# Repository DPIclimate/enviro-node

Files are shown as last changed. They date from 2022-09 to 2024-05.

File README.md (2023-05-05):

<h2 align="center">
    Enviro-Node
</h2>
<p align="center">
  <a href="#about">About</a> •
  <a href="https://dpiclimate.github.io/enviro-node" style="target-new: tab;">Documentation</a> •
  <a href="#hardware">Hardware</a> •
  <a href="#license">License</a>
</p>

<p align="center">
    
</p>

<!-- TABLE OF CONTENTS -->
<details>
  <summary>Table of Contents</summary>
  <ol>
    <li>
      <a href="#about">About</a>
    </li>
    <li>
      <a href="#hardware">Hardware</a>
      <ul>
        <li><a href="#microcontroller">Microcontroller</a></li>
        <li><a href="#debug-and-usb-interfaces">Debug and USB Interfaces</a></li>
        <li><a href="#power-distribution">Power Distribution</a></li>
        <ul>
            <li><a href="#battery">Battery</a></li>
            <li><a href="#solar">Solar</a></li>
            <li><a href="#3v3-interface">3V3 Interface</a></li>
            <li><a href="#12v-interface-for-sdi-12-devices">12 V Interface</a></li>
          </ul>
        <li><a href="#peripherals">Peripherals</a></li>
        <ul>
            <li><a href="#io-expander">IO Expander</a></li>
            <li><a href="#piezo-buzzer">Piezo Buzzer</a></li>
            <li><a href="#programmable-button">Programmable Button</a></li>
            <li><a href="#sd-card">SD-Card</a></li>
            <li><a href="#sdi-12">SDI-12</a></li>
            <li><a href="#digital">Digtial (Pulse Counter)</a></li>
        </ul>
        <li><a href="#cat-m1">CAT-M1</a></li>
      </ul>
    </li>
    <li>
      <a href="#firmware">Firmware</a>
    </li>
    <li><a href="#license">License</a></li>
  </ol>
</details>

## About

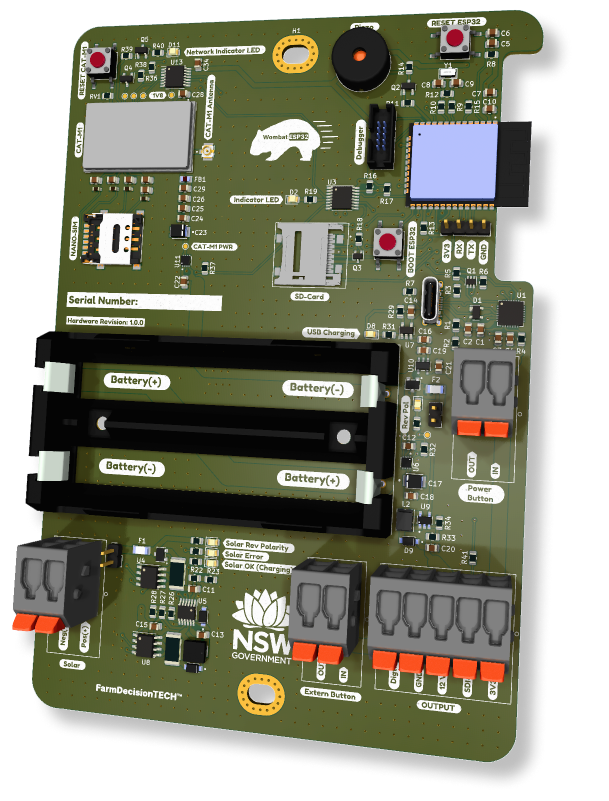
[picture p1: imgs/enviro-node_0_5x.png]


Enviro-node is a environmental monitoring node. Users can connect a number of sensors to a node. Data captured from these sensors is then sent to a database over [MQTT](https://mqtt.org/).

## Hardware

The hardware was developed using [KiCad](https://www.kicad.org/). Source files can be found [here](https://github.com/DPIclimate/enviro-node/tree/master/electronics/motherboard/motherboard-mini). While sleeping the Enviro-node will consume ~70 µA.

### Microcontroller
=> [Schematic](https://github.com/DPIclimate/enviro-node/blob/master/imgs/schematics/microcontroller.pdf)

The device incorporates a ESP32 microcontroller to handle bluetooth functions and peripherals. The ESP32 has a very low sleep current of ~16 µA making it perfect for low-powered applications.

### Debug and USB Interfaces
=> [Schematic](https://github.com/DPIclimate/enviro-node/blob/master/imgs/schematics/microcontroller.pdf)

Enviro-node features full debug capability when connected to an [ESP-Prog](https://espressif-docs.readthedocs-hosted.com/projects/espressif-esp-iot-solution/en/latest/hw-reference/ESP-Prog_guide.html) (ESP32 debugger/programmer). It is recommended that you use a USB-to-TTL cable during development. This allows you to have the ESP-Prog connected to the Enviro-node while monitoring the ESP32's serial output via the USB-to-TTL connector. 

The USB-C interface is only powered up when battery power is available. Do not attempt to power the board with the USB-C interface.

### Power Distribution 
=> [Schematic](https://github.com/DPIclimate/enviro-node/blob/master/imgs/schematics/power_distribution.pdf)

#### Battery

The Enviro-node is powered by two 18650 LiPo cells connected in parallel (4.2 V). A current jumper is available to monitor current and voltage on an external device such as a multi-meter. The batteries feature reverse polarity detection and protection and an inline fuse. 

An INA219 IC is connected to the battery to allow for real-time monitoring of battery current and voltage.

#### Solar

The batteries are recharged through a LT3652IMSE solar charging IC or via a USB-C battery charging IC (MCP73832). The default configuration allows for 12 V solar panels to be connected to the device; however, this can be set via a resistor divider.

The solar input features reverse polarity detection and protection as well as an inline fuse and charging/error indicators.

The charging current of the solar panel is limited to a maximum of 1 A and is monitored through another INA219 IC.

#### 3V3 Interface

Most components on Enviro-node operate using 3.3 V for this a linear regulator is incorporated (XC6215B332MR-G). A power supply switch is connected to the output of this regulator to allow the ESP32 (and peripherals) to be manually turned off or restarted.

#### 12V Interface for SDI-12 Devices

Although many SDI-12 devices will work with 3.3 V, the Enviro-node incorporates a 12 V step-up regulator (MIC2288YD5) to provide a stable 12 V (100 mA) supply. This IC can be toggled in the firmware via a GPIO pin and will be completely shutoff when not in use.

If a SDI-12 sensor requires a constant 12 V supply the current consumption of this step-up regulator is ~2 mA with no load.

### Peripherals
=> [Schematic](https://github.com/DPIclimate/enviro-node/blob/master/imgs/schematics/peripherals.pdf)

#### IO Expander

As a full debug interface is supplied and there are several operating interfaces (I<sub>2</sub>C, SPI, UART) the number of available GPIO pins on the ESP32
is limited. Therefore, an IO-expanded is provided (TCA9534) to control many IC's power consumption including CAT-M1, the SD-Card and 12 V power.

A LED is also connected the IO-expander that the user can configure.

#### Piezo Buzzer

For audible feedback a piezo buzzer is included and will play *success* and *error* tones while the device is being configured and on startup. Under normal conditions the piezo buzzer will be quiet.

#### Programmable Button

An external programmable button is connected to a GPIO input pin on the ESP32. On startup if this button is held down the device will enter a programmable state whereby BluetoothLE will be enabled and a UART CLI interface will become available. Once the user types "exit\r" the CLI will be exited and normal operations will continue.

#### SD-Card

Environmental monitoring requires a SD-Card to ensure data is captured even when communications are down. The Enviro-node provides a top entry, Micro-SD card slot that can be disconnected from its power supply via a GPIO pin (see IO-Expander above).

#### SDI-12

A full SDI-12 interface is provided. No level-shifting is incorporated as the ESP32 can handle 5 V. Users can either use the 12 V output and toggle the output on-and-off or use the 3.3 V output for always on devices.

#### Digital

A digital pin is provided to the user to count pulses originating from a Tipping Bucket or wind-speed sensor.

### CAT-M1
=> [Schematic](https://github.com/DPIclimate/enviro-node/blob/master/imgs/schematics/cat_m1.pdf)

The Enviro-node uses CAT-M1 to send messages (containing JSON encoded data) over MQTT. For this a SARA-R5 modem is incorporated into the design. This modem communicates with the ESP32 microcontroller over AT-commands via a Serial (UART) interface. 

> **Note** A compatible nano-sim card is required for this functionality of the device. For Australian users [Telstra](https://telstra.m2m.com/) has a M2M service or there are other global services such as [Hologram](https://www.hologram.io/products/global-iot-sim-card/).

The modem is directly powered by the 18650 batteries (as the modem can draw ~500 mA) and can be turned off and on via a GPIO pin (see IO-Expander above). A network indicator LED will indicate network registration status.

## Firmware

The firmware source code is located in the <a href="firmware/wombat">firmware/wombat</a> directory. It is structured as a platformio project.

### Installing platformio and the Wombat board files

The <a href="firmware/wombat/install_pio.sh">install_pio.sh</a> script will install platformio and copy the Wombat board files into the installation.

After running the script and adding `~/.platformio/penv/bin` to the PATH, the firmware can be compiled with the command `pio run`.

## License

This project is MIT licensed, as found in the LICENCE file.

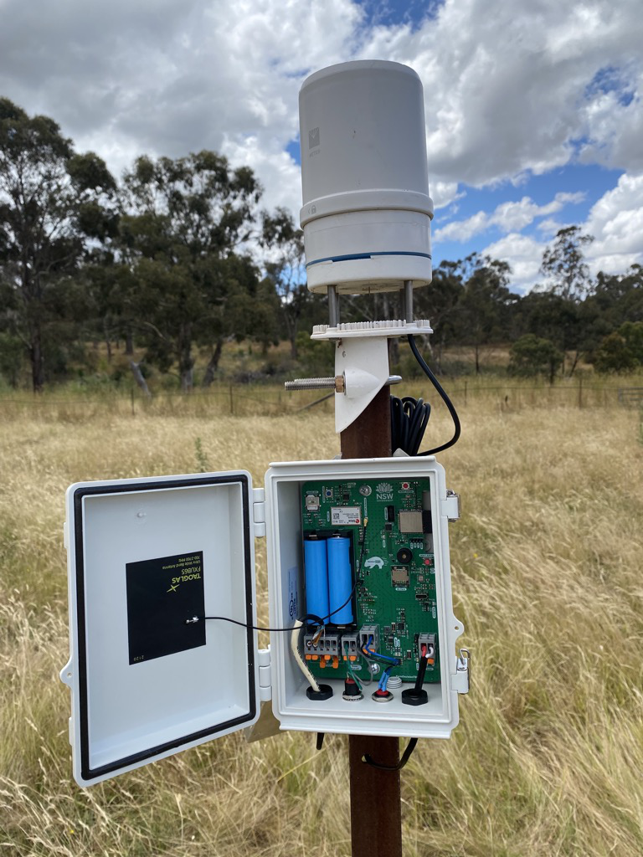
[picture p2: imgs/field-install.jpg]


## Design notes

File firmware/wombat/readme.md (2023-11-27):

# Wombat Firmware

## Overview

The Wombat is a simple data logger whose basic runtime sequence is:

1. Connect to the internet and use NTP to set the time.
2. Read the solar and battery bus voltages.
3. Read all attached SDI-12 sensors with addresses in the range of 0 - 9.
4. Read and reset the pulse count from the `Digital` input.
5. Create a JSON message with these values, plus miscellaneous node information such as the SIM card CCID, basic mobile signal strength, serial number, firmware version etc.
6. Append the message to the `data.json` file on the SD card if the card is present.
7. Write the message to a file on the ESP-32 SPIFFS filesystem.
8. If this is an uplink cycle, send all messages found on the SPIFFS filesystem to an MQTT broker.
9. If a configuration script was received from the MQTT broker, run it.
10. Enter deep sleep until the next measurement cycle.

The firmware is written using the [ESP-32 Arduino platform](https://docs.espressif.com/projects/arduino-esp32/en/latest/getting_started.html)
because Arduino libraries are used. [PlatformIO](https://platformio.org/) is used for building.

The Wombat currently has a 1024 byte limit on the length of the telemetry message. This is sufficient for current
deployments.

## Command Line Interface

Wombats are configured using a command line interface (CLI). This is available via a UART or by publishing a script to
an MQTT topic.

After the output from most commands, the Wombat will print `OK` on success or `ERROR: [optional message]` if a command
fails. The OK/ERROR string is printed on a new line delimited by CRLF, for example: `\r\nOK\r\n`.

## Access the CLI via the USB-C port

To use the command line via the UART header or USB-C port on the Wombat, short the `External Button` header while
rebooting.

The USB-C port does not have both sets of data pins connected, so try the USB-C cable in both orientations.

## Access the CLI via the UART header

The UART header (located just under the ESP32 module) can be used to print console messages from the Wombat. Log
messages are transmitted via the TX.

To enable the RX pin so commands can be entered, break the solder jumper `JP1` on the back of the PCB.

> WARNING: While this jumper is broken the USB-C port will not accept commands, but it will still emit log messages.

## Send CLI commands via MQTT

A Wombat checks for a configuration scrip every time it connects to the MQTT server, using its serial number as the
in the topic name. For example, if the boot messages show:

```text
[    39][I][main.cpp:135] timeout_task(): [wombat] Starting
[  1307][I][DeviceConfig.cpp:66] reset(): [config] Resetting values to defaults
[  1308][I][DeviceConfig.cpp:72] reset(): [config] Node Id: B8D61A017074
[  1310][I][main.cpp:194] setup(): [wombat] Wake up time: 1970-01-01T00:00:18Z
```

then the `Node Id` is `B8D61A017074` and the topic the Wombat will read commands from is `wombat/B8D61A017074`.

If a configuration script is found, the Wombat downloads it and publishes an empty message to the topic to clear the
script.

Configuration scripts must the published as a retained message, meaning the message will persist in the topic until a
new retained message is written to the topic. To clear the configuration script from the topic, an empty message is
published by the Wombat after receiving the configuration script.

> Some commands should not be used in configuration scripts. These commands are marked with `[CLI only]` in the command
> reference below.

Below is an excerpt of the logging messages showing the downloading and clearing of a configuration script from the
MQTT server.

```text
AT+UMQTTC=1

OK
[1884670][I][mqtt_stack.cpp:20] mqttCmdCallback(): [mqtt_stack] cmd: 1, result: 1
[1884697][I][Utils.h:73] hasURC(): [CommandURCVector] valid = 1, command = 1, result = 1, err1 = 0, err2 = 0
[1884715][I][Utils.h:101] waitForURC(): [CommandURCVector] command = 1, result = 1, found_urc = 1, retries = 59
[1884751][I][mqtt_stack.cpp:86] mqtt_login(): [mqtt_stack] Connected to MQTT
AT+UMQTTC=4,1,"wombat/B8D61A017074"

OK
[1884759][I][mqtt_stack.cpp:105] mqtt_login(): [mqtt_stack] Checking for a config script, waiting for subscribe URC
[1885466][I][mqtt_stack.cpp:20] mqttCmdCallback(): [mqtt_stack] cmd: 4, result: 1
[1885485][I][mqtt_stack.cpp:20] mqttCmdCallback(): [mqtt_stack] cmd: 6, result: 1
[1885503][I][Utils.h:73] hasURC(): [CommandURCVector] valid = 1, command = 4, result = 1, err1 = 0, err2 = 0
[1885521][I][Utils.h:101] waitForURC(): [CommandURCVector] command = 4, result = 1, found_urc = 1, retries = 23
[1885539][I][mqtt_stack.cpp:109] mqtt_login(): [mqtt_stack] out of sub urc loop, checking values: result = 1
[1885561][I][Utils.h:73] hasURC(): [CommandURCVector] valid = 1, command = 6, result = 1, err1 = 0, err2 = 0
[1885580][I][Utils.h:101] waitForURC(): [CommandURCVector] command = 6, result = 1, found_urc = 1, retries = 20
[1885598][I][mqtt_stack.cpp:118] mqtt_login(): [mqtt_stack] out of read urc loop, result = 1
[1885616][I][mqtt_stack.cpp:122] mqtt_login(): [mqtt_stack] Config download waiting.
AT+UMQTTC=6,1

+UMQTTC: 6,1,59,19,"wombat/B8D61A017074",40,"ftp login
ftp upload log.txt
ftp logout
"

OK
AT+UMQTTC=2,0,1,0,"wombat/B8D61A017074",""
15:23:26.063 >
OK
```

### Example scripts

A script to upload the data and log files, and then clear the log file:

```
ftp login
ftp upload data.json
ftp upload log.txt
ftp logout
sd rm log.txt
```

A script unconditionally update the firmware and reboot to quickly get a message with the new firmware version
identifier:

```text
config ota 1
config reboot
```

## Command Reference

### config

#### config list

The `config list` command lists various configuration settings as a set of configuration commands that can be pasted
into another Wombats CLI to copy the configuration.

```text
$ config list
interval measure 900
interval uplink 900
interval clockmult 1.0
mqtt host mqtt_server.example.com
mqtt port 1883
mqtt user mqtt_username
mqtt password mqtt_password_in_cleartext
mqtt topic wombat
ftp host ftp_server.example.com
ftp user ftp
ftp password ftp_password_in_cleartext

OK
$
```

#### config save

Saves the configuration to non-volatile storage.

#### config load

Loads the Wombat configuration from non-volatile storage. The configuration must have been saved previously.

#### config dto `[CLI only]`

Disables the 60-minute timeout that will reboot the Wombat if it is still running. This timeout is enabled by default.

#### config eto `[CLI only]`

Enables the 60-minute timeout that will reboot the Wombat if it is still running. This timeout is enabled by default.

#### config ota

Triggers an over-the-air update. By default, this command checks the version on FTP the server and only downloads it if
it is newer than what is running on the Wombat. This can be over-ridden by supplying an argument of '1'.

Example: `config ota 1` force an update of the firmware.

#### config sdi12defn

Downloads the [sdi12defn.json](data/sdi12defn.json) file from the FTP server. No version checking is done, the file is always downloaded and
replaces what is currently on the Wombat.

> See [SDI-12 Sensor Definitions](#sdi-12-sensor-definitions)

#### config reboot

Performs a clean shutdown and reboots the Wombat.

### interval

#### interval list

Lists the interval settings as a set of configuration commands that can be pasted
into another Wombats CLI to copy the configuration.

```text
interval measure 900
interval uplink 900
interval clockmult 1.0
```

#### interval measure

Sets the interval, in seconds, that the Wombat will wake up and record data from the sensors.

Example: `interval measure 900` takes measurements every 15 minutes.

#### interval uplink

Sets the interval, in seconds, that the Wombat will upload data to the MQTT broker. This must be a multiple of
the measurement interval.

Example: `interval uplink 3600` uploads data every hour.

#### interval clockmult

Sets the coefficient used to adjust the sleep time if clock drift is a problem. The time to sleep is calculated in
milliseconds, converted to micro-seconds, and this coefficient is applied to the microsecond value.

Example: `interval clockmult 1.006`

### power

#### power show

Prints the solar and battery voltages.

### sd - work with the SD card

#### sd rm

Deletes a file from the SD card. All files are in the root directory and need no prefix on the name. Only two files
exist on the SD card, `data.json` and `log.txt`. No quotes are required around the filename. Only a single filename may
be supplied.

Example: `sd rm log.txt` will delete the log file.

#### sd data `[CLI only]`

Prints the `data.json` file to the console. The contents are surrounded by `[` and `]` to make it a JSON array.

#### sd log `[CLI only]`

Prints the `log.txt` file to the console.

### sdi12 - work with SDI-12 sensors

#### sdi12 scan

Scans the SDI-12 bus, prints the sensors found and populates the SDI-12 sensor data structure.

#### sdi12 m `[CLI only]`

Performs a measurement on an SDI-12 sensor with the supplied address. If the type of the sensor is in the
`sdi12defns.json` file then the commands and field mask in that file are used, otherwise a measure command is used and
all values are printed.

Example: `sdi12 m 1` reads SDI-12 sensor with address 1 and prints the values.

#### sdi12 >>

Sends a command to the SDI-12 bus and prints the response. The whole argument to this command is sent as the SDI-12
command.

Example: `sdi12 >> 0A8!` changes the address of sensor 0 to 8.

#### sdi12 pt `[CLI only]`

Enters SDI-12 passthrough mode. In this mode all characters typed are sent directly to the SDI-12 bus and all
characters received from the bus are printed to the console.

Exit passthrough mode with ctrl-D.

### c1 - work with the Cat-M1 modem

#### c1 pwr `[CLI only]`

Switches power to the modem on or off. The modem is switched off by default and must be powered before it can be used.
When testing the Wombat from the command line and wanting to use the modem, issue `c1 pwr 1` to supply power to the
modem. `c1 pwr 0` will remove power from the modem, and will issue a power off AT command if a previous `c1 cti`
command was successful.

Example: `c1 pwr 1` switches on the modem power bus.

#### c1 cti `[CLI only]`

Attempts to connect the Wombat to the internet. Will also get the time via NTP. This command will enable power to the
modem the first time it is run.

#### c1 ls

Lists files on the modem filesystem.

#### c1 rm

Deletes a file from the modem filesystem. No quotes are required around the filename. Only a single filename may be
supplied.

Example: `c1 rm wombat.sha1` removes the `wombat.sha1` file from the modem filesystem.

#### c1 factory `[CLI only]`

Attempts to reset the modem to factory defaults using the `AT+UFACTORY=2,2` command.

#### c1 ntp

Issues an NTP request to set the RTC of the Wombat.

#### c1 ok

Issues an `ATI` command and prints the response as a basic modem UART test.

#### c1 pt `[CLI only]`

Enters passthrough mode on the modem UART. In this mode all characters typed are sent directly to the modem and all
characters received from the modem are printed to the console.

Exit passthrough mode with ctrl-D.

### mqtt

#### mqtt list

Lists the MQTT settings as a set of configuration commands that can be pasted
into another Wombats CLI to copy the configuration.

#### mqtt host

Sets the MQTT hostname. A hostname or IPv4 address can be used.

Example: `mqtt hostname mqtt.example.com`

#### mqtt port

Sets the MQTT port number. Must be an integer.

Example: `mqtt port 1883`

#### mqtt user

Sets the MQTT username.

Example: `mqtt user example_user`

#### mqtt password

Sets the MQTT password.

Example: `mqtt password an_example_password`

#### mqtt topic

Sets the name of the topic that test messages sent via `mqtt publish` are published to. Note this setting has no
impact on messages sent from the usual running of the Wombat.

Example: `mqtt topic test_topic`

#### mqtt login

Attempt to log in to a MQTT server using the current configuration settings.

#### mqtt logout

Log out of the MQTT server.

#### mqtt publish

Publish a test message to the MQTT server. The message content is 'ABCDEF' and is published to the topic set with
`mqtt topic`.

### ftp

#### ftp list

Lists the FTP settings as a set of configuration commands that can be pasted
into another Wombats CLI to copy the configuration.

#### ftp host

Sets the FTP hostname. A hostname or IPv4 address can be used.

Example: `ftp hostname ftp.example.com`

#### ftp user

Sets the FTP username.

Example: `ftp user example_user`

#### ftp password

Sets the FTP password.

Example: `ftp password an_example_password`

#### ftp login

Attempt to log in to a FTP server using the current configuration settings.

#### ftp logout

Log out of the FTP server.

#### ftp get

Get a file from the FTP server. The file must be in the root directory of the FTP server.

No quotes are necessary around the filename, and only a single filename is accepted. No whitespace is allowed in the
filename.

The file is written to the modem filesystem.

Example: `ftp get wombat.sha1`

#### ftp upload

Uploads a file from the SD card to the FTP server. The file is written to a directory named `uploads/node_SERIALNO`
where SERIALNO is the Wombat serial number.

No quotes are necessary around the filename, and only a single filename is accepted. No whitespace is allowed in the
filename.

Example: `ftp upload log.txt`

## SDI-12 sensors

### The SDI-12 Bus

Up to 10 SDI-12 sensors may be connected to the Wombat using addresses 0 - 9.

When the Wombat boots it scans the SDI-12 bus for sensors on these addresses and builds a list of the sensors found.
Every sensor on the list is read during the measurement cycle.

SDI-12 Sensors are connected to the `OUTPUT` header and may be powered via the `3V3` line or the `12 V` line. The `3V3`
is powered as long as the batteries are connected via the `Power Button` header, including when the Wombat is asleep.
All SDI-12 sensor data wires must be connected to the `SDI-12` line.

The always-on `3V3` line is useful for sensors such as automatic weather stations which must be always on for recording
rain and wind events.

The `12 V` line is only powered while the Wombat is awake.

### SDI-12 Sensor Definitions

If a file named [`sdi12defns.json`](data/sdi12defn.json) exists on the ESP-32 SPIFFS filesystem, it will be used to
determine which commands to use when reading data from SDI-12 sensors, what labels to give the values, and to
filter unwanted values.

The general layout of the file is:

```json
{
  "vendor": {
    "model": {
      "read_cmds": [ cmd1, ... ],
      "value_mask": "10110",
      "labels": [ "Field_1", ... ],
      "ignore_sr": true
    }
  }
}
```
where:

| Field | Description |
|---|---|
| vendor | The vendor identifier returned by the sensor in the response to an identify command. |
| model | The sensor model identifier returned by the sensor in the response to an identify command. |
| read_cmds  | A list of commands to send to read values. The command must start with `a`, a placeholder for the sensor address,  and end with `!`. For example: `"aC!"` or `"aC2!"`. |
| value_mask | Optional - a string of `0` and `1` which can be used to mask out unwanted values. Use `0` to drop a value. For example: `"110"` drops the 3rd value read from the sensor. |
| labels | A list of names to give the values in the telemetry message. The names are prefixed with the sensor address, so a name of `"Temperature"` will appear in the message as `"1_Temperature"` if it is read from sensor address 1. |
| ignore_sr | Optional - a boolean that can be used to tell the Wombat to always wait for the full length of time the sensor claimed a measurement will take. The Wombat will read and ignore the service request from the sensor. |

> If a sensor definition cannot be found for a sensor, the Wombat issues a basic measure command `aM!`, and labels the
> values `"a_Vn"` where `a` is the sensor address and `n` is the number of the value, from 0 to *n-1* where *n* is the
> number of values read back from the sensor. For example, a temperature and humidity sensor at address 5 would have
> values labelled `5_V0` and `5_V1`.

A new version of the `sdi12defns.json` file can be downloaded from the root directory of the FTP server using the
`config sdi12dfns` command.

## Firmware Updates

The firmware can be updated over-the-air via the `config ota` command.

A binary image named `wombat.bin` and an information file named `wombat.sha1` must must be present in the root
directory of the FTP server.

The information file contains a single line of text with the following fields:

```text
version length firmware-image-sha1-sig git-commit-id
```

for example:

```text
1.0.7 546064 4efb177a5d132ed22e9f045f03e61b9a1d85cacd 7b5b8c08f67312f4c587a83316fbbdc911a5df6d
```

This file is generated by the [split_firmware.sh](split_firmware.sh) script, which is run by [scp_firmware.sh](scp_firmware.sh).

### Uploading Firmware to the FTP Server

The [scp_firmware.sh](scp_firmware.sh) script is used to generate the information file and upload both it and the
firmware image to an FTP server. Note the script uses SSH to copy the files, not FTP.

Two environment variables are used by the script:

| Environment variable | Description |
|---|---|
| SSH_HOST | This variable is expected to contain an SSH host identifier from the ~/.ssh/config file. It may work to set it to something like `-i ~/.ssh/my_key user@host` but this has not been tested. |
| DEST_DIR | The directory on the host to copy the files to. This must equate to the FTP server root directory, for example `/srv/ftp`. |

> The script must be run from the `src/firmware/wombat` directory.

### Requesting a Firmware Update

Issuing a `config ota` command will cause the Wombat to log in to the FTP server, download the `wombat.sha1` file and
use this to check if the software on the server is newer than what is running on the Wombat. If so, the Wombat
downloads and installs the new firmware image and switches over on the next boot.

To force a firmware update issue the `config ota 1` command. This is useful during development when the version number
of the firmware is not changing, or perhaps to downgrade the firmware.

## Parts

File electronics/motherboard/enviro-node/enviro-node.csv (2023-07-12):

Source: | /Users/dtaylor/tmp/enviro-node/electronics/motherboard/enviro-node/enviro-node.kicad_sch
Date: | Wednesday, 19 April 2023 at 02:27:09 pm
Tool: | Eeschema (6.0.11-0)
Generator: | /Applications/KiCad/KiCad.app/Contents/SharedSupport/plugins/bom_csv_grouped_by_value.py
Component Count: | 141
Individual Components:
Item | Qty | Reference(s) | Value | LibPart | Footprint | Datasheet | AVAILABILITY | DESCRIPTION | MANUFACTURER | MAXIMUM_PACKAGE_HEIGHT | MF | MP | PACKAGE | PARTREV | PRICE | Part | SNAPEDA_PACKAGE_ID | STANDARD
 |  | B1 | 1049P | 1049P:1049P | 1049P:1049P
 |  | C3 | 0.1uF | Device:C | Capacitor_SMD:C_0805_2012Metric | https://www.digikey.com.au/en/products/detail/yageo/AC0805KRX7R7BB104/6643148 |  |  |  |  |  |  |  |  |  | AC0805KRX7R7BB104
 |  | C4 | 4.7uF | Device:C | Capacitor_SMD:C_0805_2012Metric | https://www.digikey.com.au/en/products/detail/samsung-electro-mechanics/CL21B475KOFNFNE/3888628 |  |  |  |  |  |  |  |  |  | CL21B475KOFNFNE
 |  | C5 | 1uF | Device:C | Capacitor_SMD:C_0805_2012Metric | https://www.digikey.com.au/en/products/detail/kemet/C0805C105K3RAC7800/2211765 |  |  |  |  |  |  |  |  |  | C0805C105K3RAC7800
 |  | C6 | 0.1uF | Device:C | Capacitor_SMD:C_0805_2012Metric | https://www.digikey.com.au/en/products/detail/yageo/AC0805KRX7R7BB104/6643148 |  |  |  |  |  |  |  |  |  | AC0805KRX7R7BB104
 |  | C7 | 0.1uF | Device:C | Capacitor_SMD:C_0805_2012Metric | https://www.digikey.com.au/en/products/detail/yageo/AC0805KRX7R7BB104/6643148 |  |  |  |  |  |  |  |  |  | AC0805KRX7R7BB104
 |  | C8 | 12pF | Device:C | Capacitor_SMD:C_0805_2012Metric | https://www.digikey.com.au/en/products/detail/vishay-vitramon/VJ0805A120FXJCW1BC/8307136 |  |  |  |  |  |  |  |  |  | VJ0805A120FXJCW1BC
 |  | C9 | 12pF | Device:C | Capacitor_SMD:C_0805_2012Metric | https://www.digikey.com.au/en/products/detail/vishay-vitramon/VJ0805A120FXJCW1BC/8307136 |  |  |  |  |  |  |  |  |  | VJ0805A120FXJCW1BC
 |  | C10 | 22uF | Device:C | Capacitor_SMD:C_0805_2012Metric | https://www.digikey.com.au/en/products/detail/kemet/C0805C226M8PAC7800/5327667 |  |  |  |  |  |  |  |  |  | C0805C226M8PAC7800
 |  | C11 | 10uF | Device:C | Capacitor_SMD:C_0805_2012Metric | https://www.digikey.com.au/en/products/detail/tdk-corporation/C2012X5R1V106K125AC/3951654 |  |  |  |  |  |  |  |  |  | C2012X5R1V106K125AC
 |  | C12 | 1uF | Device:C | Capacitor_SMD:C_0805_2012Metric | https://www.digikey.com.au/en/products/detail/kemet/C0805C105K3RAC7800/2211765 |  |  |  |  |  |  |  |  |  | C0805C105K3RAC7800
 |  | C13 | 1uF | Device:C | Capacitor_SMD:C_0805_2012Metric | https://www.digikey.com.au/en/products/detail/kemet/C0805C105K3RAC7800/2211765 |  |  |  |  |  |  |  |  |  | C0805C105K3RAC7800
 |  | C14 | 4.7uF | Device:C | Capacitor_SMD:C_0805_2012Metric | https://www.digikey.com.au/en/products/detail/samsung-electro-mechanics/CL21B475KOFNFNE/3888628 |  |  |  |  |  |  |  |  |  | CL21B475KOFNFNE
 |  | C15 | 10uF | Device:C | Capacitor_SMD:C_0805_2012Metric | https://www.digikey.com.au/en/products/detail/tdk-corporation/C2012X5R1V106K125AC/3951654 |  |  |  |  |  |  |  |  |  | C2012X5R1V106K125AC
 |  | C16 | 4.7uF | Device:C | Capacitor_SMD:C_0805_2012Metric | https://www.digikey.com.au/en/products/detail/samsung-electro-mechanics/CL21B475KOFNFNE/3888628 |  |  |  |  |  |  |  |  |  | CL21B475KOFNFNE
 |  | C17 | 0.1uF | T520B107M006ATE015:T520B107M006ATE015 | Capacitor_Tantalum_SMD:CP_EIA-2012-12_Kemet-R | https://datasheets.kyocera-avx.com/TAJ.pdf |  |  | KYOCERA-AVX |  |  |  |  |  |  | TAJR104K020RNJ |  | IPC-7351B
 |  | C18 | 2.2uF | Device:C | Capacitor_SMD:C_0805_2012Metric | https://www.digikey.com.au/en/products/detail/kemet/C0805C225M3RAC7800/5267532 |  |  |  |  |  |  |  |  |  | C0805C225M3RAC7800
 |  | C19 | 1uF | Device:C | Capacitor_SMD:C_0805_2012Metric | https://www.digikey.com.au/en/products/detail/kemet/C0805C105K3RAC7800/2211765 |  |  |  |  |  |  |  |  |  | C0805C105K3RAC7800
 |  | C20 | 10uF | Device:C | Capacitor_SMD:C_0805_2012Metric | https://www.digikey.com.au/en/products/detail/tdk-corporation/C2012X5R1V106K125AC/3951654 |  |  |  |  |  |  |  |  |  | C2012X5R1V106K125AC
 |  | C21 | 0.1uF | Device:C | Capacitor_SMD:C_0805_2012Metric | https://www.digikey.com.au/en/products/detail/yageo/AC0805KRX7R7BB104/6643148 |  |  |  |  |  |  |  |  |  | AC0805KRX7R7BB104
 |  | C22 | 1uF | Device:C | Capacitor_SMD:C_0805_2012Metric | https://www.digikey.com.au/en/products/detail/kemet/C0805C105K3RAC7800/2211765 |  |  |  |  |  |  |  |  |  | C0805C105K3RAC7800
 |  | C23 | 0.1uF | T520B107M006ATE015:T520B107M006ATE015 | Capacitor_Tantalum_SMD:CP_EIA-2012-12_Kemet-R | https://datasheets.kyocera-avx.com/TAJ.pdf |  |  | KYOCERA-AVX |  |  |  |  |  |  | TAJR104K020RNJ |  | IPC-7351B
 |  | C24 | 0.1uF | Device:C | Capacitor_SMD:C_0805_2012Metric | https://www.digikey.com.au/en/products/detail/yageo/AC0805KRX7R7BB104/6643148 |  |  |  |  |  |  |  |  |  | AC0805KRX7R7BB104
 |  | C25 | 10nF | Device:C | Capacitor_SMD:C_0805_2012Metric | https://www.digikey.com.au/en/products/detail/kemet/C0805C103J5GEC7210/8645966 |  |  |  |  |  |  |  |  |  | C0805C103J5GEC7210
 |  | C26 | 68pF | Device:C | Capacitor_SMD:C_0805_2012Metric | https://www.digikey.com.au/en/products/detail/kemet/C0805C680K5RACAUTO/11677006 |  |  |  |  |  |  |  |  |  | C0805C680K5RACAUTO
 |  | C27 | 47pF | Device:C | Capacitor_SMD:C_0805_2012Metric | https://www.digikey.com.au/en/products/detail/kemet/C0805C470K5RAC7800/12701183 |  |  |  |  |  |  |  |  |  | C0805C470K5RAC7800
 |  | C28 | 0.1uF | Device:C | Capacitor_SMD:C_0805_2012Metric | https://www.digikey.com.au/en/products/detail/yageo/AC0805KRX7R7BB104/6643148 |  |  |  |  |  |  |  |  |  | AC0805KRX7R7BB104
 |  | C29 | 15pF | Device:C | Capacitor_SMD:C_0805_2012Metric | https://www.digikey.com.au/en/products/detail/kemet/C0805C150J3GAC7800/2211923 |  |  |  |  |  |  |  |  |  | C0805C150J3GAC7800
 |  | C30 | 47pF | Device:C | Capacitor_SMD:C_0805_2012Metric | https://www.digikey.com.au/en/products/detail/kemet/C0805C470K5RAC7800/12701183 |  |  |  |  |  |  |  |  |  | C0805C470K5RAC7800
 |  | C31 | 47pF | Device:C | Capacitor_SMD:C_0805_2012Metric | https://www.digikey.com.au/en/products/detail/kemet/C0805C470K5RAC7800/12701183 |  |  |  |  |  |  |  |  |  | C0805C470K5RAC7800
 |  | C32 | 47pF | Device:C | Capacitor_SMD:C_0805_2012Metric | https://www.digikey.com.au/en/products/detail/kemet/C0805C470K5RAC7800/12701183 |  |  |  |  |  |  |  |  |  | C0805C470K5RAC7800
 |  | C33 | 0.1uF | Device:C | Capacitor_SMD:C_0805_2012Metric | https://www.digikey.com.au/en/products/detail/yageo/AC0805KRX7R7BB104/6643148 |  |  |  |  |  |  |  |  |  | AC0805KRX7R7BB104
 |  | C34 | 0.1uF | Device:C | Capacitor_SMD:C_0805_2012Metric | https://www.digikey.com.au/en/products/detail/yageo/AC0805KRX7R7BB104/6643148 |  |  |  |  |  |  |  |  |  | AC0805KRX7R7BB104
 |  | CR1 | PESD0402-140 | PESD0402-140:PESD0402-140 | PESD0402-140:PESD0402-140 | https://www.digikey.com.au/en/products/detail/littelfuse-inc/PESD0402-140/1968525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 |  |  |  |  |  |  |  |  |  | PESD0402-140
 |  | CR2 | PESD0402-140 | PESD0402-140:PESD0402-140 | PESD0402-140:PESD0402-140 | https://www.digikey.com.au/en/products/detail/littelfuse-inc/PESD0402-140/1968525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 |  |  |  |  |  |  |  |  |  | PESD0402-140
 |  | CR3 | PESD0402-140 | PESD0402-140:PESD0402-140 | PESD0402-140:PESD0402-140 | https://www.digikey.com.au/en/products/detail/littelfuse-inc/PESD0402-140/1968525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 |  |  |  |  |  |  |  |  |  | PESD0402-140
 |  | CR4 | PESD0402-140 | PESD0402-140:PESD0402-140 | PESD0402-140:PESD0402-140 | https://www.digikey.com.au/en/products/detail/littelfuse-inc/PESD0402-140/1968525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 |  |  |  |  |  |  |  |  |  | PESD0402-140
 |  | D1 | SP0503BAHT | Power_Protection:SP0503BAHT | Package_TO_SOT_SMD:SOT-143 | http://www.littelfuse.com/~/media/files/littelfuse/technical%20resources/documents/data%20sheets/sp05xxba.pdf
 |  | D2 | LED(Orange) | Device:LED | LED_SMD:LED_0805_2012Metric | https://www.digikey.com.au/en/products/detail/osram-opto-ams-osram/LO-R976-PS-1/1227955 |  |  |  |  |  |  |  |  |  | LO R976-PS-1
 |  | D3 | LED(Red) | Device:LED | LED_SMD:LED_0805_2012Metric | https://www.digikey.com.au/en/products/detail/osram-opto-ams-osram/LS-R976-NR-1/1227987 |  |  |  |  |  |  |  |  |  | LS R976-NR-1
 |  | D4 | LED(Green) | Device:LED | LED_SMD:LED_0805_2012Metric | https://www.digikey.com.au/en/products/detail/osram-opto-ams-osram/LG-R971-KN-1/1227925 |  |  |  |  |  |  |  |  |  | LG R971-KN-1
 |  | D5 | LED(Red) | Device:LED | LED_SMD:LED_0805_2012Metric | https://www.digikey.com.au/en/products/detail/osram-opto-ams-osram/LS-R976-NR-1/1227987 |  |  |  |  |  |  |  |  |  | LS R976-NR-1
 |  | D6 | SS34LW_RVG | SS34LW_RVG:SS34LW_RVG | SS34LW_RVG:SODFL3718X102N | https://www.digikey.com.au/en/products/detail/taiwan-semiconductor-corporation/SS34LW/7359612 |  |  | Taiwan Semiconductor | 1.02 mm |  |  |  | C2103 |  | SS34LW_RVG |  | IPC-7351B
 |  | D7 | SS34LW_RVG | SS34LW_RVG:SS34LW_RVG | SS34LW_RVG:SODFL3718X102N | https://www.digikey.com.au/en/products/detail/taiwan-semiconductor-corporation/SS34LW/7359612 |  |  | Taiwan Semiconductor | 1.02 mm |  |  |  | C2103 |  | SS34LW_RVG |  | IPC-7351B
 |  | D8 | LED(Green) | Device:LED | LED_SMD:LED_0805_2012Metric | https://www.digikey.com.au/en/products/detail/osram-opto-ams-osram/LG-R971-KN-1/1227925 |  |  |  |  |  |  |  |  |  | LG R971-KN-1
 |  | D9 | SS34LW_RVG | SS34LW_RVG:SS34LW_RVG | SS34LW_RVG:SODFL3718X102N | https://www.digikey.com.au/en/products/detail/taiwan-semiconductor-corporation/SS34LW/7359612 |  |  | Taiwan Semiconductor | 1.02 mm |  |  |  | C2103 |  | SS34LW_RVG |  | IPC-7351B
 |  | D10 | LED(Red) | Device:LED | LED_SMD:LED_0805_2012Metric | https://www.digikey.com.au/en/products/detail/osram-opto-ams-osram/LS-R976-NR-1/1227987 |  |  |  |  |  |  |  |  |  | LS R976-NR-1
 |  | D11 | LED(Orange) | Device:LED | LED_SMD:LED_0805_2012Metric | https://www.digikey.com.au/en/products/detail/osram-opto-ams-osram/LO-R976-PS-1/1227955 |  |  |  |  |  |  |  |  |  | LO R976-PS-1
 |  | F1 | 0685P2000-01 | 0685P2000-01:0685P2000-01 | 0685P2000-01:0685P2000-01 | https://www.digikey.com.au/en/products/detail/bel-fuse-inc/0685P2000-01/12140901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 |  |  | BELFUSE | 0.83mm |  |  |  | Jan2019 |  | 0685P2000-01 |  | IPC-7351B
 |  | F2 | 0685P2000-01 | 0685P2000-01:0685P2000-01 | 0685P2000-01:0685P2000-01 | https://www.digikey.com.au/en/products/detail/bel-fuse-inc/0685P2000-01/12140901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 |  |  | BELFUSE | 0.83mm |  |  |  | Jan2019 |  | 0685P2000-01 |  | IPC-7351B
 |  | FB1 | FBMH2012HM221-TV | FBMH2012HM221-TV:FBMH2012HM221-TV | FBMH2012HM221-TV:BEADC2012X105N | https://www.digikey.com.au/en/products/detail/taiyo-yuden/FBMH2012HM221-TV/4875427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 |  |  |  |  |  |  |  |  |  | FBMH2012HM221-TV
 |  | H1 | MountingHole | Mechanical:MountingHole | MountingHole:MountingHole_4.3x6.2mm_M4_Pad_Via | ~
 |  | H2 | MountingHole | Mechanical:MountingHole | MountingHole:MountingHole_4.3x6.2mm_M4_Pad_Via | ~
 |  | J1 | USB4145-03-0230-C | USB4070-30-C:USB4070-30-C_REVC5 | USB4145-03-0230-C_REVA:GCT_USB4145-03-0230-C_REVA | https://gct.co/files/drawings/usb4145.pdf |  |  | GCT | 10.8mm |  |  |  | C5 |  |  |  | Manufacturer Recommendations
 |  | J2 | JTAG | Connector_Generic:Conn_01x04 | Connector_PinHeader_2.54mm:PinHeader_1x04_P2.54mm_Vertical | ~
 |  | J3 | JTAG | Connector:Conn_ARM_JTAG_SWD_10 | 3221-10-0100-00:CNC_3221-10-0100-00 | http://infocenter.arm.com/help/topic/com.arm.doc.ddi0314h/DDI0314H_coresight_components_trm.pdf |  |  |  |  |  |  |  |  |  | 3221-10-0100-00
 |  | J4 | 2604-3102 | 2604-3102:2604-3102 | 2604-3102:2604-3102 | https://www.digikey.com.au/en/products/detail/wago-corporation/2604-3102/15528152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 |  |  |  |  |  |  |  |  |  | 2604-3102
 |  | J5 | ST1W008S4AR1500 | ST1W008S4AR1500:ST1W008S4AR1500 | ST1W008S4AR1500:JAE_ST1W008S4AR1500 | https://www.digikey.com.au/en/products/detail/jae-electronics/ST1W008S4AR1500/3720055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 |  |  | JAE Electronics | 2.0 mm |  |  |  | 2 |  | ST1W008S4AR1500 |  | Manufacturer Recommendations
 |  | J6 | 2604-3105 | 2604-3105:2604-3105 | 2604-3105:2604-3105 | https://www.digikey.com.au/en/products/detail/wago-corporation/2604-3105/15551087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 |  |  |  |  |  |  |  |  |  | 2604-3105
 |  | J7 | 2604-3102 | 2604-3102:2604-3102 | 2604-3102:2604-3102 | https://www.digikey.com.au/en/products/detail/wago-corporation/2604-3102/15528152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 |  |  |  |  |  |  |  |  |  | 2604-3102
 |  | J8 | SOLAR_CRNT_JMPR | Connector:Conn_01x02_Male | Connector_PinHeader_2.54mm:PinHeader_1x02_P2.54mm_Vertical | ~
 |  | J9 | BAT_CRNT_JMPR | Connector:Conn_01x02_Male | Connector_PinHeader_2.54mm:PinHeader_1x02_P2.54mm_Vertical | ~
 |  | J10 | 2604-3102 | 2604-3102:2604-3102 | 2604-3102:2604-3102 | https://www.digikey.com.au/en/products/detail/wago-corporation/2604-3102/15528152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 |  |  |  |  |  |  |  |  |  | 2604-3102
 |  | J11 | CONUFL001-SMD-T | CONUFL001-SMD-T:CONUFL001-SMD-T | CONUFL001-SMD-T:LINX_CONUFL001-SMD-T | https://www.digikey.com.au/en/products/detail/linx-technologies-inc/CONUFL001-SMD-T/7427732 |  |  | Linx Technologies |  |  |  |  | B |  | CONUFL001-SMD-T |  | Manufacturer Recommendations
 |  | J12 | SIM8060-6-0-14-00-A | SIM8060-6-0-14-00-A:SIM8060-6-0-14-00-A | SIM8060-6-0-14-00-A:GCT_SIM8060-6-0-14-00-A | SIM8060-6-0-14-00-A |  | SIM8060 is a hinged Sim Card Connector. With 6 contacts, with switch for card detection. Profile above PCB is 1.43mm. |  |  | Global Connector Technology | SIM8060-6-0-14-00-A | Package Analog Devices |  |  | SIM8060-6-0-14-00-A
 |  | JP1 | UART TX | Jumper:SolderJumper_2_Bridged | Jumper:SolderJumper-2_P1.3mm_Bridged_RoundedPad1.0x1.5mm | ~
 |  | L1 | SRP4020T-5R6M | pspice:INDUCTOR | SRP4020TA-5R6M:IND_SRP4020TA-5R6M | https://www.bourns.com/docs/Product-Datasheets/SRP4020TA.pdf |  |  |  |  |  |  |  |  |  | SRP4020TA-5R6M
 |  | L2 | LQH43CN100K03L | LQH43CN100K03L:LQH43CN100K03L | LQH43CN100K03L:IND_LQH43CN100K03L | https://www.digikey.com.au/en/products/detail/murata-electronics/LQH43CN100K03L/599911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 |  |  | Murata | 2.8mm |  |  |  | N/A |  | LQH43CN100K03L |  | Manufacturer Recommendations
 |  | LS1 | PS1240P02BT | PS1240P02BT:PS1240P02BT | PS1240P02BT:XDCR_PS1240P02BT | https://www.digikey.com.au/en/products/detail/tdk-corporation/PS1240P02BT/935924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 | Unavailable | Buzzers Transducer, Externally Driven Piezo 3V 4kHz 60dB @ 3V, 10cm Through Hole PC Pins |  | 7.0mm | TDK | PS1240P02CT3 | SIP-5 TDK |  | None | PS1240P02BT
 |  | MOSFET1 | SSM3J340R_LF | SSM3J340R-LF:SSM3J340R_LF | SSM3J340R_LF:SSM3J340R_LF | https://www.digikey.com.au/en/products/detail/toshiba-semiconductor-and-storage/SSM3J340R-LF/10259884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 |  |  |  |  |  |  |  |  |  | SSM3J340R,LF
 |  | MOSFET2 | SSM3J340R_LF | SSM3J340R-LF:SSM3J340R_LF | SSM3J340R_LF:SSM3J340R_LF | https://www.digikey.com.au/en/products/detail/toshiba-semiconductor-and-storage/SSM3J340R-LF/10259884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 |  |  |  |  |  |  |  |  |  | SSM3J340R,LF
 |  | Q1 | MMDT3904 | Transistor_BJT:MMDT3904 | Package_TO_SOT_SMD:SOT-363_SC-70-6 | http://www.diodes.com/_files/datasheets/ds30088.pdf
 |  | Q2 | BC847 | Transistor_BJT:BC847 | Package_TO_SOT_SMD:SOT-23 | http://www.infineon.com/dgdl/Infineon-BC847SERIES_BC848SERIES_BC849SERIES_BC850SERIES-DS-v01_01-en.pdf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
 |  | Q3 | BSS214NW | Transistor_FET:BSS214NW | Package_TO_SOT_SMD:SOT-323_SC-70 | https://www.infineon.com/dgdl/Infineon-BSS214NW-DS-v02_02-en.pdf?fileId=db3a30431b3e89eb011b695aebc01bde
 |  | Q4 | BC847 | Transistor_BJT:BC847 | Package_TO_SOT_SMD:SOT-23 | http://www.infineon.com/dgdl/Infineon-BC847SERIES_BC848SERIES_BC849SERIES_BC850SERIES-DS-v01_01-en.pdf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
 |  | Q5 | BC847 | Transistor_BJT:BC847 | Package_TO_SOT_SMD:SOT-23 | http://www.infineon.com/dgdl/Infineon-BC847SERIES_BC848SERIES_BC849SERIES_BC850SERIES-DS-v01_01-en.pdf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
 |  | R1 | 22.1K | Device:R | Resistor_SMD:R_0805_2012Metric | https://www.digikey.com.au/en/products/detail/bourns-inc/CR0805-FX-1001ELF/3593162 |  |  |  |  |  |  |  |  |  | CR0805-FX-1001ELF
 |  | R2 | 47.5K | Device:R | Resistor_SMD:R_0805_2012Metric | https://www.digikey.com.au/en/products/detail/bourns-inc/CR0805-FX-1001ELF/3593162 |  |  |  |  |  |  |  |  |  | CR0805-FX-1001ELF
 |  | R3 | 5.1K | Device:R | Resistor_SMD:R_0805_2012Metric | https://www.vishay.com/docs/20035/dcrcwe3.pdf |  |  |  |  |  |  |  |  |  | CRCW08055K10FKEA
 |  | R4 | 1K | Device:R | Resistor_SMD:R_0805_2012Metric | https://www.digikey.com.au/en/products/detail/bourns-inc/CR0805-FX-1001ELF/3593162 |  |  |  |  |  |  |  |  |  | CR0805-FX-1001ELF
 |  | R5 | 10K | Device:R | Resistor_SMD:R_0805_2012Metric | https://www.digikey.com.au/en/products/detail/yageo/RC0805FR-0710KP/4935334 |  |  |  |  |  |  |  |  |  | RC0805FR-0710KP
 |  | R6 | 10K | Device:R | Resistor_SMD:R_0805_2012Metric | https://www.digikey.com.au/en/products/detail/yageo/RC0805FR-0710KP/4935334 |  |  |  |  |  |  |  |  |  | RC0805FR-0710KP
 |  | R7 | 5.1K | Device:R | Resistor_SMD:R_0805_2012Metric | https://www.vishay.com/docs/20035/dcrcwe3.pdf |  |  |  |  |  |  |  |  |  | CRCW08055K10FKEA
 |  | R8 | 10K | Device:R | Resistor_SMD:R_0805_2012Metric | https://www.digikey.com.au/en/products/detail/yageo/RC0805FR-0710KP/4935334 |  |  |  |  |  |  |  |  |  | RC0805FR-0710KP
 |  | R9 | 0 | Device:R | Resistor_SMD:R_0805_2012Metric | https://www.digikey.com.au/en/products/detail/bourns-inc/CR0805-J-000ELF/3593157 |  |  |  |  |  |  |  |  |  | CR0805-J/-000ELF
 |  | R10 | 0 | Device:R | Resistor_SMD:R_0805_2012Metric | https://www.digikey.com.au/en/products/detail/bourns-inc/CR0805-J-000ELF/3593157 |  |  |  |  |  |  |  |  |  | CR0805-J/-000ELF
 |  | R11 | 10K | Device:R | Resistor_SMD:R_0805_2012Metric | https://www.digikey.com.au/en/products/detail/yageo/RC0805FR-0710KP/4935334 |  |  |  |  |  |  |  |  |  | RC0805FR-0710KP
 |  | R12 | 10M | Device:R | Resistor_SMD:R_0805_2012Metric | https://www.digikey.com.au/en/products/detail/bourns-inc/CR0805-FW-1005ELF/6153044 |  |  |  |  |  |  |  |  |  | CR0805-FW-1005ELF
 |  | R13 | 10K | Device:R | Resistor_SMD:R_0805_2012Metric | https://www.digikey.com.au/en/products/detail/yageo/RC0805FR-0710KP/4935334 |  |  |  |  |  |  |  |  |  | https://www.digikey.com.au/en/products/detail/yageo/RC0805FR-0710KP/4935334
 |  | R14 | 1K | Device:R | Resistor_SMD:R_0805_2012Metric | https://www.digikey.com.au/en/products/detail/bourns-inc/CR0805-FX-1001ELF/3593162 |  |  |  |  |  |  |  |  |  | CR0805-FX-1001ELF
 |  | R15 | 10K | Device:R | Resistor_SMD:R_0805_2012Metric | https://www.digikey.com.au/en/products/detail/yageo/RC0805FR-0710KP/4935334 |  |  |  |  |  |  |  |  |  | RC0805FR-0710KP
 |  | R16 | 4.7K | Device:R | Resistor_SMD:R_0805_2012Metric | https://www.digikey.com.au/en/products/detail/te-connectivity-passive-product/CRG0805F4K7/2135488 |  |  |  |  |  |  |  |  |  | CRG0805F4K7
 |  | R17 | 4.7K | Device:R | Resistor_SMD:R_0805_2012Metric | https://www.digikey.com.au/en/products/detail/te-connectivity-passive-product/CRG0805F4K7/2135488 |  |  |  |  |  |  |  |  |  | CRG0805F4K7
 |  | R18 | 10K | Device:R | Resistor_SMD:R_0805_2012Metric | https://www.digikey.com.au/en/products/detail/yageo/RC0805FR-0710KP/4935334 |  |  |  |  |  |  |  |  |  | RC0805FR-0710KP
 |  | R19 | 1K | Device:R | Resistor_SMD:R_0805_2012Metric | ~
 |  | R20 | 2K | Device:R | Resistor_SMD:R_0805_2012Metric | https://www.digikey.com.au/en/products/detail/te-connectivity-passive-product/CRG0805F4K7/2135488 |  |  |  |  |  |  |  |  |  | CRG0805F4K7
 |  | R21 | 0.1 | Device:R | Resistor_SMD:R_2512_6332Metric | https://www.digikey.com.au/en/products/detail/bourns-inc/CRL2512-FW-R100ELF/3786041 |  |  |  |  |  |  |  |  |  | CRL2512-FW-R100ELF
 |  | R22 | 21K | Device:R | Resistor_SMD:R_0805_2012Metric | https://www.digikey.com.au/en/products/detail/vishay-dale/CRCW080521K0FKEA/1175785 |  |  |  |  |  |  |  |  |  | CRCW080521K0FKEA
 |  | R23 | 10K | Device:R | Resistor_SMD:R_0805_2012Metric | https://www.digikey.com.au/en/products/detail/yageo/RC0805FR-0710KP/4935334 |  |  |  |  |  |  |  |  |  | RC0805FR-0710KP
 |  | R24 | 2K | Device:R | Resistor_SMD:R_0805_2012Metric | https://www.digikey.com.au/en/products/detail/te-connectivity-passive-product/CRG0805F4K7/2135488 |  |  |  |  |  |  |  |  |  | CRG0805F4K7
 |  | R25 | 2K | Device:R | Resistor_SMD:R_0805_2012Metric | https://www.digikey.com.au/en/products/detail/te-connectivity-passive-product/CRG0805F4K7/2135488 |  |  |  |  |  |  |  |  |  | CRG0805F4K7
 |  | R26 | 180K | Device:R | Resistor_SMD:R_0805_2012Metric | https://www.digikey.com.au/en/products/detail/yageo/RT0805FRE07180KL/1035150 |  |  |  |  |  |  |  |  |  | RT0805FRE07180KL
 |  | R27 | 91K | Device:R | Resistor_SMD:R_0805_2012Metric | https://www.digikey.com.au/en/products/detail/vishay-dale/CRCW080591K0FKEA/1175861 |  |  |  |  |  |  |  |  |  | CRCW080591K0FKEA
 |  | R28 | 330K | Device:R | Resistor_SMD:R_0805_2012Metric | https://www.digikey.com.au/en/products/detail/panasonic-electronic-components/ERJ-6ENF3303V/1746491 |  |  |  |  |  |  |  |  |  | ERJ-6ENF3303V
 |  | R29 | 3.2K | Device:R | Resistor_SMD:R_0805_2012Metric | https://www.digikey.com.au/en/products/detail/vishay-dale/TNPW08053K20BEEA/4972596 |  |  |  |  |  |  |  |  |  | TNPW08053K20BEEA
 |  | R30 | 0.1 | Device:R | Resistor_SMD:R_2512_6332Metric | https://www.digikey.com.au/en/products/detail/bourns-inc/CRL2512-FW-R100ELF/3786041 |  |  |  |  |  |  |  |  |  | CRL2512-FW-R100ELF
 |  | R31 | 1K | Device:R | Resistor_SMD:R_0805_2012Metric | https://www.digikey.com.au/en/products/detail/bourns-inc/CR0805-FX-1001ELF/3593162 |  |  |  |  |  |  |  |  |  | CR0805-FX-1001ELF
 |  | R32 | 100K | Device:R | Resistor_SMD:R_0805_2012Metric | https://www.digikey.com.au/en/products/detail/vishay-dale/CRCW0805100KJNTA/1226893 |  |  |  |  |  |  |  |  |  | CRCW0805100KJNTA
 |  | R33 | 47K | Device:R | Resistor_SMD:R_0805_2012Metric | https://www.digikey.com.au/en/products/detail/vishay-dale/CRCW080547K0FKTA/1223026 |  |  |  |  |  |  |  |  |  | CRCW080547K0FKTA
 |  | R34 | 4.7K | Device:R | Resistor_SMD:R_0805_2012Metric | https://www.digikey.com.au/en/products/detail/te-connectivity-passive-product/CRG0805F4K7/2135488 |  |  |  |  |  |  |  |  |  | CRG0805F4K7
 |  | R35 | 1K | Device:R | Resistor_SMD:R_0805_2012Metric | ~
 |  | R36 | 10K | Device:R | Resistor_SMD:R_0805_2012Metric | https://www.digikey.com.au/en/products/detail/yageo/RC0805FR-0710KP/4935334 |  |  |  |  |  |  |  |  |  | https://www.digikey.com.au/en/products/detail/yageo/RC0805FR-0710KP/4935334
 |  | R37 | 100K | Device:R | Resistor_SMD:R_0805_2012Metric | https://www.digikey.com.au/en/products/detail/vishay-dale/CRCW0805100KJNTA/1226893 |  |  |  |  |  |  |  |  |  | CRCW0805100KJNTA
 |  | R38 | 47K | Device:R | Resistor_SMD:R_0805_2012Metric | ~
 |  | R39 | 10K | Device:R | Resistor_SMD:R_0805_2012Metric | https://www.digikey.com.au/en/products/detail/yageo/RC0805FR-0710KP/4935334 |  |  |  |  |  |  |  |  |  | RC0805FR-0710KP
 |  | R40 | 1K | Device:R | Resistor_SMD:R_0805_2012Metric | ~
 |  | R41 | 0 | Device:R | Resistor_SMD:R_0805_2012Metric | https://www.digikey.com.au/en/products/detail/yageo/RC0805FR-0710KP/4935334 |  |  |  |  |  |  |  |  |  | https://www.digikey.com.au/en/products/detail/yageo/RC0805FR-0710KP/4935334
 |  | RV1 | ESD_RST_IN | Device:Varistor | Resistor_SMD:R_0805_2012Metric | https://www.digikey.com.au/en/products/detail/kyocera-avx/VC080518A400DP/684857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 |  |  |  |  |  |  |  |  |  | VC080518A400DP
 |  | SW1 | BOOT | 2022-10-04_00-56-22:1977223-6 | 1977223-6:1977223-6 | https://www.digikey.com.au/en/products/detail/te-connectivity-alcoswitch-switches/1977223-6/2400488 |  |  |  |  |  |  |  |  |  | 1977223-6
 |  | SW2 | RESET | 2022-10-04_00-56-22:1977223-6 | 1977223-6:1977223-6 | https://www.digikey.com.au/en/products/detail/te-connectivity-alcoswitch-switches/1977223-6/2400488 |  |  |  |  |  |  |  |  |  | 1977223-6
 |  | SW3 | CAT_M1_RST | 2022-10-04_00-56-22:1977223-6 | 1977223-6:1977223-6 | https://www.digikey.com.au/en/products/detail/te-connectivity-alcoswitch-switches/1977223-6/2400488 |  |  |  |  |  |  |  |  |  | 1977223-6
 |  | TP1 | 12V_EN | Connector:TestPoint | TestPoint:TestPoint_Pad_D1.0mm | ~
 |  | TP2 | RX_1V8 | Connector:TestPoint | TestPoint:TestPoint_Pad_D1.0mm | ~
 |  | TP3 | TX_1V8 | Connector:TestPoint | TestPoint:TestPoint_Pad_D1.0mm | ~
 |  | TP4 | PWR_ON | Connector:TestPoint | TestPoint:TestPoint_Pad_D1.0mm | ~
 |  | TP5 | VOUT | Connector:TestPoint | TestPoint:TestPoint_Pad_D1.0mm | ~
 |  | TP6 | 1V8 | Connector:TestPoint | TestPoint:TestPoint_Pad_D1.0mm | ~
 |  | U1 | CP2102N-Axx-xQFN28 | Interface_USB:CP2102N-Axx-xQFN28 | Package_DFN_QFN:QFN-28-1EP_5x5mm_P0.5mm_EP3.35x3.35mm | https://www.silabs.com/documents/public/data-sheets/cp2102n-datasheet.pdf |  |  |  |  |  |  |  |  |  | CP2102N-A02-GQFN28
 |  | U2 | ESP32-WROOM-32E_(16MB) | ESP32-WROOM-32E__16MB_:ESP32-WROOM-32E_(16MB) | ESP32-WROOM-32E__16MB_:XCVR_ESP32-WROOM-32E_(16MB) | https://www.digikey.com.au/en/products/detail/espressif-systems/ESP32-WROOM-32E-N16/11613144 |  |  |  |  |  |  |  |  |  | ESP32-WROOM-32E-N16
 |  | U3 | TCA9534 | Interface_Expansion:TCA9534 | Package_SO:TSSOP-16_4.4x5mm_P0.65mm | https://www.digikey.com.au/en/products/detail/texas-instruments/TCA9534PWR/5004966 |  |  |  |  |  |  |  |  |  | TCA9534PWR
 |  | U4 | INA219BxD | Analog_ADC:INA219BxD | Package_SO:SOIC-8_3.9x4.9mm_P1.27mm | http://www.ti.com/lit/ds/symlink/ina219.pdf |  |  |  |  |  |  |  |  |  | INA219BIDR
 |  | U5 | LT3652IMSE | Battery_Management:LT3652IMSE | Package_SO:MSOP-12-1EP_3x4mm_P0.65mm_EP1.65x2.85mm | https://www.analog.com/media/en/technical-documentation/data-sheets/3652fe.pdf |  |  |  |  |  |  |  |  |  | LT3652IMSE
 |  | U6 | TPS22967DSGR | TPS22967DSGR:TPS22967DSGR | TPS22967DSGR:SON50P200X200X80-9N | https://www.digikey.com.au/en/products/detail/texas-instruments/TPS22967DSGR/4331550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 |  |  |  |  |  |  |  |  |  | TPS22967DSGR
 |  | U7 | MCP73832-2-OT | Battery_Management:MCP73832-2-OT | Package_TO_SOT_SMD:SOT-23-5 | http://ww1.microchip.com/downloads/en/DeviceDoc/20001984g.pdf |  |  |  |  |  |  |  |  |  | MCP73832T-2ACI/OT
 |  | U8 | INA219BxD | Analog_ADC:INA219BxD | Package_SO:SOIC-8_3.9x4.9mm_P1.27mm | http://www.ti.com/lit/ds/symlink/ina219.pdf |  |  |  |  |  |  |  |  |  | INA219BIDR
 |  | U9 | MIC2288YD5-TR | MIC2288YD5-TR:MIC2288YD5-TR | MIC2288YD5-TR:SOT95P280X100-5N | https://www.digikey.com.au/en/products/detail/microchip-technology/MIC2288YD5-TR/1028498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 |  |  | Microchip | 1.0mm |  |  |  | B |  | MIC2288YD5-TR | 8798 | IPC-7351B
 |  | U10 | XC6215B332MR-G | XC6215B332MR-G:XC6215B332MR-G | XC6215B332:XC6215B332MR-G | https://www.digikey.com.au/en/products/detail/torex-semiconductor-ltd/XC6215B332MR-G/2138122 |  |  |  |  |  |  |  |  |  | XC6215B332MR-G
 |  | U11 | TPS22967DSGR | TPS22967DSGR:TPS22967DSGR | TPS22967DSGR:SON50P200X200X80-9N | https://www.digikey.com.au/en/products/detail/texas-instruments/TPS22967DSGR/4331550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 |  |  |  |  |  |  |  |  |  | TPS22967DSGR
 |  | U12 | SARA-R500S-01B | SARA-R410M-02B:SARA-R410M-02B | SARA-R410M-02B:XCVR_SARA-R410M-02B | https://www.digikey.com.au/en/products/detail/u-blox/SARA-R410M-02B/9565822 |  |  |  |  |  |  |  |  |  | SARA-R500S-01B
 |  | U13 | TXB0104PW | Logic_LevelTranslator:TXB0104PW | Package_SO:TSSOP-14_4.4x5mm_P0.65mm | https://www.digikey.com.au/en/products/detail/texas-instruments/TXB0104PWR/1629102 |  |  |  |  |  |  |  |  |  | TXB0104PW
 |  | Y1 | 32.768KHz | ABS07AIG-32.768KHZ-T:ABS07AIG-32.768KHZ-T | ABS07AIG-32:XTAL320X150X90 | https://www.digikey.com.au/en/products/detail/abracon-llc/ABS07AIG-32-768KHZ-T/5817548 |  |  |  |  |  |  |  |  |  | ABS07AIG-32.768KHZ-T
Collated Components:
Item | Qty | Reference(s) | Value | LibPart | Footprint | Datasheet | AVAILABILITY | DESCRIPTION | MANUFACTURER | MAXIMUM_PACKAGE_HEIGHT | MF | MP | PACKAGE | PARTREV | PRICE | Part | SNAPEDA_PACKAGE_ID | STANDARD
1 | 1 | B1 | 1049P | 1049P:1049P | 1049P:1049P
2 | 8 | C3, C6, C7, C21, C24, C28, C33, C34 | 0.1uF | Device:C | Capacitor_SMD:C_0805_2012Metric | https://www.digikey.com.au/en/products/detail/yageo/AC0805KRX7R7BB104/6643148 |  |  |  |  |  |  |  |  |  | AC0805KRX7R7BB104
3 | 3 | C4, C14, C16 | 4.7uF | Device:C | Capacitor_SMD:C_0805_2012Metric | https://www.digikey.com.au/en/products/detail/samsung-electro-mechanics/CL21B475KOFNFNE/3888628 |  |  |  |  |  |  |  |  |  | CL21B475KOFNFNE
4 | 5 | C5, C12, C13, C19, C22 | 1uF | Device:C | Capacitor_SMD:C_0805_2012Metric | https://www.digikey.com.au/en/products/detail/kemet/C0805C105K3RAC7800/2211765 |  |  |  |  |  |  |  |  |  | C0805C105K3RAC7800
5 | 2 | C8, C9 | 12pF | Device:C | Capacitor_SMD:C_0805_2012Metric | https://www.digikey.com.au/en/products/detail/vishay-vitramon/VJ0805A120FXJCW1BC/8307136 |  |  |  |  |  |  |  |  |  | VJ0805A120FXJCW1BC
6 | 1 | C10 | 22uF | Device:C | Capacitor_SMD:C_0805_2012Metric | https://www.digikey.com.au/en/products/detail/kemet/C0805C226M8PAC7800/5327667 |  |  |  |  |  |  |  |  |  | C0805C226M8PAC7800
7 | 3 | C11, C15, C20 | 10uF | Device:C | Capacitor_SMD:C_0805_2012Metric | https://www.digikey.com.au/en/products/detail/tdk-corporation/C2012X5R1V106K125AC/3951654 |  |  |  |  |  |  |  |  |  | C2012X5R1V106K125AC
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

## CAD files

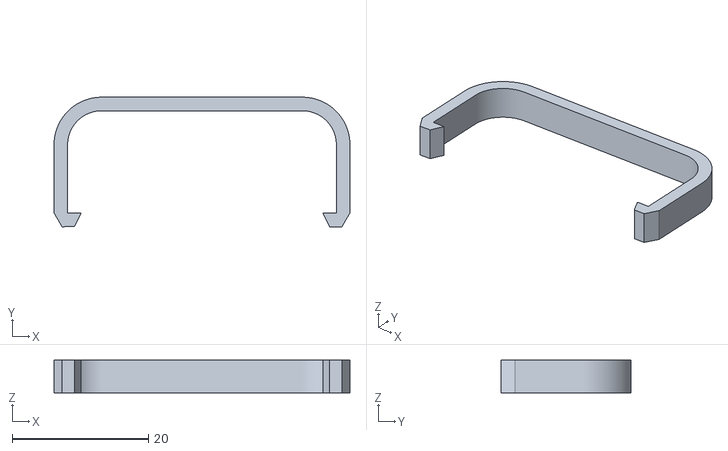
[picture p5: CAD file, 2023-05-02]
cad/Battery holder clip V2.stl
43.5 x 19.1 x 4.80

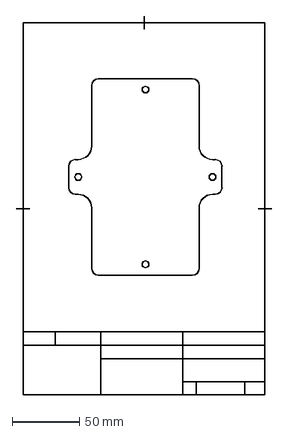
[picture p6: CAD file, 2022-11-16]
electronics/breakout/breakout-box-pcb-outline.dxf
190.0 x 282.0 mm

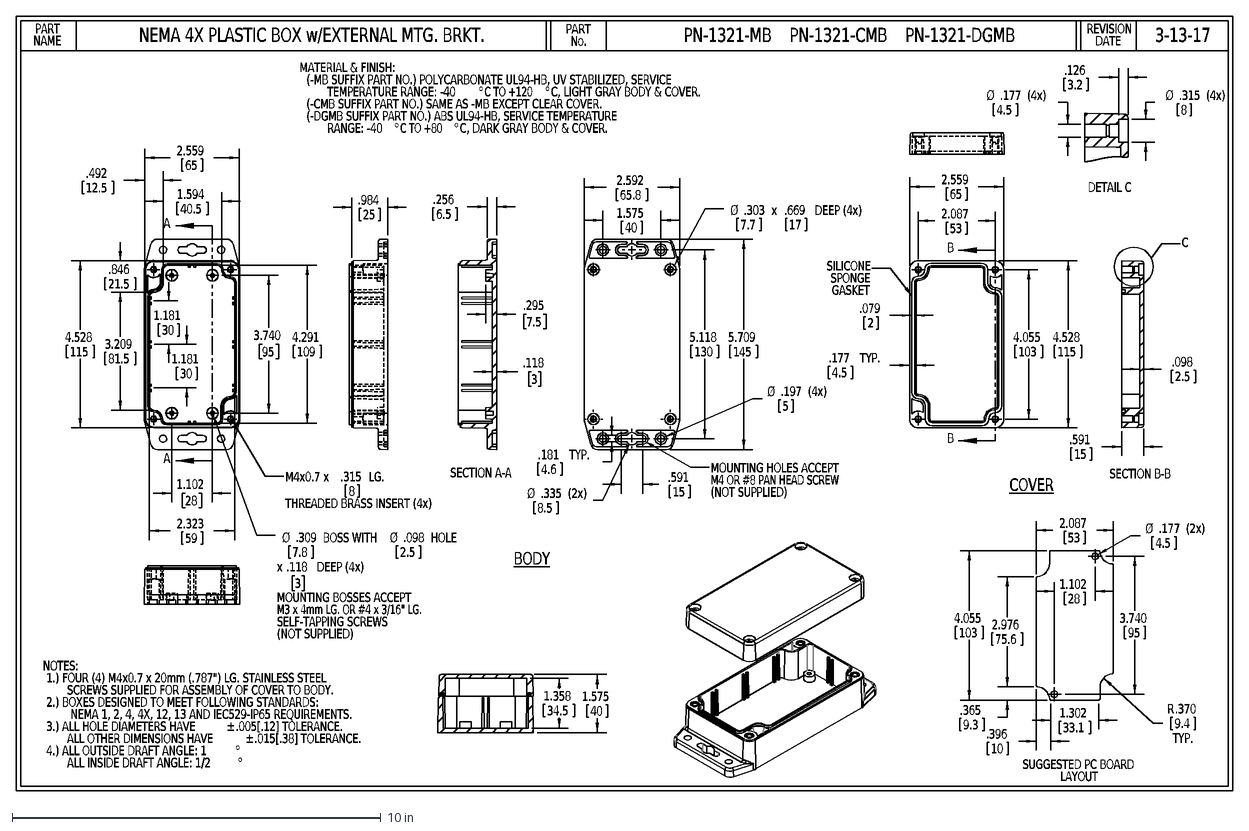
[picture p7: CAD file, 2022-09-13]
electronics/motherboard/enviro-node/board-outlines/bud-ind-type4x-12-13.dxf
SUGGESTED PC BOARD
LAYOUT
BODY
COVER
MATERIAL & FINISH:
(-MB SUFFIX PART NO.) POLYCARBONATE UL94-HB, UV STABILIZED, SERVICE
TEMPERATURE RANGE: -40
°
C TO +120
C, LIGHT GRAY BODY & COVER.
(-CMB SUFFIX PART NO.) SAME AS -MB EXCEPT CLEAR COVER.
(-DGMB SUFFIX PART NO.) ABS UL94-HB, SERVICE TEMPERATURE
RANGE: -40
C TO +80
C, DARK GRAY BODY & COVER.
NOTES:
1.) FOUR (4) M4x0.7 x 20mm (.787") LG. STAINLESS STEEL
SCREWS SUPPLIED FOR ASSEMBLY OF COVER TO BODY.
2.) BOXES DESIGNED TO MEET FOLLOWING STANDARDS:
NEMA 1, 2, 4, 4X, 12, 13 AND IEC529-IP65 REQUIREMENTS.
3.) ALL HOLE DIAMETERS HAVE
±
.005[.12] TOLERANCE.
ALL OTHER DIMENSIONS HAVE
.015[.38] TOLERANCE.
4.) ALL OUTSIDE DRAFT ANGLE: 1
ALL INSIDE DRAFT ANGLE: 1/2
3-13-17
NEMA 4X PLASTIC BOX w/EXTERNAL MTG. BRKT.
PN-1321-MB PN-1321-CMB PN-1321-DGMB
PART
NAME
No.
REVISION
DATE
4.055
103
2.087
53
R
.370
TYP.
9.4
3.740
95
Ø
.177
(2x)
4.5
2.976
75.6
.365
9.3
.396
10
1.302
33.1
1.102
28
1.358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

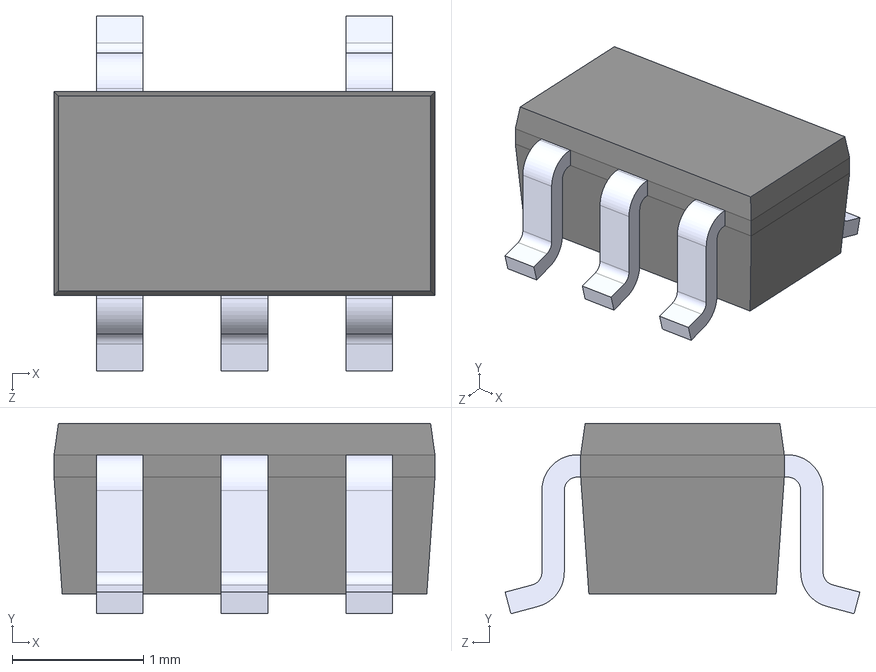
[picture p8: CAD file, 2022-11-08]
electronics/motherboard/enviro-node/parts/adc/MCP3221A0T-E_OT/MCP3221A0T-E_OT.step
2.90 x 1.45 x 2.70 mm

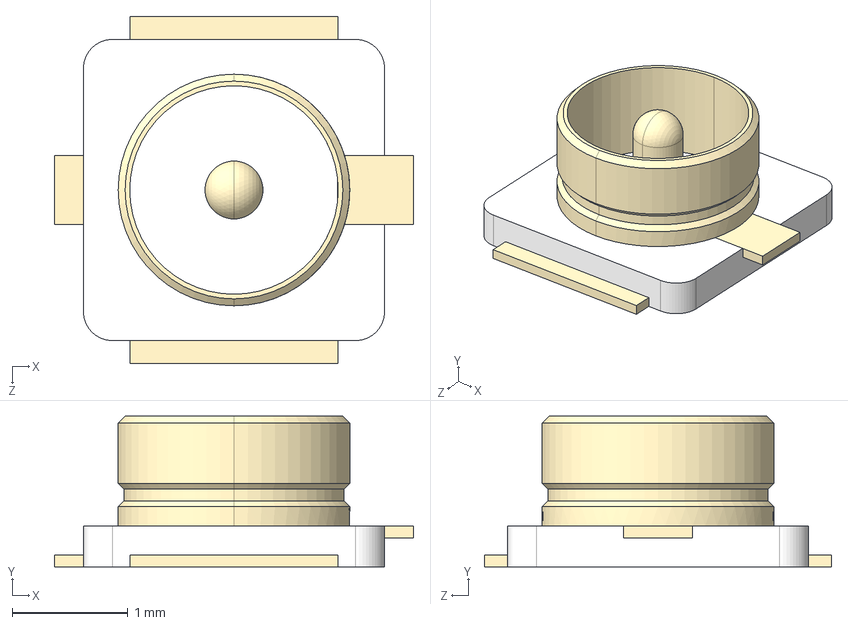
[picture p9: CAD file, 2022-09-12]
electronics/motherboard/enviro-node/parts/antenna/CONUFL001-SMD-T/CONUFL001-SMD-T.step
3.10 x 1.30 x 3.00 mm

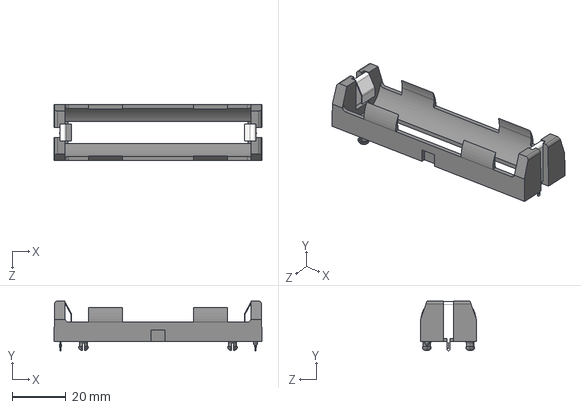
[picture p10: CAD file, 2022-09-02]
electronics/motherboard/enviro-node/parts/battery/holders/18650/1043/1043.step
77.1 x 18.4 x 20.7 mm

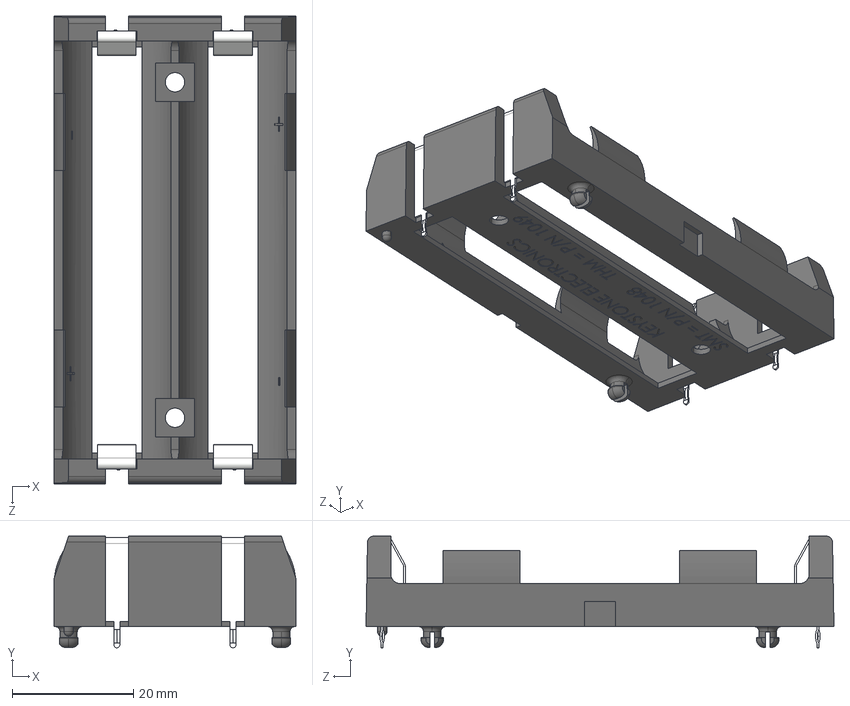
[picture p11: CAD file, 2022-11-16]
electronics/motherboard/enviro-node/parts/battery/holders/18650/1049P/1049P.step
39.8 x 18.4 x 77.1 mm

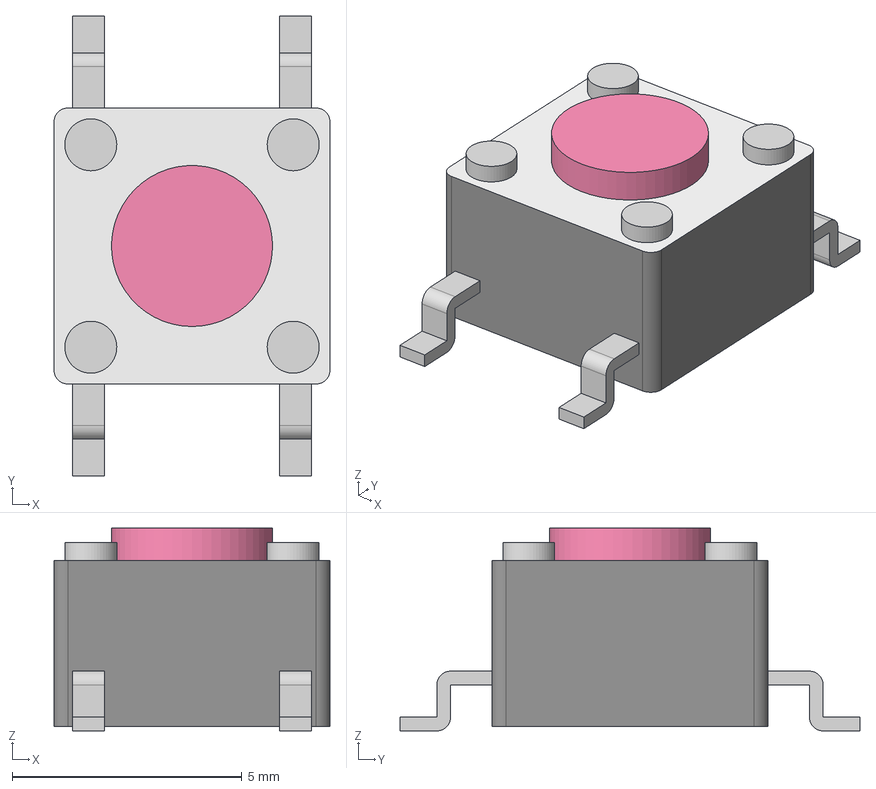
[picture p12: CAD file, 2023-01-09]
electronics/motherboard/enviro-node/parts/buttons/small/1977223-6/c-1977223-6-b-3d.step
6.00 x 10.0 x 4.41 mm

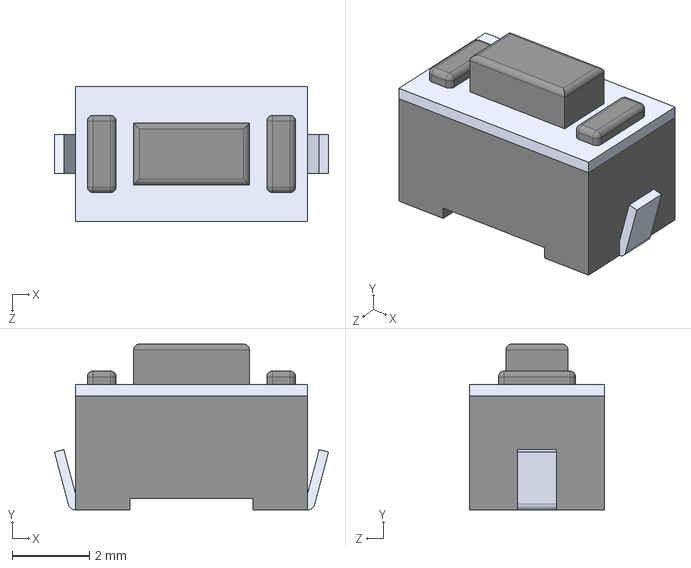
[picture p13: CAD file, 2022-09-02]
electronics/motherboard/enviro-node/parts/buttons/small/PTS636_SM43J_SMTR_LFS/PTS636_SM43J_SMTR_LFS.step
7.10 x 4.30 x 3.50 mm

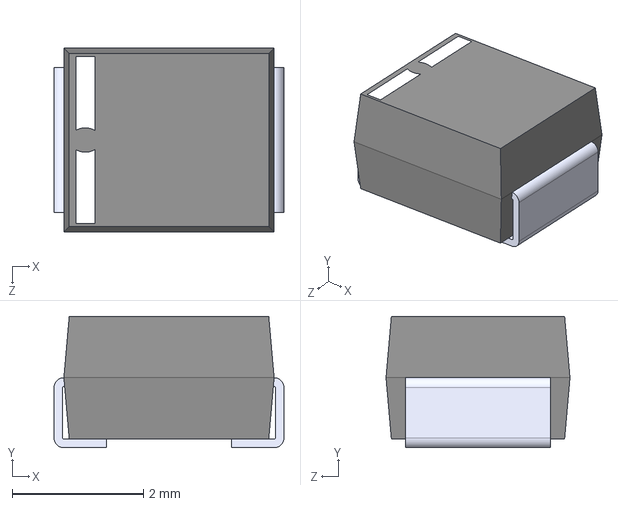
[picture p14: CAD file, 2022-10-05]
electronics/motherboard/enviro-node/parts/capacitors/T520B107M006ATE015/T520B107M006ATE015.step
3.50 x 2.00 x 2.80 mm

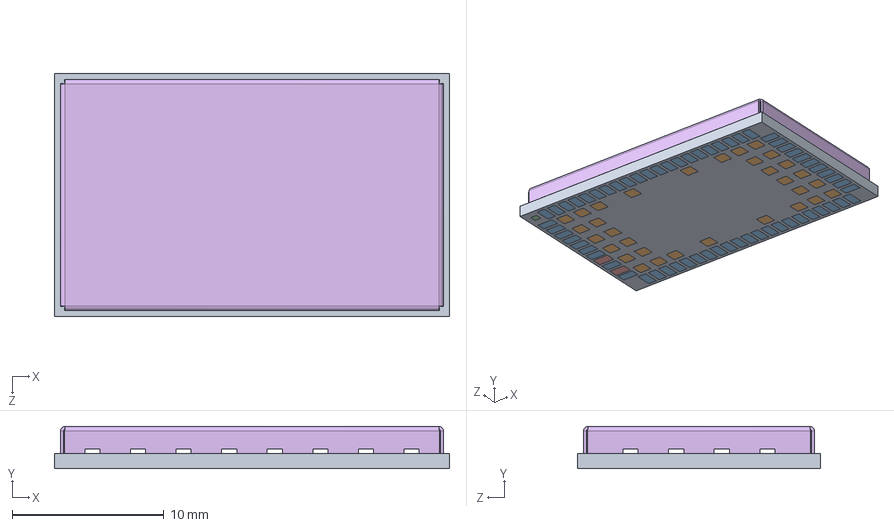
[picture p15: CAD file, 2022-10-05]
electronics/motherboard/enviro-node/parts/comms/cat-m1/SARA-R410M-02B/SARA-R410M-02B.step
26.0 x 2.78 x 16.0 mm

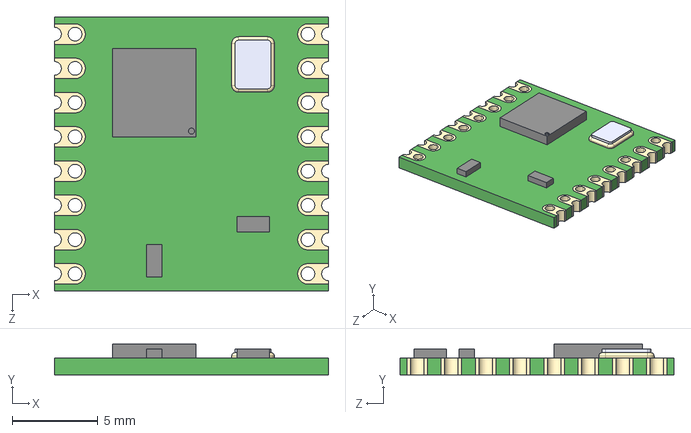
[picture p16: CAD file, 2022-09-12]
electronics/motherboard/enviro-node/parts/comms/lora/RFM95W-915S2/RFM95W-915S2.step
16.0 x 1.80 x 16.0 mm

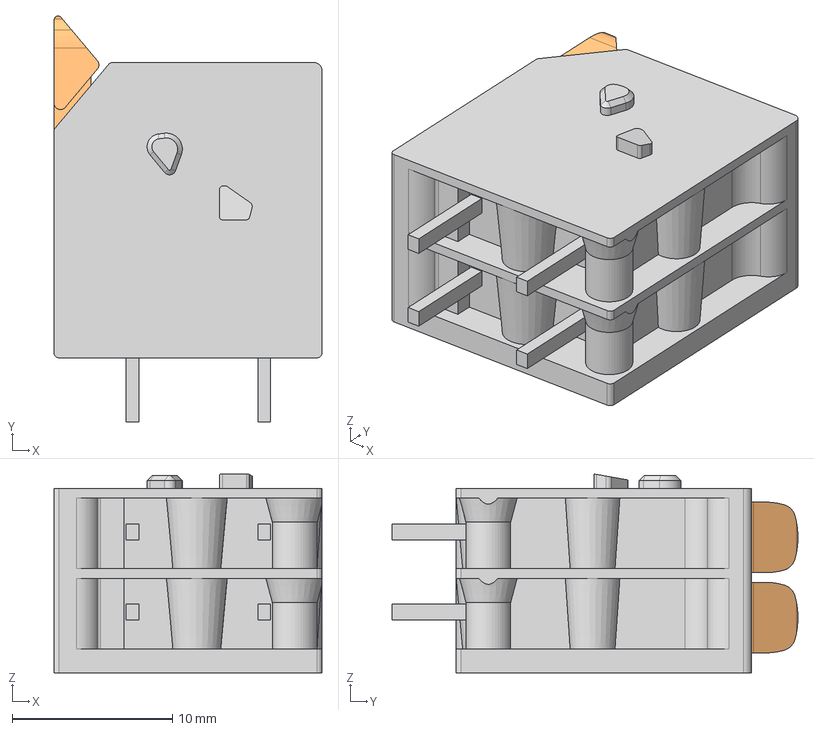
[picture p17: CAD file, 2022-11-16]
electronics/motherboard/enviro-node/parts/connectors/2-pole/2604-3102/2604-3102.stp
16.7 x 25.3 x 12.4 mm

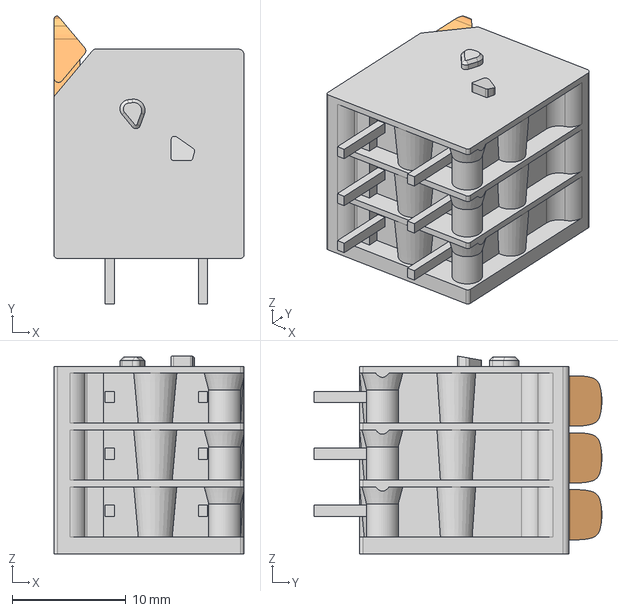
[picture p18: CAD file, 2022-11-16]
electronics/motherboard/enviro-node/parts/connectors/3-pole/2604-3103/2604-3103.stp
16.7 x 25.3 x 17.4 mm

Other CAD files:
electronics/motherboard/enviro-node/parts/connectors/5-pole/2604-3105/2604-3105.stp
electronics/motherboard/enviro-node/parts/connectors/EJ503A/EJ503A.step
electronics/motherboard/enviro-node/parts/connectors/jtag/3221-10-0100-00/3221-10-0100-00.STEP
electronics/motherboard/enviro-node/parts/connectors/nano-sim/SIM8060-6-0-14-00-A/SIM8060-6-0-14-00-A.stp
cad/Breakoutbox holder Final.stl
cad/PVC WB board holder final.stl
cad/long_bracket.f3z
cad/short_bracket.f3z
electronics/breakout/parts/connectors/4-pole/T4041037041-000/T4041037041-000.step
electronics/motherboard/enviro-node/parts/buttons/small/1977223-6/c-1977223-6-b-3d.stp
electronics/motherboard/enviro-node/parts/connectors/3-pole/T4041037031-000/T4041037031-000.step
electronics/motherboard/enviro-node/parts/connectors/PCIe/MDT420B03001/MDT420B03001.step
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

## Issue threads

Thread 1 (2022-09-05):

STM32 debugger

HarveyBates, 2022-09-05:
Need to insuring correct wiring for both:
1. ST-Link/V2 debuggers
2. Six-pin debuggers (like the debugger on a nucleo board)

Resources:
1. https://www.st.com/content/ccc/resource/technical/layouts_and_diagrams/schematic_pack/group2/a4/0a/34/f4/05/88/45/a7/MB1136-DEFAULT-C03_Schematic/files/MB1136-DEFAUL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
2. https://www.st.com/content/ccc/resource/technical/document/user_manual/group1/99/49/91/b6/b2/3a/46/e5/DM00526767/files/DM00526767.pdf/jcr:content/translations/en.DM0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 (Table 6)

HarveyBates, 2022-09-12:
Not required due to design changes

Closed 2022-09-12.

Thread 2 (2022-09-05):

STM32 decoupling capacitors

HarveyBates, 2022-09-05:
See this file:
https://4donline.ihs.com/images/VipMasterIC/IC/SGST/SGST-S-A0004456612/SGST-S-A0004456612-1.pdf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

Page 109 for `Power supply scheme`

HarveyBates, 2022-09-05:
https://au.element14.com/stmicroelectronics/stm32l476mey6tr/mcu-arm-cortex-m4-80mhz-wlcsp/dp/2855729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 potential stm32 micro

HarveyBates, 2022-09-12:
Not required due to design changes

Closed 2022-09-12.

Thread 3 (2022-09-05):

Firmware version in LoRa payload

HarveyBates, 2022-09-05:
A LoRa packet on startup (perhaps at intervals as well) should contain the firmware version (e.g. `v1.0.1`).

Perhaps this should contain firmware from both sensor micro and telemetry micro.

dajtxx, 2022-09-05:
If we make this periodic, such as daily, we can use a confirmed uplink to check the session is still valid.

We could also include known sensor info in this message, based upon an SDI-12 bus query. That won't cover analogue and digital inputs though.

We also need to think how this fits with other transports.

dajtxx, 2023-07-24:
We decided against including LoRaWAN.

Closed 2023-07-24.

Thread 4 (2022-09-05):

On-site node reboot without opening enclosure

dpi-mick, 2022-09-05:
Allow a node to be rebooted by pressing a button on the node enclosure or by holding a magnet against it the enclosure or some other means that doesn't involve opening the enclosure.

The use case here is to allow an on-site person to reboot a node if it's having a problem, has dropped it's cellular connection etc.

The magnet option might be useful if the node enclosure is not easily accessible. e.g. up a tree, on a pole etc.

Audible feedback of reboot would be useful.

HarveyBates, 2022-11-15:
Have external device reboot in next version without opening enclosure with audible feedback.

BEEP BOP! 😀

Closed 2022-11-15.

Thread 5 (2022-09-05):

Allow uplink/downlink of node configuration.

dpi-mick, 2022-09-05:
Allow remote configuration of certain node configuration items. i.e. send new operating parameters to a node already in the field.

Some examples:-

**1/ Change a nodes uplink interval**

**2/ Downlink of SDI-12 configuration to node.**

- Send a set of SDI-12 commands, addresses etc to a node to have it (re)configure it's SDI-12 settings.
- May be able to design hardware to allow the node to change the addresses of connected SDI-12 sensors. i.e. isolating sensors on certain physical connectors. May even map physical connectors to SDI-12 addresses ??!!

**3/ Change MQTT broker details**

**4/ Change cellular APN.**

dajtxx, 2023-03-29:
A set of config commands can be sent to a node by publishing them to the wombat/SERIAL# topic of the MQTT broker.

The Wombat checks for these when it logs into the MQTT broker and runs them immediately.

dajtxx, 2023-05-24:
Downloading the config is sufficient to close this issue. If we want the config reported later we can open a different issue.

Closed 2023-05-24.

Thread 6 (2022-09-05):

Node Maintenance Mode

dpi-mick, 2022-09-05:
Allow a node to be placed into "maintenance" mode, such that it does not uplink data points.

This would allow maintenance actions to take place without impact on data quality. e.g. sensor replacements.

Ideally, the node would still be polling sensors, and may still uplink data, but the uplink message may have a "maintenance" flag so the data received does not get added to the database.

HarveyBates, 2022-11-15:
added external push button that could enable this function, or it may be enabled in the app after pressing the push button

Closed 2022-11-15.

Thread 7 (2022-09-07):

Sensor connectors (Internal or External)

HarveyBates, 2022-09-07:
Continuing from #4, we have two options for connecting sensors to the circuit board:
1. Connections outside the box - don't have to open the box to connect a sensor. Has the disadvantage of longer setup time taken to assemble the board and perhaps higher cost. Has the advantage of not needing to open the enclosure to add a new sensor.
2. Connections inside the box - cables route into the enclosure. Pluggable screw terminals can be used but will require that for a new sensor to be added, the enclosure must be opened.

HarveyBates, 2022-09-20:
Panel mount system could be assembled offsite. Would need a template to drill holes in enclosures. Multiple plugs could allow for individual SDI-12 addresses. Still faces the problem of conflicting addresses on new devices (even though they should all be address 0, some aren't).

Closed 2023-03-29.

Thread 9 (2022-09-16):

External USB Socket

dpi-mick, 2022-09-16:
Include an external USB Socket (with weather cap).

Something like the following (but less costly!!):-

[https://au.element14.com/multicomp-pro/mp002448/usb-type-c-r-a-ip68-sealed-connector/dp/3369657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|pcrid||pkw||pmt||slid||product|3369657|pgrid||ptaid||&CMP=KNC-GAU-GEN-SHOPPING-PLA-PMAX](url)

HarveyBates, 2022-11-15:
cant afford this at this time 😞

Closed 2022-11-15.

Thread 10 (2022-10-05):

Include Serial1 UART header on basic-feather-node

dajtxx, 2022-10-05:
Expose Feather pins RX & TX to a 2-pin header so Serial1 can be used for logging.

This allows logging to be done when running from a battery, and avoids losing the logging connection every time the Feather goes to sleep.

Closed 2022-11-02.

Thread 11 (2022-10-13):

Kangaroo nodes missing messages

dajtxx, 2022-10-13:
A message every few hours seems to be missing from the two first Kangaroo nodes.

Add some jitter to the uplink time and see if that fixes it.

If not add an external antenna and see if that helps.

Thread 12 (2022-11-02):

Kangaroo 12V_EN sharing pin with battery V read pin

dajtxx, 2022-11-02:
The Kangaroo board is using pin D9 (aka A7) to control the voltage booster for SDI-12.

On the Feather, this pin is used to measure the battery voltage via the A2D converter.

We need to move the 12V_EN signal to another pin.

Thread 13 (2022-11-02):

Kangaroo test button is difficult to press when the Serial1 UART headers are installed

dajtxx, 2022-11-02:
The button is sandwiched between the Feather headers and the UART headers and very difficult to press, would be good to have it moved to the opposite side of the board, in the corner near the 2nd SDI-12 header.

Basically, somewhere there isn't a lot of components sitting high above the board surface.

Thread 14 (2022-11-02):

Kangaroo firmware freezes in standby mode

dajtxx, 2022-11-02:
At least one Kangaroo board is freezing when in standby mode.

This was observed on the bench, with the board not having sent a message for over a day and the last log message saying it was going into standby mode. Pressing the test button did not wake the board up, meaning the external interrupt connected to the button was not recognised.

A possible fix is to stop the on chip voltage regulator going to low power mode when the MCU goes into standby mode.

HarveyBates, 2022-11-02:
What size resistors for the pull-up?

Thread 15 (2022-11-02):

Kangaroo UART TX & RX lines need pull-up resistors

dajtxx, 2022-11-02:
At least one Kangaroo board went into command line mode when the test button was pressed due to noise on the RX line when no device was connected. The board should have gone back to sleep in 5 seconds but was stuck in a busy loop waiting for a valid command to be entered with no way to exit command line mode.

A pull-up resistor will pull the line to the idle state by default.

A pull-up on the TX line isn't as necessary, but it may avoid noise characters being sent to a connected device in some circumstances, such as when the node is powered on.

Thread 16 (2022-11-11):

SDI-12 Input Only Pin

HarveyBates, 2022-11-11:
SDI-12 Line is currently on GPIO36, this pin is **INPUT** only.

Change to GPIO27 (12 in package) in next revision.

HarveyBates, 2022-11-15:
completed in next version SDI-12 will be on GPIO21

Closed 2022-11-15.

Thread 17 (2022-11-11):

Push button not accessible over interrupt

HarveyBates, 2022-11-11:
The push button is connected to the TCA9534 IO expander. Change to another pin, perhaps GPIO36 (an input only pin)?

HarveyBates, 2022-11-11:
Also GPIO21 is designated as not connected, this could be used for SDI-12? #16

HarveyBates, 2022-11-11:
correction: the push button is connected to GPIO34
just need to remove it from the TCA9534 list

HarveyBates, 2022-11-15:
completed in next version

Closed 2022-11-15.

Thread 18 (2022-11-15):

SD-Card CS on digital pin

HarveyBates, 2022-11-15:
Put the SD-Card chip select on a digital pin to avoid inconvenience.

HarveyBates, 2022-11-15:
cant fix this as there aren't enough pins, just going to have to toggle the CS pin independently of its implementation in the firmware

Closed 2022-11-15.

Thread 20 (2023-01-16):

Some messages from the Wombat firmware has an extra trailing brace making invalid JSON

dajtxx, 2023-01-16:
An example:

```
{"timestamp":"2023-01-16T22:34:57Z","source_ids":{"serial_no":"C8F09E125DD0"},"timeseries":[{"name":"battery (v)","value":4.198359966},{"name":"solar (v)","value":18.97758102},{"name":"pulse_count","value":0},{"name":"shortest_pulse","value":0},{"name":"3_VWC","value":2042.48999},{"name":"3_Temperature","value":24.10000038}]}}
```

Closed 2023-03-29.

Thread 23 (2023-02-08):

ESP32 clock runs fast

dajtxx, 2023-02-08:
The ESP32s clock is very inaccurate (eg 10 seconds in 40 minutes in one test) due to the default 150 kHz source. There is an option to use an internal 8.5 MHz source which requires recompiling the Arduino/ESP32 core. This is meant to be more accurate so worth a try.

The simplest fix we can put in is to connect to the internet and do a time sync using NTP or the mobile network every hour to keep this drift in check.

More complicated fixes are to either include a 32 kHz crystal on the board which takes 2 ESP32 pins, or to include a separate RTC and crystal which will need to be communicated with via I2C or SPI.

HarveyBates, 2023-02-10:
@dajtxx
The board has an onboard 32 kHz crystal already.
It connected to pins 8 and 9 on the schematic (https://github.com/DPIclimate/enviro-node/blob/master/electronics/motherboard/enviro-node/schematics/microcontroller.pdf).

dajtxx, 2023-02-12:
So it does! Well done :)

Now to recompile the ESP32/Arduino core. Reference:

https://github.com/espressif/esp32-arduino-lib-builder/issues/102

dajtxx, 2023-03-29:
See commit f27495d187aaae2fa22da989a00f72f47fc6b80a

The code to set the RTC source was copied from the Arduino core and modified to only use the external crystal. Given it's only feeding the RTC is should be safe to call from setup().

A clock skew adjustment parameter has also been added to the config class, and some code added to where the time is taken from the modem to try and keep the RTC in line.

Closed 2023-03-29.

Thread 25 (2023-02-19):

MQTT messages should be sent from files on the modem

dajtxx, 2023-02-19:
MQTT messages that are not sent from a file on the modem have a maximum size of 1024 bytes. The test nodes are under this but it would be safer to copy the JSON file from the ESP32 SPIFFS to the modem filesystem and send the message from there, finally deleting the file from both places.

dajtxx, 2023-05-29:
This is required to implement #43 because that issue makes the JSON message >1024 bytes.

dajtxx, 2023-08-21:
Fixed in commit 0f0b933.

Closed 2023-08-21.

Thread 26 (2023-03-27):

RX pin on UART header does not work

dajtxx, 2023-03-27:
The UART-USB bridge is working and UART0 is available via the USB C connector now, but the RX pin on the UART header does not work - the board never sees the characters sent to it.

If the traces between the UART header and the UART-USB bridge are broken then the UART header works ok.

dajtxx, 2023-03-30:
This could be because the bridge IC is holding the line level at idle, because it has no characters to send, and the signal coming over the UART header cannot override this.

Placing a jumper on the RX line between the bridge IC and the header will allow the trace to be broken when we want to use the header on the bench, and having the jumper in place will allow the USB port to be used for comms in the field.

dajtxx, 2023-05-24:
Board rev 1.0.2 has a jumper that can be broken to allow the header to work.

Closed 2023-05-24.

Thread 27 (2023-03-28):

When USB cable is plugged in, 3.3v is present when the power switch is open

dajtxx, 2023-03-28:
If the power switch is open or absent and the USB-C cable is plugged in, the board is powered and the ESP-32 runs.

dajtxx, 2023-03-29:
It seems the USB-UART bridge has a voltage regulator in it which can be powered from the USB cable or from an external 3.3v regulator. The Wombat seems to have the IC's on board regulator powered from the USB cable and connected to the main 3.3v bus so it tries to run the whole board.

The board takes more than the 100 mA the regulator can supply and if you don't have another source of power present the regulator on the IC burns out.

On this board the battery 3.3v regulator also failed. We don't know if it is related.

Because this IC is causing two problems we should consider leaving it off the next batch of boards, like we did with the earlier ones.

dajtxx, 2023-03-30:
Current thinking is we use option 3 from the data sheet and power the IC from the 3.3v bus. This means it won't work unless the batteries are connected and should stop the IC's own regulator from trying to power the board.

dajtxx, 2023-04-11:
I just tried running a board from the programming header with no batteries installed. F2 blew.

dajtxx, 2023-05-24:
On board rev 1.0.2 the USB-UART bridge no longer tries to power the board and it is safe to plug a USB cable in. The IC is not powered until some other source of power is available.

Closed 2023-05-24.

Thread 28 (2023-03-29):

Enabling the SDI-12 power line while the modem is on seems to make the modem lose state

dajtxx, 2023-03-29:
The current firmware that seems to work fine on the older boards switches the modem on, connects to the network, gets the time, and then brings up the packet switched layer.

Next it enables the SDI-12 power, scans the SDI-12 bus, and reads any sensors found and disables the SDI-12 power.

Finally it uses the modem's MQTT stack to send the message.

The modem seems to lose some state on the new boards with this sequence. The network connection LED goes out temporarily when the SDI-12 power is enabled, and then the MQTT login command fails after the sensors are read.

As a test the firmware was changed to enable the SDI-12 power line at boot and then leave it on the entire time, and no sensors were scanned or read. The modem could then do the MQTT uplinks.

The next test will be to scan and read the sensors and see if it still works.

dajtxx, 2023-04-13:
A new switch IC was added in front of the 12v step-up converter. The data sheet for this says switching it on can cause an inrush current to charge the output capacitor and this may lead to a drop on the input voltage. This input voltage is coming from the VBAT bus, which also powers the modem.

So it could be this new switch is causing the trouble for the modem, because this inrush and voltage drop would not happen on the old board that doesn't have the switch.

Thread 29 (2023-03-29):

The R500S modem should not need the PWR_ON pin connected

dajtxx, 2023-03-29:
According to the implementation guide the R500S we're using does not need the PWR_ON pin connected for the modem to work - supplying VCC should be enough.

We should test this. With the current circuit we can simulate this by keep Q4 open so the PWR_ON signal is taken high by the internal pull-up resistor in the modem.

If it works we could remove Q4 and free up an I/O pin.

However we must read the datasheet and see if PWR_ON is used for resetting the modem or similar. If so it might be useful to be able to control it.

dajtxx, 2023-03-30:
Saw a failure where toggling this pin seemed to bring the modem back. So we'll leave it for now.

Closed 2023-03-30.

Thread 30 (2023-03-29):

Uplink code does not check if bringing up the packet switched layer worked

dajtxx, 2023-03-29:
The uplink code calls connect_to_internet() but does not check the return value.

It should return early if the connection fails rather than reporting a failure for every file to be sent.

dajtxx, 2023-03-29:
A related problem that can be fixed at the same time is that if the modem becomes unresponsive after bringing up the packet switched layer and is rebooted using the PWR_ON pin, connect_to_internet does not redo the packet switched layer initialisation.

dajtxx, 2023-09-18:
Fixed by commit e0aa61ab640c73cc5ac78de84d5e4e112f5fe715.

Closed 2023-09-18.

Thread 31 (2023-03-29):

CLI command 'c1 pwr 1' hangs

dajtxx, 2023-03-29:
Trying to switch the modem power on from the CLI causes a hang.

This works fine on the older boards.

Maybe related to issue #28

dajtxx, 2023-03-30:
Caused by #26 , duplicate.

Closed 2023-03-30.

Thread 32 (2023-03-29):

Enable the battery charger temperature input

dajtxx, 2023-03-29:
The battery charger IC ha an input to avoid charging when the temperature is too high. We could look into connecting it given the boxes will be in hot places.

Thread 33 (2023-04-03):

Battery monitor does not work when solar panel voltage is high

dajtxx, 2023-04-03:
The ESP32 gets read errors when trying to read the battery voltage from the battery monitor IC U8 (INA219B), when it is charging the batter. Additionally, the readings seem to be incorrect when the solar panel is supplying between 8.4 and about 14 volts; they read ~3.4 volts even when the batteries are charged above 4 volts.

This part of the circuit does not seem to have changed from the old boards, which work fine.

We had a question from the people who manufactured the boards about U7 because the part number we gave them had the wrong footprint. Assuming the rest of the part number was correct we advised to use the same part number but with the correct footprint. To see if this was the problem we cut the trace from U7 to the VBAT bus, and the problem persisted so we do not think U7 is the problem.

The solar monitoring IC U4 is the same IC and circuit and it works ok whether charging or not.

The differences are that the IC address pins on the battery monitor are tied to VBAT whereas the solar monitoring IC address pins are tied to GND so not changing voltage.

We are wondering if powering the battery monitor IC from 3.3V and connecting its address pins to 3.3V will solve the problem.

dajtxx, 2023-04-13:
We hacked a board to connect the battery monitor IC VS/A0/A1 lines to +3.3v and the problem went away.

dajtxx, 2023-05-24:
Board rev 1.0.2 uses +3.3v for the power and address lines, fixing the problem.

Closed 2023-05-24.

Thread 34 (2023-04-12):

Digital input does not work with ULP

dajtxx, 2023-04-12:
In the latest revision of the board the digital input and piezo buzzer GPIOs were swapped. The GPIO connected to the digital input connector cannot be used by the ULP so the rain gauge doesn't work.

Additionally, we do not want R42 and R43 populated on the boards. These stop the GPIO pin seeing the rain gauge switch closing.

The code uses an internal pull-up on the GPIO.

dajtxx, 2023-04-12:
Make a dummy rain gauge. This is a momentary contact switch with a 1k resistor in series.

dajtxx, 2023-05-24:
Board rev 1.0.2 fixes both of this issue.

Closed 2023-05-24.

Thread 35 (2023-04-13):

Consider making the digital input pull up/down resistor footprints bigger

dajtxx, 2023-04-13:
The optional pull up/down resistors on the digital input line will be difficult to solder in with the small SMD footprints and where they are on the board.

Consider moving them and using a larger SMD footprint or through hole pads.

dajtxx, 2023-05-24:
These footprints have been changed to through-hole.

Closed 2023-05-24.

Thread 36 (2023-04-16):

Consider replaceable fuses

dajtxx, 2023-04-16:
It seems to be very easy to blow fuses while probing around or plugging power sources in when there are no batteries.

Consider using replaceable fuse holders.

dajtxx, 2023-05-24:
We decided against this because the fuse holder footprint is too large and would require a lot of PCB layout changes.

Closed 2023-05-24.

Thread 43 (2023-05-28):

Include SDI-12 serial numbers in the uplink message

dajtxx, 2023-05-28:
The SCMN wants the sensor serial numbers sent with the uplinks for data quality purposes.

The easiest ways seems to be to send the sensor serial number in every message.

If we try to optimize when we send this info there are many cases where the info can be missed, or comes too late.

dajtxx, 2023-05-29:
Also include the SIM card id.

Closed 2023-07-24.

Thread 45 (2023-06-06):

Allow the sensor definition file to be updated remotely

dajtxx, 2023-06-06:
It would be useful to allow the [sdi12defn.json](https://github.com/DPIclimate/enviro-node/blob/f32166787af22bb262b6acf06ffee91848f10b6f/firmware/wombat/data/sdi12defn.json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) file to be updated remotely.

dajtxx, 2023-08-21:
Fixed in commit 0f0b933dda83d1d3da2a0677a87e6384d95abf0e.

Closed 2023-08-21.

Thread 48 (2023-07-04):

Config download with save command overwrites current message if no reboot is included

dajtxx, 2023-07-04:
I think the bug is to do with SPIFFS. There is a SPIFFS file open - the current message file, and if a config download happens with a `config save` command in it, it looks like it replaces the open file descriptor or something.

Notice the published message is the same as the config file that was received. The SPIFFS message file is open but not read from when the config is saved, then the message file is read, and it's like the config file is read instead.

```
13:46:06.777 > [ 29738][I][mqtt_stack.cpp:84] mqtt_login(): [mqtt_stack] MQTT client id: wB8D61A4142EC
13:46:06.777 > AT+UMQTT=0,"wB8D61A4142EC"
13:46:06.777 >
13:46:06.777 > OK
13:46:06.809 > AT+UMQTTC=1
13:46:06.809 >
13:46:06.809 > OK
13:46:12.851 > [ 35787][I][mqtt_stack.cpp:36] mqttCmdCallback(): [mqtt_stack] cmd: 1, result: 1
13:46:12.852 > bufferedPoll processed event: +UUMQTTC: 1,1
13:46:12.852 > [ 35788][I][mqtt_stack.cpp:108] mqtt_login(): [mqtt_stack] Connected to MQTT
13:46:12.852 > AT+UMQTTC=4,1,"wombat/B8D61A4142EC"
13:46:12.852 >
13:46:12.852 > OK
13:46:12.852 > [ 35811][I][mqtt_stack.cpp:115] mqtt_login(): [mqtt_stack] Waiting for subscribe URC
13:46:12.995 > [ 35973][I][mqtt_stack.cpp:36] mqttCmdCallback(): [mqtt_stack] cmd: 4, result: 1
13:46:13.048 > bufferedPoll processed event: +UUMQTTC: 4,1,1,"wombat/B8D61A4142EC"
13:46:13.048 > [ 35984][I][mqtt_stack.cpp:36] mqttCmdCallback(): [mqtt_stack] cmd: 6, result: 1
13:46:13.048 > bufferedPoll processed event: +UUMQTTC: 6,1
13:46:13.048 > [ 35995][I][mqtt_stack.cpp:120] mqtt_login(): [mqtt_stack] Checking if read URC arrived after subscribe
13:46:13.048 > [ 35995][I][mqtt_stack.cpp:123] mqtt_login(): [mqtt_stack] Config download waiting.
13:46:13.048 > AT+UMQTTC=6,1
13:46:13.344 >
13:46:13.344 > +UMQTTC: 6,1,113,19,"wombat/B8D61A4142EC",94,"mqtt host xxxx
13:46:13.344 > mqtt port xxxx
13:46:13.344 > mqtt user xxxx
13:46:13.344 > mqtt password xxxx
13:46:13.344 > config save
13:46:13.344 >
13:46:13.344 > "
13:46:13.344 >
13:46:13.344 > OK
13:46:13.344 > AT+UMQTTC=2,0,1,0,"wombat/B8D61A4142EC",""
13:46:14.363 > [ 37307][I][mqtt_stack.cpp:36] mqttCmdCallback(): [mqtt_stack] cmd: 2, result: 1
13:46:14.363 > bufferedPoll processed event: +UUMQTTC: 2,1
13:46:14.363 > [ 37308][I][mqtt_stack.cpp:36] mqttCmdCallback(): [mqtt_stack] cmd: 6, result: 1
13:46:14.363 > bufferedPoll processed event: +UUMQTTC: 6,1
13:46:14.363 > [ 37344][I][mqtt_stack.cpp:153] mqtt_login(): [mqtt_stack] Command: [mqtt host xxxx]
13:46:14.406 > [ 37345][I][mqtt_stack.cpp:157] mqtt_login(): [mqtt_stack] OK
13:46:14.406 >
13:46:14.406 > [ 37347][I][mqtt_stack.cpp:153] mqtt_login(): [mqtt_stack] Command: [mqtt port xxxx]
13:46:14.406 > [ 37355][I][mqtt_stack.cpp:157] mqtt_login(): [mqtt_stack] OK
13:46:14.406 >
13:46:14.406 > [ 37361][I][mqtt_stack.cpp:153] mqtt_login(): [mqtt_stack] Command: [mqtt user xxxx]
13:46:14.406 > [ 37368][I][mqtt_stack.cpp:157] mqtt_login(): [mqtt_stack] OK
13:46:14.406 >
13:46:14.406 > [ 37374][I][mqtt_stack.cpp:153] mqtt_login(): [mqtt_stack] Command: [mqtt password xxxx]
13:46:14.443 > [ 37382][I][mqtt_stack.cpp:157] mqtt_login(): [mqtt_stack] OK
13:46:14.443 >
13:46:14.443 > [ 37387][I][mqtt_stack.cpp:153] mqtt_login(): [mqtt_stack] Command: [config save]
13:46:14.443 > [ 37395][W][SPIFFS.cpp:71] begin(): SPIFFS Already Mounted!
13:46:14.959 > [ 37889][I][mqtt_stack.cpp:157] mqtt_login(): [mqtt_stack] Configuration saved
13:46:14.960 > OK
13:46:14.960 >
13:46:14.960 > [ 37890][I][mqtt_stack.cpp:193] mqtt_publish(): [mqtt_stack] Publish message: wombat/mqtt host xxxx
13:46:14.960 > mqtt port xxxx
13:46:14.960 > mqtt user xxxx
13:46:14.960 > mqtt password xxxx
13:46:14.960 > config save
13:46:14.960 >
13:46:14.960 >
13:46:14.960 > AT+UMQTTC=9,0,0,"wombat",940
13:46:14.960 >
13:46:14.960 > >mqtt host xxxx
13:46:14.960 > mqtt port xxxx
13:46:14.960 > mqtt user xxxx
13:46:14.960 > mqtt password xxxx
13:46:14.960 > config save
13:46:14.960 >
13:46:15.974 > [ 38919][E][mqtt_stack.cpp:196] mqtt_publish(): [mqtt_stack] Publish failed
13:46:15.975 > [ 38919][I][uplinks.cpp:94] send_messages(): [uplinks] Processed 1 files with 1 upload errors
13:46:15.975 > [ 38923][I][mqtt_stack.cpp:176] mqtt_logout(): [mqtt_stack] logout
13:46:15.975 > AT+UMQTTC=0
13:56:15.638 > [638457][I][mqtt_stack.cpp:36] mqttCmdCallback(): [mqtt_stack] cmd: 0, result: 100
13:56:15.638 > bufferedPoll processed event: +UUMQTTC: 0,100
13:56:15.638 > [638458][I][main.cpp:301] setup(): [wombat] Shutting down
13:56:15.638 > AT+CPWROFF
13:56:18.416 >
13:56:18.417 > OK
13:56:18.417 > [641246][I][CAT_M1.cpp:27] power_supply(): [CAT_M1] state = 0
13:56:18.432 > [641280][I][Utils.cpp:261] disable12V(): [utils] Disabling SDI-12 power line
13:56:18.489 > [641302][I][main.cpp:341] setup(): [wombat] Unadjusted sleep_time = 258698000
13:56:18.489 > [641303][I][main.cpp:343] setup(): [wombat] Adjusted sleep_time = 258698000
13:56:18.489 > [641305][I][main.cpp:347] setup(): [wombat] Run took 641302 ms, going to sleep at: 2023-07-04T03:56:17Z, for 258.70 s
```

Closed 2023-07-24.

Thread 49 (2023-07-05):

Wombat sleeps for too long sometimes

dajtxx, 2023-07-05:
While messing about testing MQTT QoS, the following log showed some bugs.

There were still URCs related to the failed publish operations arriving after sending the MQTT logout command and I assume the firmware did not process these carefully enough because it never shows the logout URC.

Additionally, the node decided to sleep for over an hour. There is code that is meant to detect a long run time and adjust for it before sleeping, but that code does not seem to have triggered here because there is a log message associated with it.

Perhaps a rounding error is responsible because the runtime is claimed to be 120918ms, and the sleep interval is 120s, so the code ran long, but less than 1s long. I think this lead to an unsigned int problem due to the subtraction [here](https://github.com/DPIclimate/enviro-node/blob/master/firmware/wombat/src/main.cpp#L347) because the result would have been negative.

This is probably 2 bugs - one for not processing MQTT URCs correctly, and one for the long sleep.

```
13:35:51.109 > [  5526][I][main.cpp:277] setup(): [wombat] Boot count: 0, measurement interval: 120, uplink interval: 240, uplink_interval_secs/measurement_interval_secs: 2, uplink this cycle: 1
...
13:36:00.671 > [ 15100][I][Utils.cpp:399] connect_to_internet(): [utils] Modem response: 23/07/05,13:36:00+40
13:36:00.671 > [ 15101][I][Utils.cpp:408] connect_to_internet(): [utils] RTC time now: 2023-07-05T03:35:59Z
13:36:00.671 > [ 15109][I][Utils.cpp:426] connect_to_internet(): [utils] Network time: 05/07/0123 13:36:00 40
13:36:00.671 > [ 15117][I][Utils.cpp:440] connect_to_internet(): [utils] Epoch: 1688528160
...
13:37:15.250 > [ 89683][I][uplinks.cpp:29] process_file(): [uplinks] Processing message file [msg_2023-07-05T03:36:02Z.json]
13:37:15.250 > [ 89686][I][mqtt_stack.cpp:193] mqtt_publish(): [mqtt_stack] Publish message: wombat/{"timestamp":"2023-07-05T03:36:02Z","source_ids":{"serial_no":"B8D61A4142EC","sdi-12":["113METER   TER12 201T12-00082937","213METER   TER11 301T11-00019674","313METER   TER11 302T11-00025251","413METER   TER11 301T11-00019680","513METER   TER11 301T11-00019675","613METER   TER11 301T11-00019688"]},"timeseries":[{"name":"battery (v)","value":4.051980019},{"name":"solar (v)","value":0.163980007},{"name":"pulse_count","value":0},{"name":"shortest_pulse","value":0},{"name":"1_VWC","value":1826.72998},{"name":"1_Temperature","value":17.79999924},{"name":"2_VWC","value":1820.819946},{"name":"2_Temperature","value":17.89999962},{"name":"3_VWC","value":1815.97998},{"name":"3_Temperature","value":18},{"name":"4_VWC","value":-9992},{"name":"4_Temperature","value":17.70000076},{"name":"5_VWC","value":1835.410034},{"name":"5_Temperature","value":17.10000038},{"name":"6_VWC","value":-9992},{"name":"6_Temperature","value":17.70000076}],"fw_ver":"1.0.5","commit_id":"9d2045b","repo_status":"dirty"}
13:37:15.339 > AT+UMQTTC=9,2,0,"wombat",997
13:37:15.339 >
13:37:15.339 > ERROR
13:37:15.339 > [ 89793][E][mqtt_stack.cpp:196] mqtt_publish(): [mqtt_stack] Publish failed
13:37:15.789 > [ 90240][I][uplinks.cpp:109] send_messages(): [uplinks] Processed 8 files with 8 upload errors
13:37:15.790 > [ 90241][I][mqtt_stack.cpp:176] mqtt_logout(): [mqtt_stack] logout
13:37:15.790 > AT+UMQTTC=0
13:37:15.790 >
13:37:15.790 > OK
13:37:43.407 > [117841][I][mqtt_stack.cpp:36] mqttCmdCallback(): [mqtt_stack] cmd: 9, result: 0
13:37:43.407 > AT+UMQTTER
13:37:43.407 >
13:37:43.407 > +UMQTTER: 13,33
13:37:43.407 >
13:37:43.407 > OK
13:37:43.407 > [117850][E][mqtt_stack.cpp:42] mqttCmdCallback(): [mqtt_stack] MQTT op failed: 13, 33
13:37:43.407 > bufferedPoll processed event: +UUMQTTC: 9,0
13:37:43.407 > [117861][I][main.cpp:301] setup(): [wombat] Shutting down
13:37:43.407 > AT+CPWROFF
13:37:46.405 >
13:37:46.405 > OK
13:37:46.405 > [120861][I][CAT_M1.cpp:27] power_supply(): [CAT_M1] state = 0
13:37:46.421 > [120896][I][Utils.cpp:261] disable12V(): [utils] Disabling SDI-12 power line
13:37:46.478 > [120919][I][main.cpp:341] setup(): [wombat] Unadjusted sleep_time = 4294049296
13:37:46.478 > [120919][I][main.cpp:343] setup(): [wombat] Adjusted sleep_time = 4294049280
13:37:46.478 > [120921][I][main.cpp:347] setup(): [wombat] Run took 120918 ms, going to sleep at: 2023-07-05T03:37:45Z, for 4294.05 s
```

dajtxx, 2023-07-09:
This can be caused by the sleep time adjustment code. I do not know if that is the *only* cause, but it is one cause.

The sleep_drift_adjustment variable is set after connecting to the mobile network and retrieving the network time [here](https://github.com/DPIclimate/enviro-node/blob/master/firmware/wombat/src/Utils.cpp#L452).

In one sample run, this results in:

```
20:32:01.990 > [ 11081][I][Utils.cpp:399] connect_to_internet(): [utils] Modem response: 23/07/09,20:32:01+40
20:32:01.990 > [ 11082][I][Utils.cpp:408] connect_to_internet(): [utils] RTC time now: 2023-07-09T10:31:59Z
20:32:01.990 > [ 11090][I][Utils.cpp:426] connect_to_internet(): [utils] Network time: 09/07/0123 20:32:01 40
20:32:01.990 > [ 11098][I][Utils.cpp:440] connect_to_internet(): [utils] Epoch: 1688898721
20:32:01.990 > [ 11105][I][Utils.cpp:454] connect_to_internet(): [utils] Previous seconds value: 59, sleep adjustment: 58
```

The ESP32 RTC is 2 seconds behind network time, but because the code only uses the seconds values without considering whether the RTC is fast or slow, the calculation is `59 - 1 = 58`.

Then when the time to sleep it calculated [here](https://github.com/DPIclimate/enviro-node/blob/master/firmware/wombat/src/main.cpp#L347) an extra 58 seconds is added to the sleep time so the Wombat slept for 143 seconds rather than 58 seconds.

dajtxx, 2023-07-12:
The current solution to this issue ignores clock drift. Working with the epoch values might be a better way than the last attempt that only worked with seconds and only in one direction.

Closed 2023-07-24.

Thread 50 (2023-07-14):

A couple of Wombats stop running between early afternoon and sunset

dajtxx, 2023-07-14:
Two of the initial installation are stopping around early afternoon and coming back at about sunset.

This started 3 days ago, before that they were fine.

It seems the ESP32 is not getting powered up because none of the missing messages are coming through after it wakes up.

I don't think the modem is the problem because it can handle up to 4.6v and we don't seem to be getting over 4.2v.

Could it be the 3.3v regulator, or components around it?

dajtxx, 2023-07-26:
Pretty sure this was due to the sleep time bugs that were fixed because since getting the new firmware the problem does not seem to happen.

But this bug can stay open for a couple more weeks in case the problem shows up again.

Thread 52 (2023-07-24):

Firmware logs network time year as 0123

dajtxx, 2023-07-24:
The tm.year member is 'years since 1900'. The modem gives the year as 2 digits, eg '23', and the firmware adds 100 to that to get the correct value for tm.year for use in calculating the epoch value. This is all correct and works.

There is a log message that shows the values of the tm structure and it uses the raw tm.year value, meaning it shows up as 0123:

`[ 16029][I][Utils.cpp:424] connect_to_internet(): [utils] Network time: 24/07/0123 16:06:34 40`

That log message should have 1900 added to tm.year to make it look right.

mariusCZ, 2023-07-27:
Any way to test this without the hardware? I can get my hands on an ESP32, but not on the full hardware stack.

dajtxx, 2023-07-27:
You could test it if you had a Sara R5 breakout board, like from Sparkfun. If you went that route you could hard-code the flag that causes the firmware to drop into the command line to true, ignore the various errors about missing hardware, and use the `c1 cti` command to wake the modem up and get the network time.

You'd need to ensure the ESP32 Serial1 pins are used to talk to the modem.

dajtxx, 2023-08-21:
Fixed in commit 0f0b933dda83d1d3da2a0677a87e6384d95abf0e.

Closed 2023-08-21.

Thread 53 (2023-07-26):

Handle bad SDI-12 sensor info strings

dajtxx, 2023-07-26:
If the SDI-12 bus wiring is bad the readings come back as noise and the firmware does not recognise this, then doesn't work properly.

The returned info strings should be checked for compliance with the standard and ignored if they do not comply.

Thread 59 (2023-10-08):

Setting time from modem sometimes fails

dajtxx, 2023-10-08:
The Wombat sets its time from the modem when it registers with the mobile network. This can fail, for example:

```
2023-10-07T10:20:06Z: r5.modulePowerOff
2023-10-07T10:20:09Z: power down SD card
2023-10-07T10:34:42Z: --------------------
2023-10-07T10:34:42Z: Woke up
2023-10-07T10:34:42Z: connect_to_internet
2023-10-07T10:34:50Z: Getting network time
2014-12-31T13:00:06Z: Starting PDP
2014-12-31T13:00:06Z: cti returning
2014-12-31T13:00:06Z: init_sensors
2014-12-31T13:00:09Z: Found 6 sensors
```

A potential fix is to store the current time in RTC memory before sleeping and comparing the time returned by the modem with this stored value. If the time returned by the modem is earlier than the stored value, or the year the < 2023, then don't use it.

dajtxx, 2023-11-29:
Using NTP now so no need for this.

Closed 2023-11-29.

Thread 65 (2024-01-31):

Ideas for the next revision of the PCB

dajtxx, 2024-01-31:
More ground terminals.

It looks like the following pins are free, so see if they're usable:

4, 5, 7 are input only as GPIO 35, 36, 39. These are also available to the ULP so might be good as level or edge triggered inputs. These pins are on the top of the module.

17, 18, 19, 20, 21, 22 are GPIO 6 - 11, input and output so could be used to drive something. These pins are on the left side of the module.

dajtxx, 2024-02-08:
Add a DS18B20 temp sensor.

dajtxx, 2024-02-28:
Remove the piezo buzzer?

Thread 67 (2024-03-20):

Dependencies not pinned

dajtxx, 2024-03-20:
While building the binaries for the next batch of boards I'm getting deprecation warnings from the JSON library because a newer version is being used.

There may also a problem with the R5 library because we've made so many changes to it. I need to confirm a clean build installs a version that is workable.

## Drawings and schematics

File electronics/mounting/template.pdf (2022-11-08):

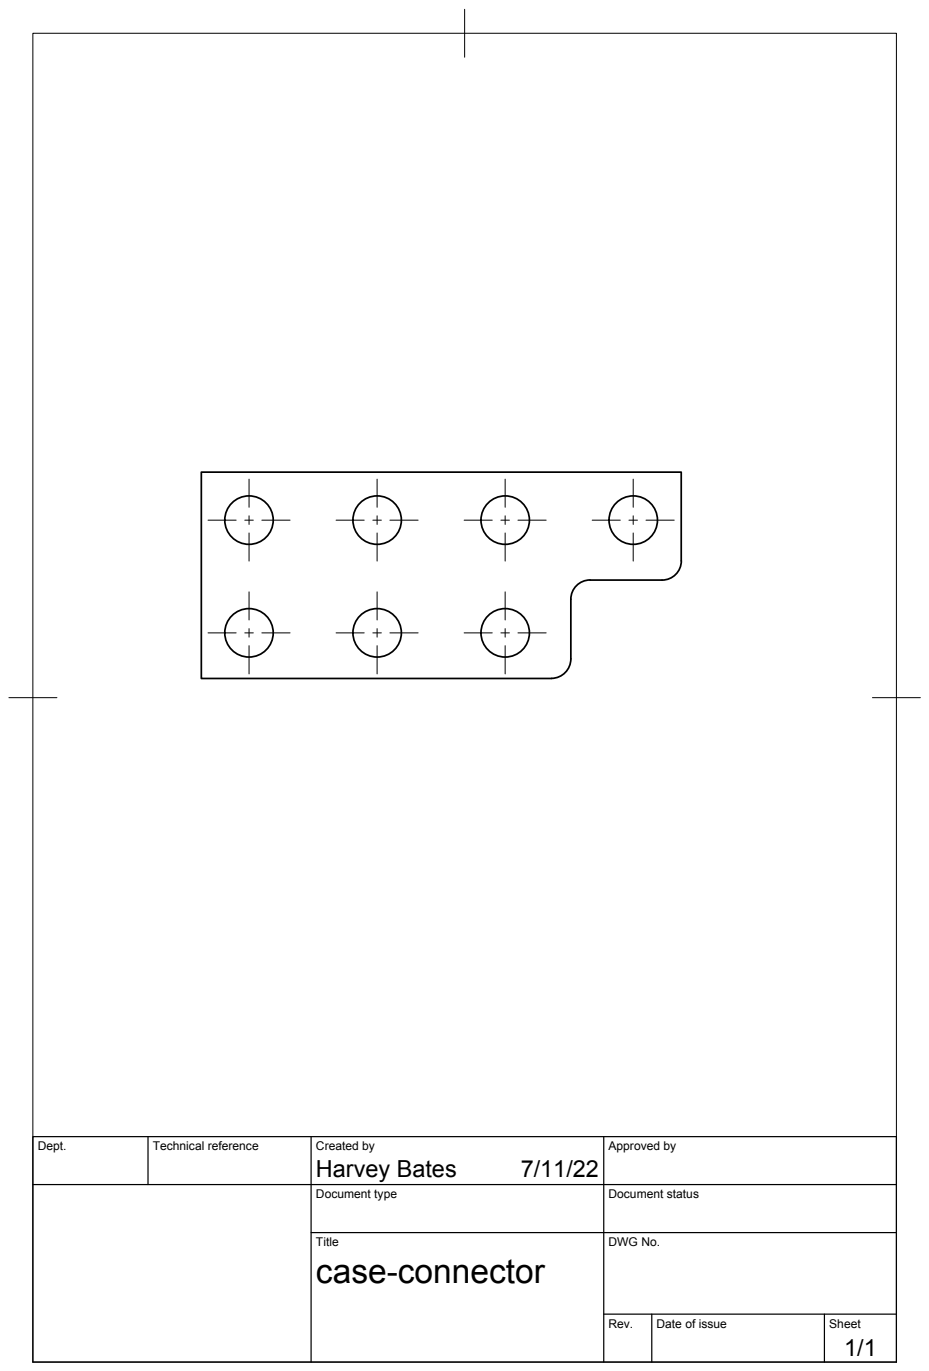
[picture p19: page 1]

Dept. | Technical reference | Created by Harvey Bates 7/11/22 | Approved by

Document type | Document status

Title case-connector | DWG No.

Rev. | Date of issue | Sheet 1/1

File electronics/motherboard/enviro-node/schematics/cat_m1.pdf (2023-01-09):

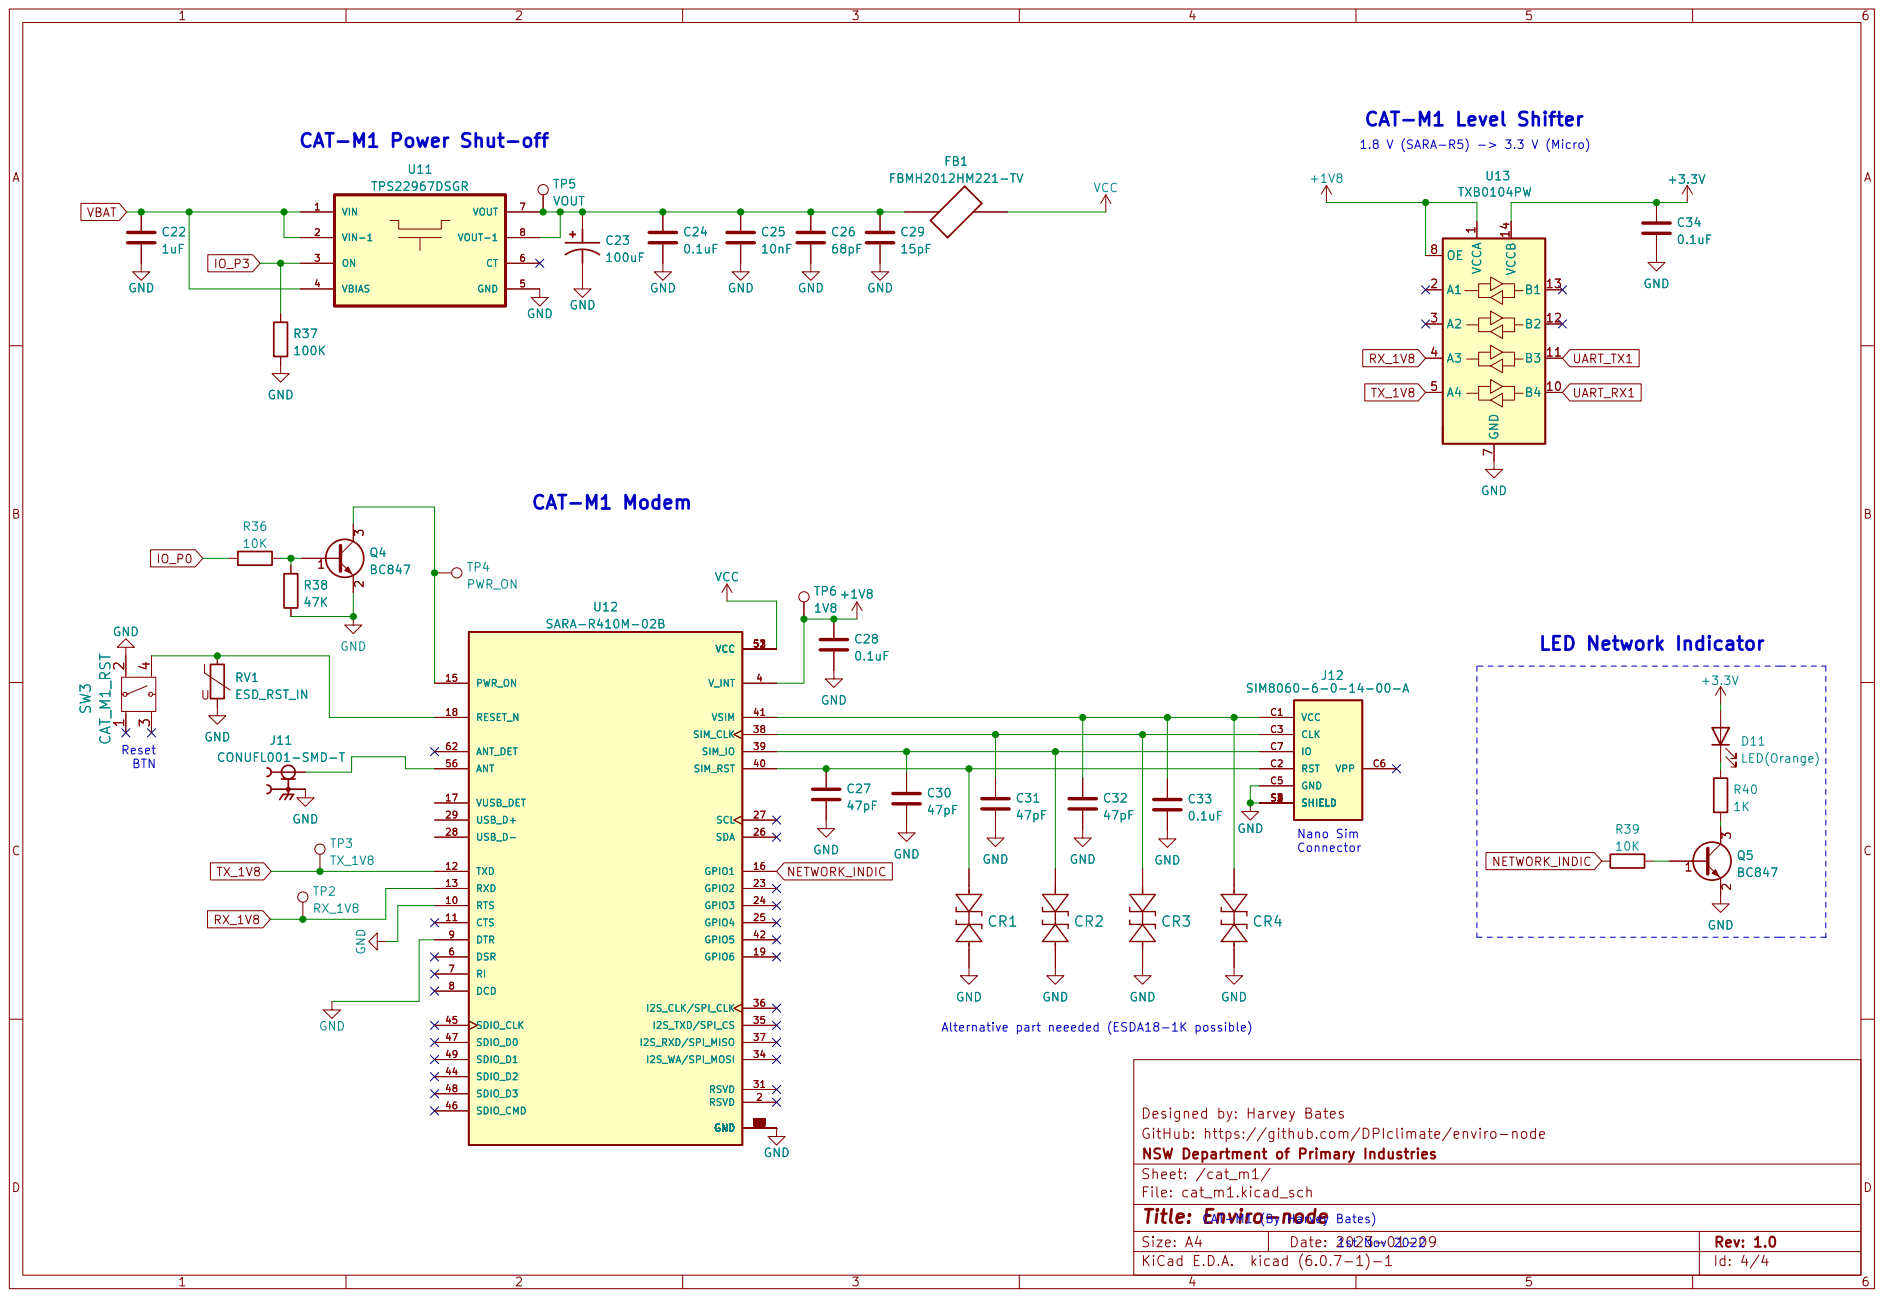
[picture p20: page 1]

CAT-M1 Power Shut-off GND SW3 CAT_M1_RST 1 2
IO_P3 Reset BTN

Nano Sim Connector CAT-M1 (By Harvey Bates)1st Nov 2022 Alternative part neeeded (ESDA18-1K possible)

Designed by: Harvey Bates GND

GitHub: https://github.com/DPIclimate/enviro-node
NSW Department of Primary Industries
Sheet: /cat_m1/
File: cat_m1.kicad_sch
Id: 4/4 Title: Enviro-node

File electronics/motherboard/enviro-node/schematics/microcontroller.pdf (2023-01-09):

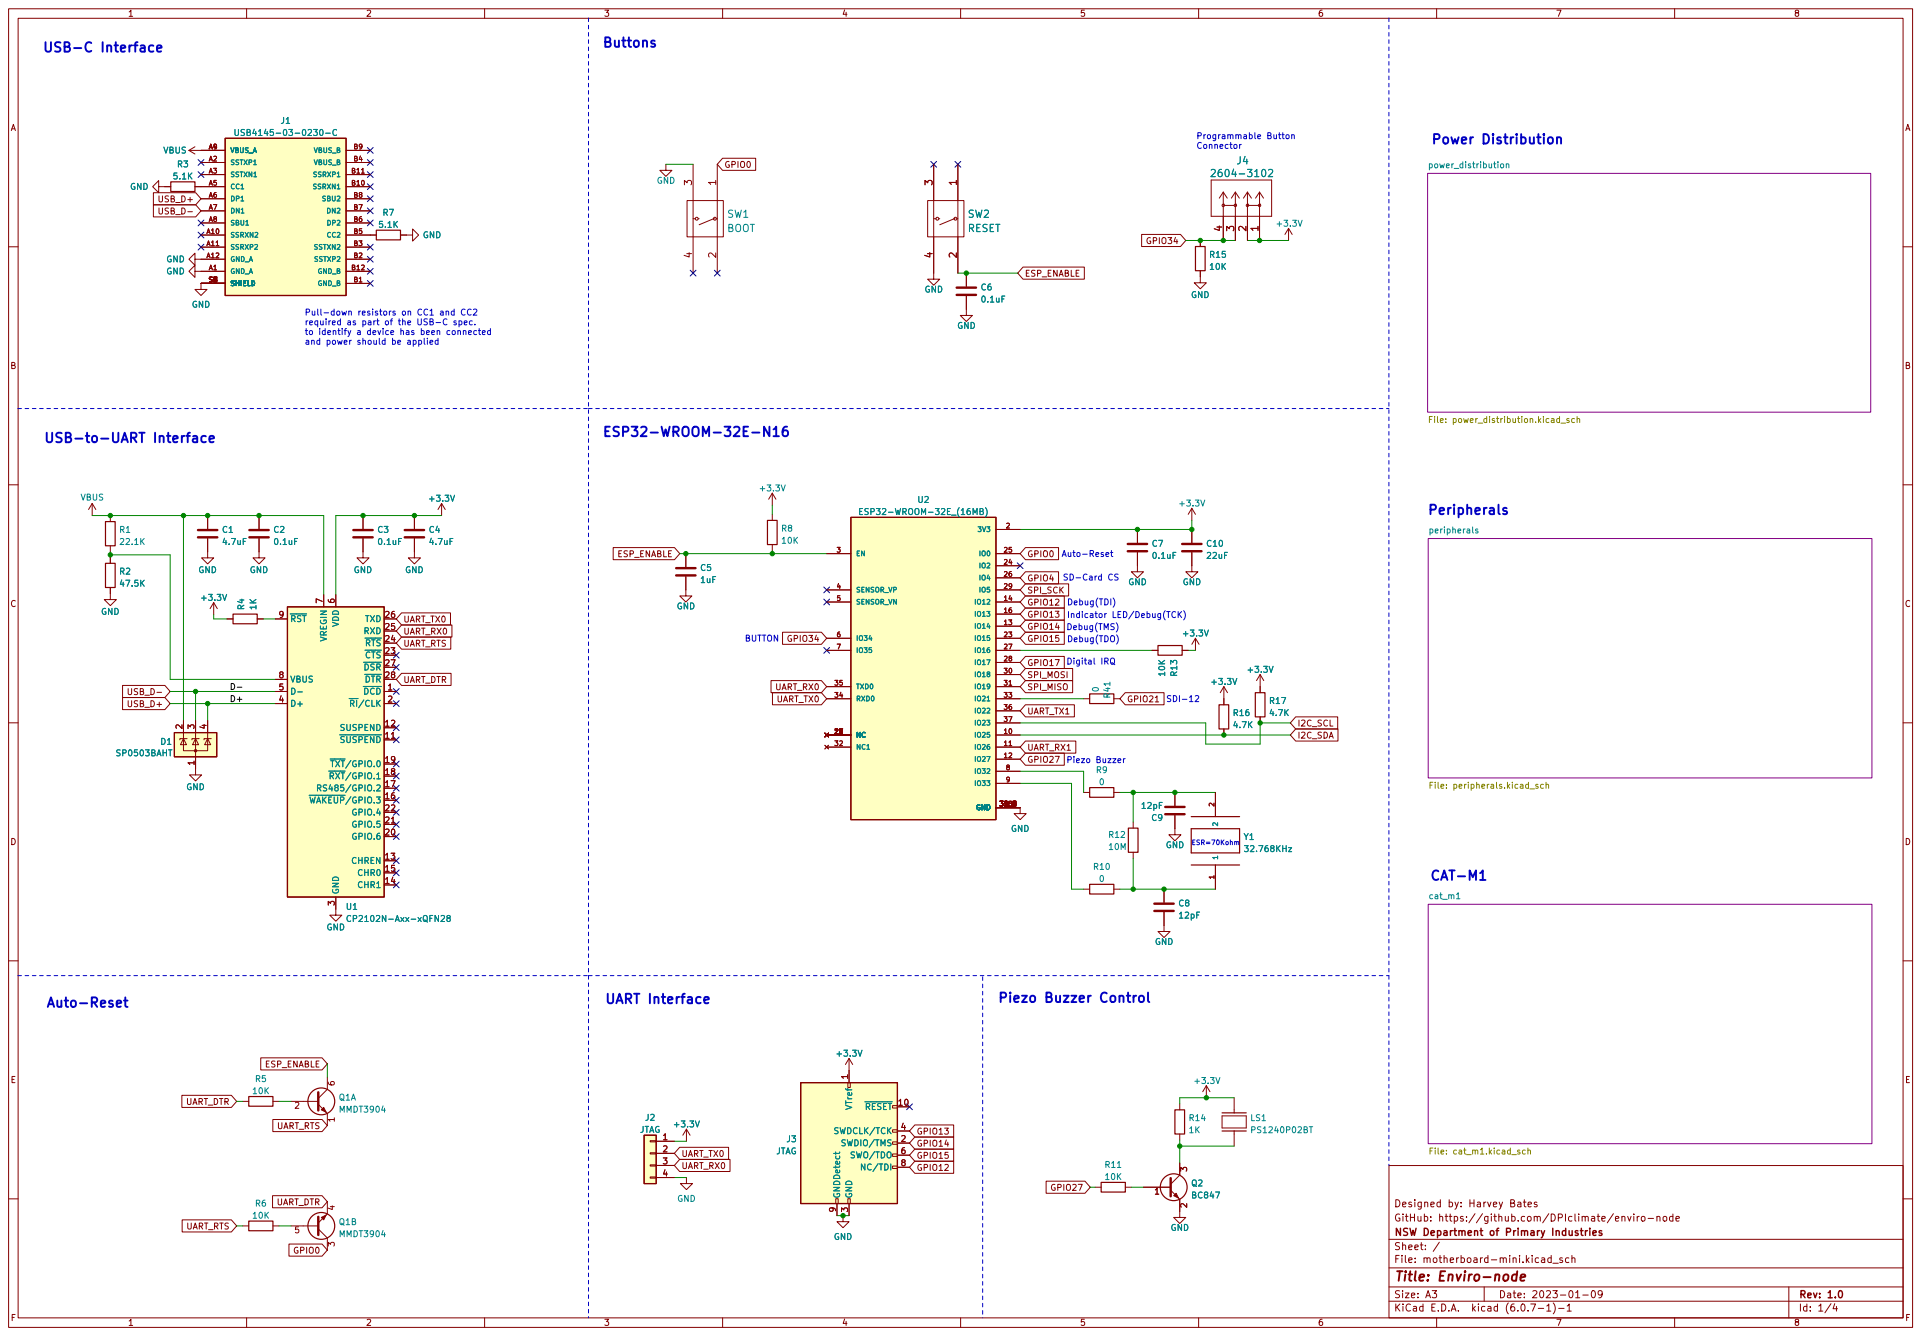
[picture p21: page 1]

Buttons
Programmable Button Connector Debug(TMS)

Pull-down resistors on CC1 and CC2 required as part of the USB-C spec.

to identify a device has been connected
and power should be applied

Indicator LED/Debug(TCK) SD-Card CS ESP32-WROOM-32E-N16

USB-to-UART Interface

Auto-Reset Debug(TDI)

7 VBUS 8 ~{RST} 9 U1CP2102N-Axx-xQFN28 GND

3 SWDCLK/TCK 4 SWO/TDO 6 NC/TDI 8 GNDDetect 9

3 SWDCLK/TCK 4 SWO/TDO 6 NC/TDI 8 GNDDetect 9 GND

Designed by: Harvey Bates
GitHub: https://github.com/DPIclimate/enviro-node
File: motherboard-mini.kicad_sch Sheet: / NSW Department of Primary Industries

Id: 1/4 Title: Enviro-node

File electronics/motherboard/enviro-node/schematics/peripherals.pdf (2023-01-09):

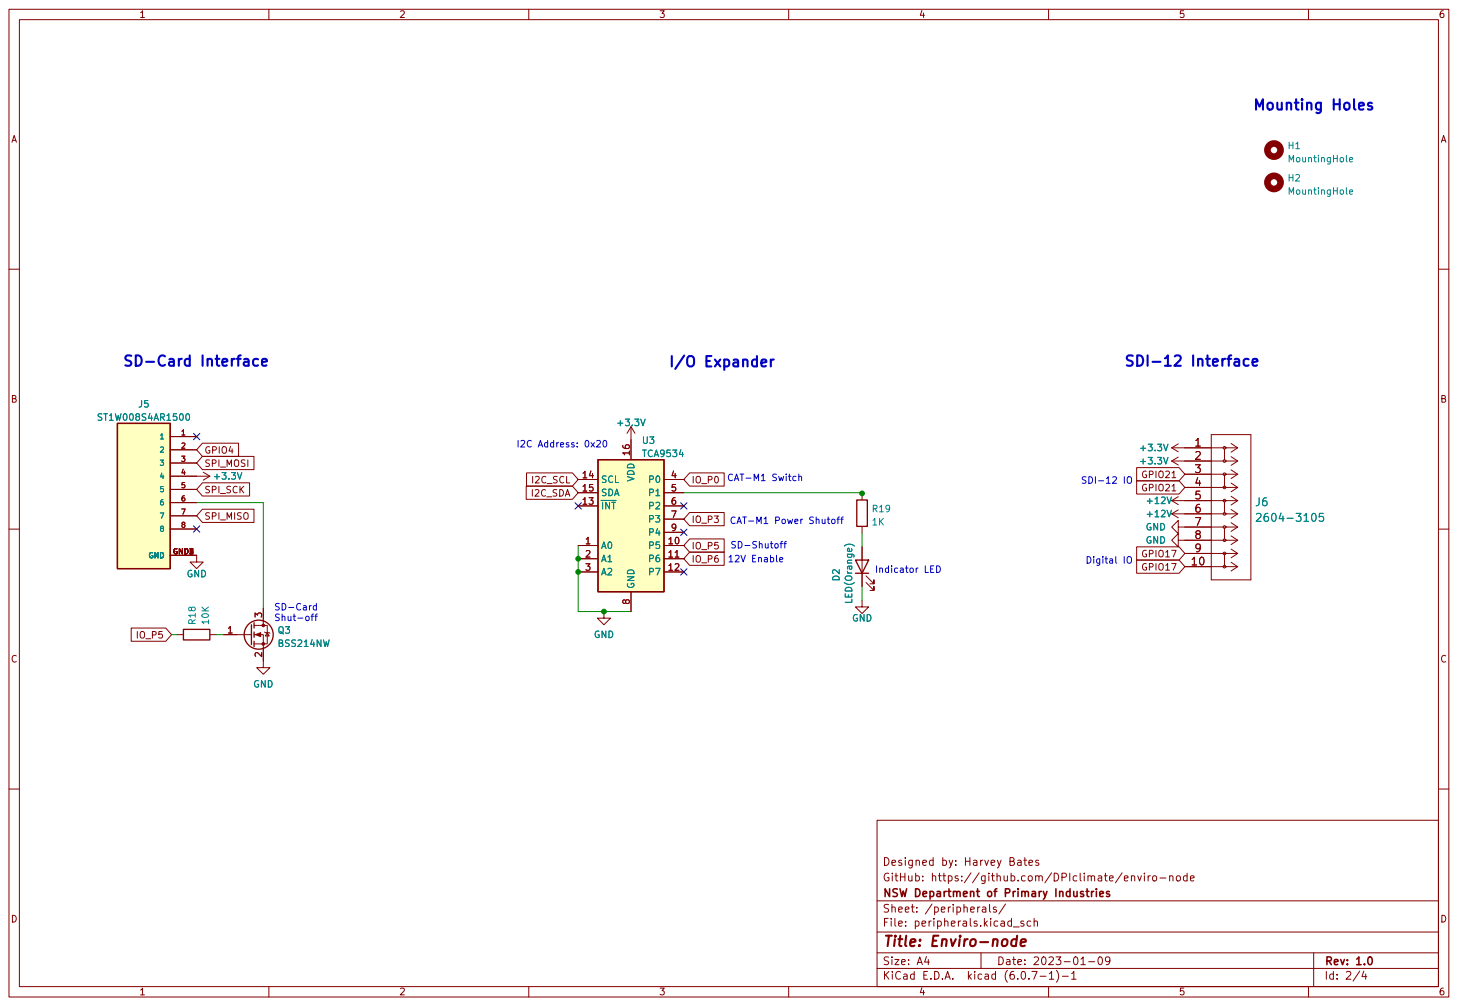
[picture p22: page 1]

Indicator LED SD-Card Interface

GitHub: https://github.com/DPIclimate/enviro-node
NSW Department of Primary Industries
Sheet: /peripherals/
File: peripherals.kicad_sch
Id: 2/4 Title: Enviro-node

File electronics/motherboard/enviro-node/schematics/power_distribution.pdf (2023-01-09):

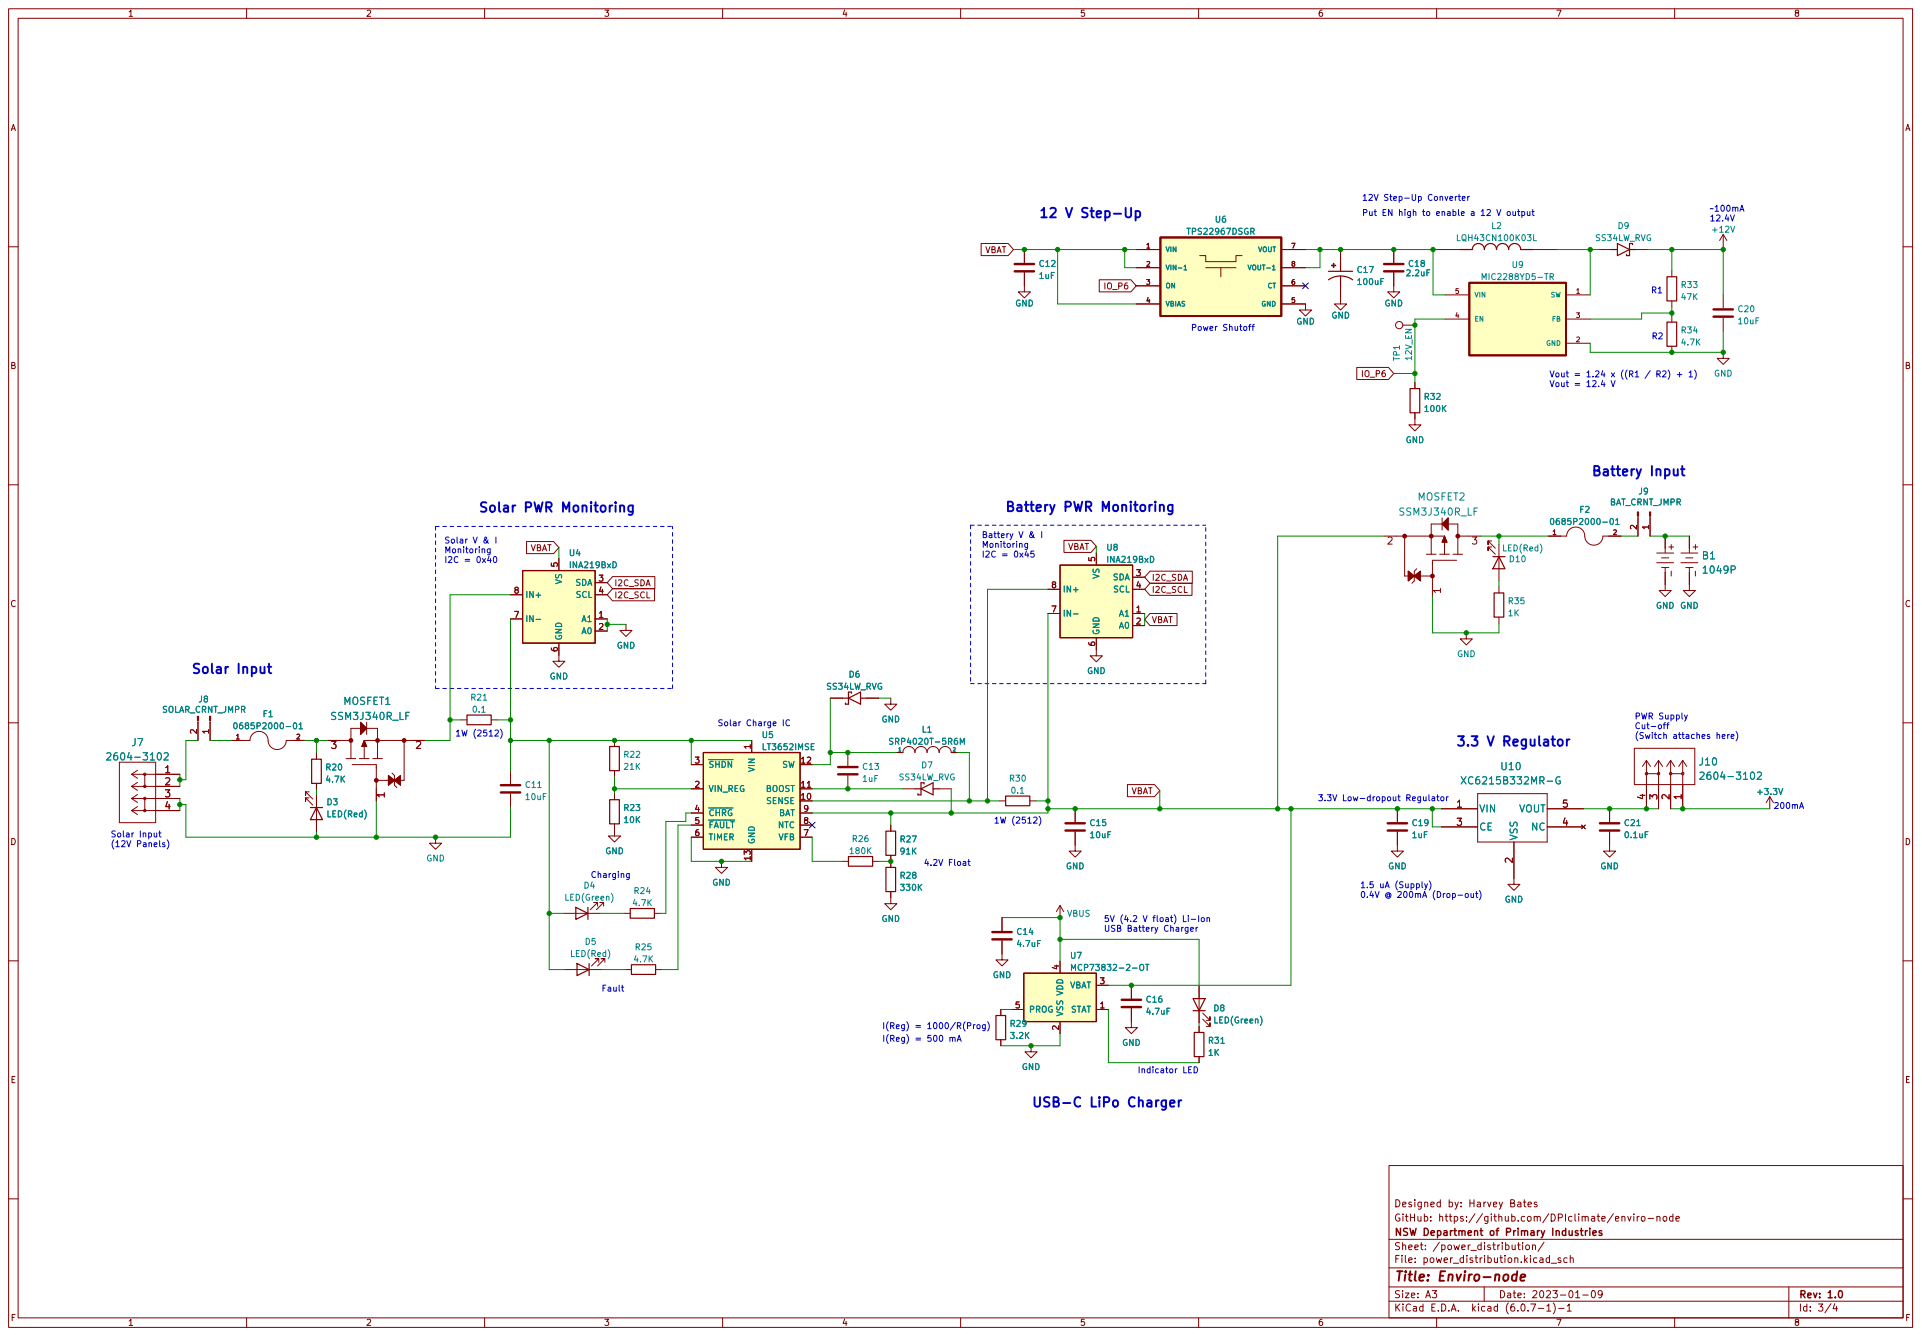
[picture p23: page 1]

Fault Solar PWR Monitoring

R2 PWR Supply Cut-off (Switch attaches here) Solar V & I Monitoring

1 SENSE 10 BOOST 11 SW 12 GND 13 VIN_REG 2 ~{SHDN} 3 ~{CHRG} 4 ~{FAULT} 5 TIMER 6 VFB 7 NTC 8 BAT 9 GND

1 SENSE 10 BOOST 11 SW 12 GND 13 VIN_REG 2 ~{SHDN} 3 ~{CHRG} 4 ~{FAULT} 5 TIMER 6 VFB 7 NTC 8 BAT 9 U5

Designed by: Harvey Bates
GitHub: https://github.com/DPIclimate/enviro-node
NSW Department of Primary Industries
Sheet: /power_distribution/
File: power_distribution.kicad_sch
Id: 3/4 Title: Enviro-node

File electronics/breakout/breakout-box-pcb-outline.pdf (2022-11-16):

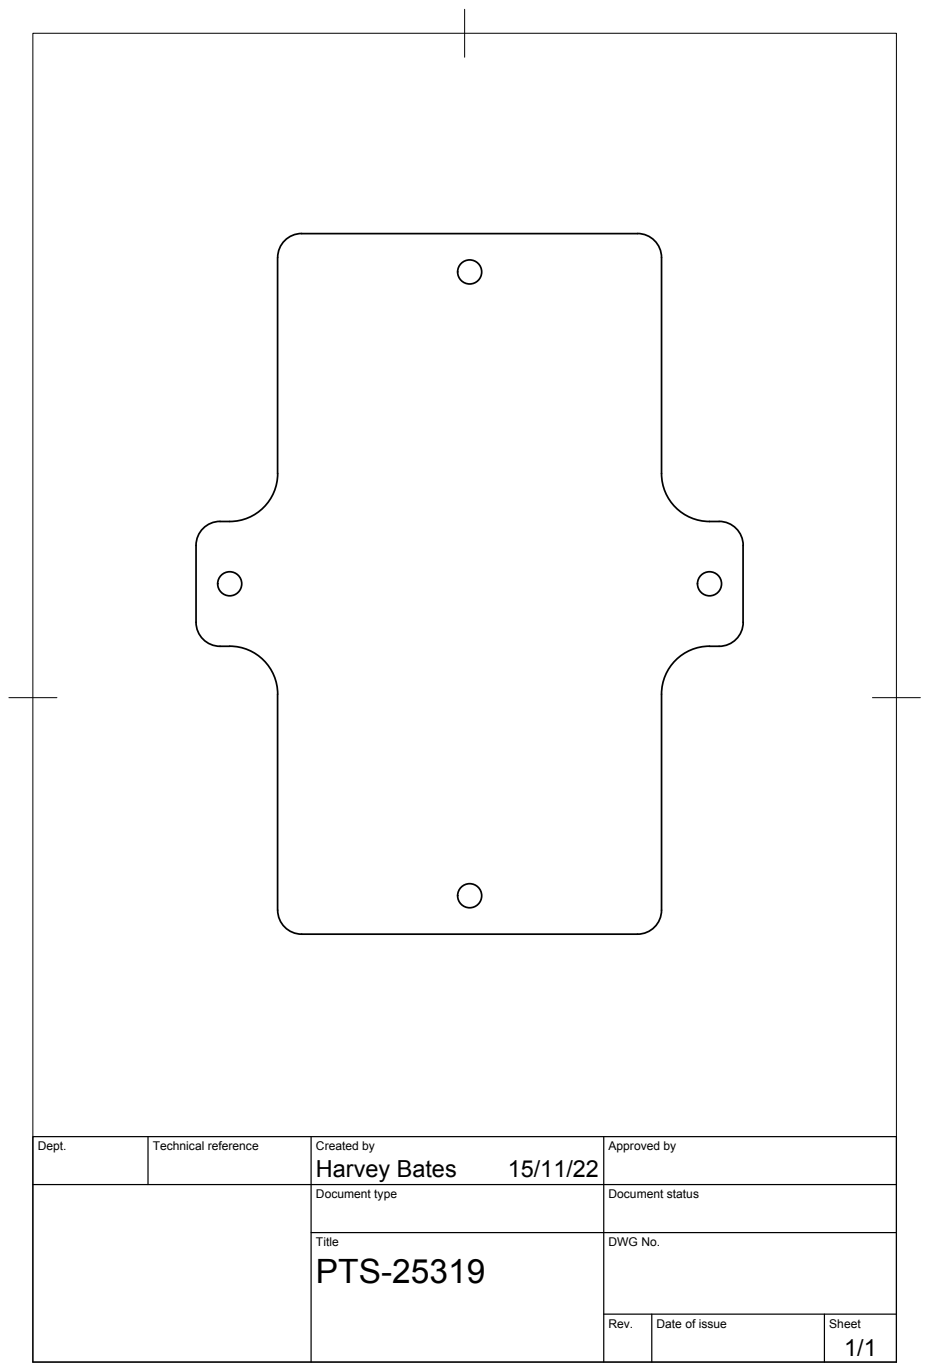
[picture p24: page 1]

Dept. | Technical reference | Created by Harvey Bates 15/11/22 | Approved by

Document type | Document status

Title PTS-25319 | DWG No.

Rev. | Date of issue | Sheet 1/1

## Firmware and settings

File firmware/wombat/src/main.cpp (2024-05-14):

#include <Arduino.h>
#include "version.h"

#include <esp_log.h>

#include <freertos/FreeRTOS.h>

#include <TCA9534.h>
#include <driver/rtc_io.h>
#include <soc/rtc.h>
#include <esp_private/esp_clk.h>
#include <SD.h>
#include <esp_ota_ops.h>
#include <SPIFFS.h>

#define ALLOCATE_GLOBALS
#include "globals.h"
#undef ALLOCATE_GLOBALS

#include "SensorTask.h"
#include "DeviceConfig.h"
#include "cli/CLI.h"
#include "peripherals.h"

#include "audio-feedback/tones.h"
#include "uplinks.h"
#include "ulp.h"

#include "soc/rtc.h"
#include "soc/soc.h"
#include "soc/rtc_cntl_reg.h"
#include "sd-card/interface.h"
#include "freertos/semphr.h"

#include "esp_partition.h"
#include "ota_update.h"
#include "ftp_stack.h"
#include "power_monitoring/battery.h"
#include "power_monitoring/solar.h"

#include "Utils.h"

#define TAG "wombat"

TCA9534 io_expander;

bool spiffs_ok = false;

// Used by OpenOCD.
static volatile int uxTopUsedPriority;

static void select_rtc_slow_clk(void);

//static File *log_file = nullptr;

/*
static vprintf_like_t old_log_fn;
static File *log_file;
constexpr size_t max_log_len = 4096;
static char log_msg[max_log_len+1];

// Maximum time to wait for the mutex in a logging statement.
//
// We don't expect this to happen in most cases, as contention is low. The most likely case is if a
// log function is called from an ISR (technically caller should use the ISR-friendly logging macros but
// possible they use the normal one instead and disable the log type by tag).
#define MAX_MUTEX_WAIT_MS 10
#define MAX_MUTEX_WAIT_TICKS ((MAX_MUTEX_WAIT_MS + portTICK_PERIOD_MS - 1) / portTICK_PERIOD_MS)

static SemaphoreHandle_t s_log_mutex = NULL;

static void esp_log_impl_lock(void)
{
    if (unlikely(!s_log_mutex)) {
        s_log_mutex = xSemaphoreCreateMutex();
    }
    if (unlikely(xTaskGetSchedulerState() == taskSCHEDULER_NOT_STARTED)) {
        return;
    }
    xSemaphoreTake(s_log_mutex, portMAX_DELAY);
}

static void esp_log_impl_unlock(void)
{
    if (unlikely(xTaskGetSchedulerState() == taskSCHEDULER_NOT_STARTED)) {
        return;
    }
    xSemaphoreGive(s_log_mutex);
}

#ifdef __cplusplus
extern "C" {
#endif

int my_log_vprintf(const char *fmt, va_list args) {
    esp_log_impl_lock();

    log_msg[0] = '@';
    log_msg[1] = '|';
    int iresult = vsnprintf(&log_msg[2], max_log_len, fmt, args);
    if (iresult > 0) {
        printf(log_msg);
    }

    esp_log_impl_unlock();

    return iresult;
}

int my_log_printf(const char *fmt, ...) {
    va_list args;
    va_start(args, fmt);
    int rc = my_log_vprintf(fmt, args);
    va_end(args);
    printf("\n");
    Serial.flush();
    return rc;
}

#ifdef __cplusplus
}
#endif
*/

/**
 * A simple timeout task. Runs on core 0 so the app code does not interfere with it.
 *
 * If 14 minutes passes and timeout_restart has not been set to false, power to the
 * modem is shut off and the ESP32 is rebooted.
 *
 * @param pvParameters not used.
 */
[[noreturn]] void timeout_task(void * pvParameters) {
    const TickType_t delay = 60 * 60 * 1000 / portTICK_PERIOD_MS;
    ESP_LOGI(TAG, "Starting");
    while(true) {
        // Set to true here, the app code on core 1 must set it to false before the
        // timeout task wakes up to avoid a reboot.
        timeout_restart = true;
        vTaskDelay(delay);

        if (timeout_active && timeout_restart) {
            log_to_sdcard("[E] timeout_task forced reboot");
            ESP_LOGE(TAG, "Removing power from R5");
            cat_m1.power_supply(false);
            vTaskDelay(5000 / portTICK_PERIOD_MS); // 5s

            ESP_LOGE(TAG, "Rebooting due to app code timeout");
            esp_restart();
        }
    }
}

static TaskHandle_t xHandle = nullptr;

void setup(void) {
    // Disable brown-out detection until the BT LE radio is running.
    // The radio startup triggers a brown out detection, but the
    // voltage seems ok and the node keeps running.
    WRITE_PERI_REG(RTC_CNTL_BROWN_OUT_REG, 0);

    pinMode(PROG_BTN, INPUT);
    progBtnPressed = digitalRead(PROG_BTN);

    // The timeout task is pinned to core 0, which usually runs the wireless stacks. We're not using
    // them so the core is free and this should mean the task is not blocked by anything the app does.
    timeout_active = true;
    static uint8_t ucParameterToPass = 0;
    xTaskCreatePinnedToCore(timeout_task, "Timeout", 4096, &ucParameterToPass, tskIDLE_PRIORITY, &xHandle, 0);
    configASSERT(xHandle);

    // SARA R5 library logging does not work without this.
    Serial.begin(115200);
    while ( ! Serial) {
        delay(1);
    }

    //ESP_LOGI(TAG, "Changing log function");
    //old_log_fn = esp_log_set_vprintf(&my_log_vprintf);

    setenv("TZ", "UTC", 1);
    tzset();

    spiffs_ok = SPIFFS.begin();

    // The device configuration singleton is created on entry to setup() due to C++ object creation rules.
    // The node id is available without loading the configuration because it is retrieved from the ESP32
    // modem during the config.reset() call, not the saved configuration.
    DeviceConfig& config = DeviceConfig::get();
    config.reset();

    //ESP_LOGI(TAG, "Old func: %p", old_log_fn);

    ESP_LOGI(TAG, "Wake up time: %s", iso8601());
    ESP_LOGI(TAG, "CPU MHz: %lu", getCpuFrequencyMhz());

    ESP_LOGI(TAG, "Boot partition");
    const esp_partition_t *p_type = esp_ota_get_boot_partition();
    ESP_LOGI(TAG, "%d/%d %lx %lx %s", p_type->type, p_type->subtype, p_type->address, p_type->size, p_type->label);

    ESP_LOGI(TAG, "App ver: %u.%u.%u, commit: %s, repo status: %s", ver_major, ver_minor, ver_update, commit_id, repo_status);

    // Switch the RTC clock to the external crystal.
    rtc_slow_freq_t rtc_freq = rtc_clk_slow_freq_get();
    if (rtc_freq != RTC_SLOW_FREQ_32K_XTAL) {
        select_rtc_slow_clk();
    }

    // Try to avoid it getting optimized out.
    uxTopUsedPriority = configMAX_PRIORITIES - 1;

    // ==== CAT-M1 Setup START ====
    Wire.begin(GPIO_NUM_25, GPIO_NUM_23);
    io_expander.attach(Wire);
    io_expander.setDeviceAddress(0x20);

    // Set all pins to output mode (reg 3, value 0).
    io_expander.config(TCA9534::Config::OUT);
    digitalWrite(LED_BUILTIN, LOW); // Turn off LED

    // WARNING: The IO expander must be initialised before the SD card is enabled, because the SD card
    // enable line is one of the IO expander pins.
    if (SDCardInterface::begin()) {
        ESP_LOGI(TAG, "SD card initialised");
        //if (SDCardInterface::is_ready()) {
        //    *log_file = SD.open(sd_card_logfile_name, FILE_APPEND, true);
        //}
    } else {
        ESP_LOGW(TAG, "SD card initialisation failed");
    }

    enable12V();
    delay(250);

    cat_m1.begin(io_expander);

    LTE_Serial.begin(115200);
    while(!LTE_Serial) {
        delay(1);
    }

    // ==== CAT-M1 Setup END ====

    digitalWrite(SD_CARD_ENABLE, HIGH);
    if ( ! SD.begin()) {
        ESP_LOGI(TAG, "Failed to initialise SD card");
        digitalWrite(SD_CARD_ENABLE, LOW);
    } else {
        ESP_LOGI(TAG, "SD card initialised");
    }

    log_to_sdcard("--------------------");
    log_to_sdcard("Woke up");

    // This must be done before the config is loaded because the config file is
    // a list of commands.
    CLI::init();
    config.load();
    config.dumpConfig(Serial);

    // Enable the brown out detection now the node has stabilised its
    // current requirements.
    WRITE_PERI_REG(RTC_CNTL_BROWN_OUT_REG, 1);

    delay(100);

    BatteryMonitor::begin();
    SolarMonitor::begin();

//    back_to_factory();
//    ESP_LOGI(TAG, "Boot partition");
//    p_type = esp_ota_get_boot_partition();
//    ESP_LOGI(TAG, "%d/%d %lx %lx %s", p_type->type, p_type->subtype, p_type->address, p_type->size, p_type->label);

    if (config.getBootCount() == 0) {
      ESP_LOGI(TAG, "Starting ULP processing");
      initULP();
    }

    if (progBtnPressed) {
        init_sensors();
        progBtnPressed = false;
        ESP_LOGI(TAG, "Programmable button pressed while booting, dropping into REPL");
        CLI::repl(Serial, Serial);
        ESP_LOGI(TAG, "Continuing");
    }

    uint16_t measurement_interval_secs = config.getMeasureInterval();
    uint16_t uplink_interval_secs = config.getUplinkInterval();

    if (uplink_interval_secs < measurement_interval_secs) {
        ESP_LOGE(TAG, "Measurement interval (%u) must be <= uplink interval "
                      "(%u). Resetting config to default values.", measurement_interval_secs, uplink_interval_secs);
        config.reset();
    }

    if (uplink_interval_secs % measurement_interval_secs != 0) {
        ESP_LOGE(TAG, "Measurement interval (%u) must be a factor of uplink "
                      "interval (%u). Resetting config to default "
                      "values.", measurement_interval_secs, uplink_interval_secs);
        config.reset();
    }

    // Assuming the measure interval is a factor of the uplink interval,
    // boots_between_uplinks is the number of boots between uplinks.
    uint16_t boots_between_uplinks = uplink_interval_secs / measurement_interval_secs;

    // If the current boot cycle is a multiple of boots_between_uplinks, then this boot cycle
    // should do an uplink.
    bool is_uplink_cycle = config.getBootCount() % boots_between_uplinks == 0;

    ESP_LOGI(TAG, "Boot count: %lu, measurement interval: %u, "
                  "uplink interval: %u, uplink_interval_secs/measurement_interval_secs: %u, uplink this cycle: %d",
             config.getBootCount(), measurement_interval_secs, uplink_interval_secs, boots_between_uplinks, is_uplink_cycle);

    if (is_uplink_cycle) {
        if ( ! connect_to_internet()) {
            ESP_LOGW(TAG, "Could not connect to the internet on an uplink cycle. This is now a measurement-only cycle");
            log_to_sdcard("[E] cti failed, only measuring");
            is_uplink_cycle = false;
        }
    }

    log_to_sdcard("init_sensors");
    init_sensors();
    log_to_sdcard("sensor_task");
    sensor_task();
    log_to_sdcard("back from sensor_task");

    if (is_uplink_cycle) {
        log_to_sdcard("send_messages");
        send_messages();
        log_to_sdcard("back from send_messages");
        // If a config script turned up, run it now.
        if (script != nullptr) {
            log_to_sdcard("Running config script");
            log_to_sdcard(script);

            ESP_LOGI(TAG, "Running config script\n%s", script);
            StreamString scriptStream;
            scriptStream.print(script);
            // Ensure the script ends with an exit command.
            scriptStream.print("\nexit\n");
            free(script);
            CLI::repl(scriptStream, Serial);

            log_to_sdcard("Finished script");
        }
    }

    shutdown();

    // NOTE: Because the ESP32 effectively reboots after waking from deep sleep the ESP32 internal tick counter
    // always starts at 0. This means simply getting the value of millis() here is sufficient to get an idea of
    // how long it took to get here. There is no need to save the millis() at the top of the function and do a
    // subtraction here.
    uint64_t measurement_interval_ms = measurement_interval_secs * 1000;
    uint64_t delta_ms = 0;
    uint64_t sleep_time_us = 0;
    uint64_t setup_duration_ms = millis();

    if (setup_duration_ms > measurement_interval_ms) {
        ESP_LOGW(TAG, "run time > measurement interval");
        delta_ms = setup_duration_ms - measurement_interval_ms;
        while (delta_ms > measurement_interval_ms) {
            delta_ms = setup_duration_ms - measurement_interval_ms;
            setup_duration_ms = setup_duration_ms - measurement_interval_ms;
            ESP_LOGW(TAG, "skipping an interval, setup_duration_ms now = %llu, delta_ms = %llu", setup_duration_ms, delta_ms);
        }

        sleep_time_us = (measurement_interval_ms - delta_ms) * 1000;
    } else {
        delta_ms = measurement_interval_ms - setup_duration_ms;
        // Catch the case of the run time being exactly the measurement interval. With the current
        // code structure there is no simple way of just running the whole thing again, so sleep for 1ms
        // and reboot.
        if (delta_ms < 1) {
            delta_ms = 1;
        }

        sleep_time_us = delta_ms * 1000;
    }

    // A final sanity check.
    if (sleep_time_us > (measurement_interval_ms * 1000)) {
        ESP_LOGE(TAG, "sleep time us %llu > measurement interval us %llu", sleep_time_us, (measurement_interval_ms * 1000));
        sleep_time_us = measurement_interval_ms * 1000;
    }

    ESP_LOGI(TAG, "Unadjusted sleep_time_us = %llu", sleep_time_us);
    sleep_time_us = (uint64_t)((float)sleep_time_us * config.getSleepAdjustment());
    ESP_LOGI(TAG, "Adjusted sleep_time_us = %llu", sleep_time_us);

    float f_s_time = (float)sleep_time_us / 1000000.0f;
    ESP_LOGI(TAG, "Run took %llu ms, going to sleep at: %s, for %.2f s", setup_duration_ms, iso8601(), f_s_time);
    Serial.flush();

    esp_sleep_enable_timer_wakeup(sleep_time_us);
    esp_deep_sleep_start();
}

void shutdown(void) {
    ESP_LOGI(TAG, "Shutting down");

    SPIFFS.end();

    if (r5_ok) {
        log_to_sdcard("r5.modulePowerOff");
        r5.modulePowerOff();
    } else {
        log_to_sdcard("[E] r5_ok was false");
    }

    cat_m1.power_supply(false);
    delay(20);
    BatteryMonitor::sleep();
    SolarMonitor::sleep();

    disable12V();
    delay(20);

    log_to_sdcard("power down SD card");
    SD.end();
    digitalWrite(SD_CARD_ENABLE, LOW);

    // Use the handle to delete the task.
    if (xHandle != nullptr) {
        vTaskDelete(xHandle);
    }
}

void loop() {
}

#ifdef __cplusplus
extern "C" {
#endif
/**
 * @brief Allow digitalWrite to be used for pins on the IO expander.
 *
 * This function overrides the default digitalWrite provided by the Arduino core so
 * we can use it with pins on the IO expander IC. If the pin number > 0x80 then the
 * bits > 0x80 are masked off and the request is sent to the IO expander library.
 *
 * For example, passing in pin 0x82 will ask the IO expander library to write to its
 * pin 2.
 *
 * @param pin the GPIO to write to; values > 0x80 will be handled by the IO expander library
 * after masking off the bits > 0x80.
 * @val HIGH or LOW
 */
extern void digitalWrite(uint8_t pin, uint8_t val) {
    if (pin & 0x80) {
        io_expander.output(ARDUINO_TO_IO(pin), val == HIGH ? TCA9534::H : TCA9534::L);
    } else {
        gpio_set_level((gpio_num_t) pin, val);
    }
}
#ifdef __cplusplus
}
#endif

#define SLOW_CLK_CAL_CYCLES 2048

/**
 * \brief Switch the RTC clock source to the external crystal.
 *
 * This code is copied from the ESP32 Ardiuno core, and slightly modified so it only tries
 * to use the external crystal before falling back to the 150 kHz internal oscillator.
 */
void select_rtc_slow_clk(void)
{
    rtc_slow_freq_t rtc_slow_freq = RTC_SLOW_FREQ_32K_XTAL;
    uint32_t cal_val = 0;
    /* number of times to repeat 32k XTAL calibration
     * before giving up and switching to the internal RC
     */
    int retry_32k_xtal = 5;

    do {
        /* 32k XTAL oscillator needs to be enabled and running before it can
         * be used. Hardware doesn't have a direct way of checking if the
         * oscillator is running. Here we use rtc_clk_cal function to count
         * the number of main XTAL cycles in the given number of 32k XTAL
         * oscillator cycles. If the 32k XTAL has not started up, calibration
         * will time out, returning 0.
         */
        ESP_LOGI(TAG, "waiting for 32k oscillator to start up");
        rtc_clk_32k_enable(true);

        // When SLOW_CLK_CAL_CYCLES is set to 0, clock calibration will not be performed at startup.
        if (SLOW_CLK_CAL_CYCLES > 0) {
            cal_val = rtc_clk_cal(RTC_CAL_32K_XTAL, SLOW_CLK_CAL_CYCLES);
            if (cal_val == 0) {
                if (retry_32k_xtal-- > 0) {
                    continue;
                }
                ESP_LOGW(TAG, "32 kHz XTAL not found, switching to internal 150 kHz oscillator");
                rtc_slow_freq = RTC_SLOW_FREQ_RTC;
            }
        }

        rtc_clk_slow_freq_set(rtc_slow_freq);

        if (SLOW_CLK_CAL_CYCLES > 0) {
            /* TODO: 32k XTAL oscillator has some frequency drift at startup.
             * Improve calibration routine to wait until the frequency is stable.
             */
            cal_val = rtc_clk_cal(RTC_CAL_RTC_MUX, SLOW_CLK_CAL_CYCLES);
        } else {
            const uint64_t cal_dividend = (1ULL << RTC_CLK_CAL_FRACT) * 1000000ULL;
            cal_val = (uint32_t) (cal_dividend / rtc_clk_slow_freq_get_hz());
        }
    } while (cal_val == 0);

    ESP_LOGI(TAG, "RTC_SLOW_CLK calibration value: %d", cal_val);
    esp_clk_slowclk_cal_set(cal_val);
}

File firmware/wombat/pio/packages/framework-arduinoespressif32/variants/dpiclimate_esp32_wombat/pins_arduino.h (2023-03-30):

#ifndef Pins_Arduino_h
#define Pins_Arduino_h

#include <stdint.h>

#define USB_MANUFACTURER "DPI Climate"
#define USB_PRODUCT "DPI Climate ESP32 Wombat"
#define USB_SERIAL ""

#define EXTERNAL_NUM_INTERRUPTS 46
#define NUM_DIGITAL_PINS        48
#define NUM_ANALOG_INPUTS       20

#define analogInputToDigitalPin(p)  (((p)<20)?(analogChannelToDigitalPin(p)):-1)
#define digitalPinToInterrupt(p)    (((p)<48)?(p):-1)
#define digitalPinHasPWM(p)         (p < 46)

// 0x81 means P1 on the IO expander IC. 0x81 for newer boards, 0x84 for the original test boards.
static const uint8_t LED_BUILTIN = 0x81;
#define BUILTIN_LED  LED_BUILTIN // backward compatibility

static const uint8_t TX = 34;
static const uint8_t RX = 33;

#define TX1 GPIO_NUM_26
#define RX1 GPIO_NUM_22

static const uint8_t SDA = 37;
static const uint8_t SCL = 10;

static const uint8_t MOSI  = 18;
static const uint8_t MISO  = 19;
static const uint8_t SCK   = 5;
static const uint8_t SS    = 4;

static const uint8_t SDI_12 = 4;
static const uint8_t PIEZO = 28;

#endif /* Pins_Arduino_h */

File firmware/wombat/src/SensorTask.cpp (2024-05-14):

#include <Arduino.h>
#include "SensorTask.h"
#include "DeviceConfig.h"
#include "Utils.h"
#include "globals.h"
#include "ulp.h"
#include "sd-card/interface.h"
#include "power_monitoring/battery.h"
#include "power_monitoring/solar.h"
#include <esp_log.h>

#include <freertos/FreeRTOS.h>

#include <dpiclimate-12.h>
#include <SPIFFS.h>

#define TAG "sensors"

#define SDI12_DATA_PIN  GPIO_NUM_21

SDI12 sdi12(SDI12_DATA_PIN);
DPIClimate12 dpi12(sdi12);

/// The ID information of each sensor found on the SDI-12 bus.
sensor_list sensors;

///
/// \brief Scans the SDI-12 bus and fills in the sensors object.
///
void init_sensors(void) {
    sdi12.begin();
    dpi12.scan_bus(sensors);
    sdi12.end();

    log_to_sdcardf("Found %u sensors", sensors.count);

    ESP_LOGI(TAG, "Found %u sensors", sensors.count);
    for (uint8_t i = 0; i < sensors.count; i++) {
        ESP_LOGI(TAG, "%s", &sensors.sensors[i]);
    }
}


/// \brief Read a single SDI-12 sensor and add its values to timeseries_array.
bool read_sensor(const char addr, JsonArray& timeseries_array) {
    // Will be true if the sensor is read using information from the sensor definitions. If that fails
    // and this is false after the attempt, then a standard measure command will be issued as a fall-back.
    bool have_reading = false;

    // If the sensor definition gives a C command this will be true.
    bool is_concurrent = false;

    // If the 3rd character of the command from a sensor definition is '0' < ch <= '9' then this
    // will be set to true to indicate an 'additional' measure or concurrent command is used.
    bool is_additional = false;

    std::vector<double> plain_values;
    size_t sensor_idx = 0;
    for (; sensor_idx < sensors.count; sensor_idx++) {
        if (addr == sensors.sensors[sensor_idx].address) {
            break;
        }
    }

    if (sensor_idx >= sensors.count) {
        ESP_LOGE(TAG, "SDI-12 sensor %c not found", addr);
        return false;
    }

    JsonObjectConst s = getSensorDefn(sensor_idx, sensors);
    if (s) {
        JsonArrayConst read_cmds = s["read_cmds"];
        const char* value_mask = s["value_mask"];

        // This loop issues all the read and data commands for the sensor, and gathers the values
        // that pass the value mask into the values vector.
        for (size_t cmd_idx = 0; cmd_idx < read_cmds.size(); cmd_idx++) {
            const char *crc = read_cmds[cmd_idx];

            is_concurrent = crc[1] == 'C';
            is_additional = crc[2] > '0' && crc[2] <= '9';

            int num_values = 0;

            if (is_concurrent) {
                if (is_additional) {
                    ESP_LOGI(TAG, "Concurrent (additional)");
                    num_values = dpi12.do_additional_concurrent(sensors.sensors[sensor_idx].address, crc[2]);
                } else {
                    ESP_LOGI(TAG, "Concurrent");
                    num_values = dpi12.do_concurrent(sensors.sensors[sensor_idx].address);
                }
            } else {
                bool wait_full_time = s["ignore_sr"];
                if (is_additional) {
                    ESP_LOGI(TAG, "Measure (additional), wait_full_time: %d", wait_full_time);
                    num_values = dpi12.do_additional_measure(sensors.sensors[sensor_idx].address, crc[2]);
                } else {
                    ESP_LOGI(TAG, "Measure, wait_full_time: %d", wait_full_time);
                    num_values = dpi12.do_measure(sensors.sensors[sensor_idx].address, wait_full_time);
                }
            }

            for (int value_idx = 0; value_idx < num_values; value_idx++) {
                double value = dpi12.get_value(value_idx).value;
                char mask = '1'; // Default to including the value.
                if (value_mask != nullptr && strnlen(value_mask, num_values) >= value_idx + 1) {
                    mask = value_mask[value_idx];
                }

                if (mask == '1') {
                    plain_values.push_back(value);
                } else {
                    ESP_LOGI(TAG, "Skipping value %d due to value mask", value_idx);
                }
            }
        }

        JsonArrayConst labels = s["labels"];

        // This loop runs through the kept values, finds or generates a label for them, and
        // appends them to the timeSeries array of the JSON document.
        for (int value_idx = 0; value_idx < plain_values.size(); value_idx++) {
            auto ts_entry = timeseries_array.add<JsonObject>();
            JsonVariantConst label = labels[value_idx];
            if (label) {
                String generated_label(sensors.sensors[sensor_idx].address - '0');
                generated_label += "_";
                generated_label += label.as<String>();
                ts_entry["name"] = generated_label;
            } else {
                snprintf(g_buffer, sizeof(MAX_G_BUFFER), "%c_V%d", sensors.sensors[sensor_idx].address, value_idx);
                ts_entry["name"] = g_buffer;
            }

            ts_entry["value"] = plain_values.at(value_idx);
        }

        have_reading = true;
    }

    if ( ! have_reading) {
        ESP_LOGI(TAG, "No sensor definition found, performing fallback plain measure command.");
        // Setting wait_full_time to true because we don't know what type of sensor we're reading
        // in this code so try to handle those sensors that send a service request but then don't
        // send the data immediately afterwards.
        int res = dpi12.do_measure(sensors.sensors[sensor_idx].address, true);
        if (res > 0) {
            for (uint8_t value_idx = 0; value_idx < res; value_idx++) {
                auto ts_entry = timeseries_array.add<JsonObject>();
                snprintf(g_buffer, MAX_G_BUFFER, "%c_V%u", sensors.sensors[sensor_idx].address, value_idx+1);
                ts_entry["name"] = g_buffer;
                ts_entry["value"] = dpi12.get_value(value_idx).value;
            }
        } else {
            ESP_LOGE(TAG, "Failed to read sensor");
            return false;
        }
    }

    return true;
}
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

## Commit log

2022-09-05 working on stm32 debugging and accessory components
    [node.kicad_sch]
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2022-09-12 added M.2 connector. OneWire, SDI-12 and SD-Card interfaces. USB charger for single 18650 battery.
    [1043.step, ABS05-32.768KHZ-9-T.step, AOD417.step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]
2022-09-13 started on PCB for mainboard
    [DS04-254-2-02BK-SMT.step, SODFL3718X108N.step, SS34LW_RVG.step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]
2022-09-14 up to pcb trace routing of circuit board, added boot and reset button
    [9774025151R.step, nrf52840-breakout.kicad_pcb, nrf52840-breakout.kicad_sch]
2022-09-15 finalised board routing for first prototype
    [472192001.stp, TBP02R2-381-02BE.step, TBP02R2-381-03BE.step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]
2022-09-23 added basic feather m0 node. Features: no solar, d-cell battery, 12 V boost, sd-card, SDI12, i2c, wind speed and dir, reverse polarity protection and indicator
    [472192001.stp, AOD417.step, BHDL.step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]
2022-09-28 initial commit of NRF52840 firmware testing
    [CONUFL001-SMD-T.step, PTS636_SM43J_SMTR_LFS.step, RFM95W-915S2.step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]
2022-10-03 updated electronics file structure for next revisions
    [1043.step, 472192001.stp, 9774025151R.step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]
2022-10-04 added version 0.2 of the motherboard (changed to MicroMod form factor, different buttons, smaller and more solid USB-C connector, increased the resistor for charge detection to reduce LED brightness)
    [1043.step, 472192001.stp, 9774025151R.step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]
2022-10-05 continued work on cat-m1 m.2 connector board
    [AP7331-18WG-7.step, CONUFL001-SMD-T.step, PTS636_SM43J_SMTR_LFS.step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]
2022-10-06 removed 3.3v to 1.8v reg from sara-m410m board and approved for pcb routing, added m.2 connector pcb for pycom boards under duel communications board
    [cat-m1-micromod.kicad_sch, pycom-micromod.kicad_pcb, pycom-micromod.kicad_sch]
2022-10-10 finalised cat-m1 m.2 connector board for communications
    [FBMH2012HM221-TV.step, SIM8060-6-0-14-00-A.stp, SOT-23-6_AOS.step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]
2022-10-11 Basic LoRaWAN, anemometer, SD-card functions.
    [472192001.stp, AOD417.step, BHDL.step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]
2022-10-12 updated to re-align with master
    [1043.step, 1048P--3DModel-STEP-56544.step, 472192001.stp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]
2022-10-17 added bluetooth and suppport for esp32 micromod, also LoRaWAN working with RFM95W
2022-10-17 Added uplink jitter, standby when LMIC is in OP_POLL mode, wind direction now averaged over the same period as the speed is calculated, and the std dev of the wind direction is calculated.
    [main.cpp]
2022-10-19 added proof of concept for ble data transfer. i.e. battery status information through random ble app
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2022-10-26 Recording more data to SD card, initial uplink works again, added WDT, disabled command line to handle RX line noise on current board revision.
    [main.cpp]
2022-11-02 realign with master branch before kangaroo board is split into seperate repo
    [ABS07AIG-32.768KHZ-T.step, ESP32-WROOM-32E__16MB_.step, FBMH2012HM221-TV.step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]
2022-11-08 added mounting circuit board and updated motherboard for next itteration
    [IND2_SRP4020TA-R56M_BRN.step, MCP3221A0T-E_OT.step, T4041037031-000.step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]
2022-11-08 removed unused circuit board and placed them in misc-electronics repository
    [1043.step, 1048P--3DModel-STEP-56544.step, 472192001.stp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]
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2022-11-10 spelling mistake in variants folder
    [pins_arduino.h]
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2022-11-14 added cat-m1 basic interface
    [cat_m1.kicad_sch, motherboard-mini.kicad_pcb, motherboard-mini.kicad_sch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]
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2022-11-16 new board version sent for production, termed 'wombat' and breakout board
    [0685P2000-01.step, 1049P.step, 20021221-00010.step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]
2022-11-17 added component information for all items in motherboard
    [cat_m1.kicad_sch, motherboard-mini.kicad_sch, peripherals.kicad_sch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]
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2022-12-02 New config commands, MQTT test code, bug fixes.
    [CLI.cpp, DeviceConfig.cpp]
2022-12-06 WIP: sdi12 commands now have OK/ERROR status after them, first cut at sensor defns but not working yet.
    [DeviceConfig.cpp]
2022-12-08 updated usb-to-uart, fixed some pin label issues
    [motherboard-mini.kicad_pcb, motherboard-mini.kicad_sch, peripherals.kicad_sch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]
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2022-12-12 Bug fixes in sensor reading code.
    [SensorTask.cpp]
2022-12-14 new version sent for manufacture, updated component positioning, removed level shifter on SDI-12 line, re routed the solar charge circuit
    [cat_m1.kicad_sch, motherboard-mini.kicad_pcb, motherboard-mini.kicad_sch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]
2022-12-15 Load config before going to CLI to avoid overwriting settings with default values.
    [main.cpp]
2022-12-15 Fixed endless loop when skipping measurement periods.
    [main.cpp]
2022-12-15 Fixed unknown SDI-12 sensor value naming.
    [SensorTask.cpp]
2022-12-20 Added ULP pulse counter, patched ulp-tool to work with current environment, cleaned up ntp code, added a fix to avoid invalid SDI-12 ID responses, set CPU speed to 80MHz.
    [SensorTask.cpp, Utils.cpp, main.cpp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]
2022-12-20 removed brownout detection when starting up modem
    [main.cpp]
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2023-01-09 updating readme
    [20021221-00010.step, 3221-10-0100-00.STEP, SOT-23F.step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]
2023-01-09 refactored schemematics and added pdf previews for readme
    [cat_m1.kicad_sch, motherboard-mini.kicad_sch, peripherals.kicad_sch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]
2023-01-09 renamed kicad project
    [0685P2000-01.step, 1043.step, 1049P.step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]
2023-01-17 fixed unexposed copper pad on inductor and added zipped step file of the motherboard
    [cat_m1.kicad_sch, enviro-node.kicad_pcb, enviro-node.kicad_sch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]
2023-01-17 added gerber files for all electronics including zipped files
    [breakout-B_Cu.gbr, breakout-B_Mask.gbr, breakout-B_Paste.gbr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]
2023-01-17 Fixes for issue #20 and issue #21.
    [Utils.cpp, uplinks.cpp]
2023-01-17 added footprint positions for PCB assembly
    [enviro-node.kicad_pcb]
2023-01-19 updated electronics for production
    [cat_m1.kicad_sch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]
2023-01-20 Fixed string termination problem when setting mqtt topic, added commands to help debug mqtt connections.
    [uplinks.cpp]
2023-01-23 bluetooth power monitoring working, using character arrays now. fixed issue where bluetooth was being initialised twice
    [main.cpp]
2023-03-06 Config download, time from mobile network, clock skew, reboot command.
    [CLI.cpp, Utils.cpp, main.cpp]
2023-03-20 Added code to feed the RTC clock from the external crystal, and a pre-build script to generate a firmware ID. Fixed a couple of typos.
    [DeviceConfig.cpp, Utils.cpp, main.cpp]
2023-03-20 Added ESP32 partition defns, gen_version_h.py removes now version.h and checks repo status.
    [ota_partitions.csv]
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2023-03-23 Added mounting bracket files.
    [long_bracket.f3z, short_bracket.f3z]
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2023-05-02 PTS-25319-C 3D offset bracket
    This 3D bracket will level up the box for CNC drilling or hand drilling
    [Breakoutbox holder Final.stl]
2023-05-02 PTQ-11044 3D offset bracket
    - Only fit wombat PVC board
    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
    [PVC WB board holder final.stl]
2023-05-02 3D removable clip
    Aim to stabilised batteries in the battery case.
    Decreases batteries movement.
    [Battery holder clip V2.stl]
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2023-07-10 Simplified sleep time calcs, fixed some problems with downloading and running config scripts, added length checking to MQTT publish, include SDI-12 info in source_ids.
    [ota_partitions.csv]
2023-07-11 Stop trying to send MQTT messages after login fails. Allow forced OTA updates with 'config ota 1`. Execute config scripts after messages have been sent and logged out of MQTT. CLI loop now takes sepe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
    [CLI.cpp, SensorTask.cpp, main.cpp]
2023-07-12 Added core dump partition to avoid error messages on boot.
    [ota_partitions.csv]
2023-07-12 Fixed most errors on the 1.0.1 board revision, resolved ERC errors. No PCB work in this commit.
    1. Added a solder jumper in-line with with the USB/UART bridge TX pin. If this jumper is
    broken then the RX pin on the UART header can be used. Note the TX/RX discrepancy here is
    not a typo.
    2. Changed the USB/UART bridge power supply wiring so it will not try to power the board
    when a USB cable is plugged in. Batteries must be present.
    3. The battery monitor VS/A0/A1 pins put back to +3.3v rather than VBAT so it can be read
    while the battery is being charged via the solar panel.
    4. Moved the main 3.3v regulator to after the power switch so it is not running all the time.
    5. Revert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
    [cat_m1.kicad_sch, enviro-node.kicad_sch, peripherals.kicad_sch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]
2023-07-12 Updated schematic date and revision number. Removed individual designer names because the whole team is involved now.
    [cat_m1.kicad_sch, enviro-node.kicad_sch, peripherals.kicad_sch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]
2023-07-12 Fixed a schematic wire join on JP1.
    [enviro-node.kicad_sch]
2023-07-12 Moved +3.3v regulator back to battery side of switch to reduce PCB layout work.
    Replaced C17 & C23 with 0.1uF caps to adhere to datasheet recommendations.
    All schematic changes put onto the PCB.
    [cat_m1.kicad_sch, enviro-node.kicad_pcb, enviro-node.kicad_sch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]
2023-07-12 Last commit did not get changes to C17 & C23, changed them again to 0.1uF.
    Changed footprint of optional pull-up/pull-down R42 & R43 to be through-hole.
    [cat_m1.kicad_sch, enviro-node.kicad_pcb, enviro-node.kicad_sch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]
2023-07-12 Updated gerber files & BOM.
    [enviro-node-B_Cu.gbr, enviro-node-B_Mask.gbr, enviro-node-B_Paste.gbr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]
2023-07-12 Breakout board main connector now in same order as on the Wombat board.
    [breakout-B_Cu.gbr, breakout-B_Mask.gbr, breakout-B_Paste.gbr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]
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2023-07-18 - Resolved issue #46 - Added firmware version, repo branch, repo status and commit id to source_ids
    [SensorTask.cpp]
2023-07-24 Changed firmware reporting format to avoid JSON message length going over 1024 bytes on SMP nodes. Changed solar and battery voltage methods to round values to 2 decimal places.
    Removed BT code, added an MQTT login if no messages were uplinked so config changes are still received.
    Added SIM CCID to source_ids object.
    [CLI.cpp, SensorTask.cpp, uplinks.cpp]
2023-08-21 Added code to publish long MQTT messages from the modem filesystem. Changed EnviroPro SDI-12 definition to use short model ID due to changes in dpiclimate-12 library.
    Updated pio installer URL.
    Fixed issue #56. Added a simple timeout task to try and recover from what seem to be busy loops in the field.
    Fixed issue #52. A cosmetic logging message fix to show the year properly.
    Fixed issue #45. Can now update sdi12defs.json remotely.
    [DeviceConfig.cpp, Utils.cpp, main.cpp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]
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2023-08-25 Reduced the chunck file size to 0.25 of the free space on the modem filesystem. The modem seems to work better with this. Do not try to transfer a file if < 64K free on the modem filesystem. Remove t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
    Tweak to log messages at bottom of upload loop.
2023-08-30 Updated some SD card logging messages to make errors easier to find.
    [SensorTask.cpp, Utils.cpp, main.cpp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]
2023-09-12 Added SD card free space to message, msg upload now checks if connect_to_internet fails, connect_to_internet fast path now checks first digit of IP address as an extra check the modem is connected to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
    [SensorTask.cpp, Utils.cpp, uplinks.cpp]
2023-10-05 Added a second message carrying device & comms info. Removed support for sending MQTT messages from modem filesystem - that needs more work. Added constants for CLI command results. Fixed c1 pwr 0 co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
    Moved voltage readings to 2nd message, simplified network registration wait loop and extended wait time to 90s.
    [CAT_M1.cpp, SensorTask.cpp, Utils.cpp]
2023-10-15 Fixed issues #60, #61.
    [SensorTask.cpp, Utils.cpp]
2023-10-24 Reverted to using NTP for network time. The mobile network time is not reliable.
    [CAT_M1.cpp, Utils.cpp, ntp.cpp]
2024-05-15 Tweaked the wait_for_at function to handle the initial 0x00 character on the modem serial line to avoid a modem reboot caused by the previous change to this function.
    [Utils.cpp]
2025-08-29 Now checking for NTP errors.
    Fixed include copy/paste errors in SPIFFS CLI command.
    Skip trying to upload empty message files, fixed truncation of lines when catting SPIFFS files, fixed a CLI help typo.
    [CLI.cpp, ntp.cpp, uplinks.cpp]

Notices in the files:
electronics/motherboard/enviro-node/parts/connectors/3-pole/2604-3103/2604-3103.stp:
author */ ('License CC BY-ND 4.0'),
